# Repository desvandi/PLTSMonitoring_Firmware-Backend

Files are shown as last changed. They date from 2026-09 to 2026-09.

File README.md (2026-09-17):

# PLTS Monitoring — Firmware, Backend GAS, & Toolkit

**Firmware Version:** v1.9.3 · **Backend GAS:** WAVE-7+ · **License:** MIT
**Status:** Development (v1.9.x INA219 dynamic gain switching — hardware acceptance pending; v1.9.3 menutup REL-03/REL-04: build kini reproducible)
**Repositori kembar (PWA frontend):** [desvandi/PLTSMonitoring_PWA](https://github.com/desvandi/PLTSMonitoring_PWA)

---

## Daftar Isi

1. [Gambaran Proyek](#1-gambaran-proyek)
2. [Arsitektur Sistem](#2-arsitektur-sistem)
3. [Struktur Repositori](#3-struktur-repositori)
4. [Hardware Requirements](#4-hardware-requirements)
5. [Firmware v1.9.x — INA219 Dynamic Gain Switching](#5-firmware-v19x--ina219-dynamic-gain-switching)
6. [Panduan Deployment Lengkap](#6-panduan-deployment-lengkap)
7. [Konfigurasi Firmware](#7-konfigurasi-firmware)
8. [Backend Google Apps Script](#8-backend-google-apps-script)
9. [CI/CD Pipeline](#9-cicd-pipeline)
10. [Release Engineering](#10-release-engineering)
11. [Hardware Acceptance](#11-hardware-acceptance)
12. [Testing](#12-testing)
13. [Troubleshooting](#13-troubleshooting)
14. [Changelog](#14-changelog)

---

## 1. Gambaran Proyek

Proyek ini adalah sistem monitoring PLTS (Pembangkit Listrik Tenaga Surya) berbasis ESP32 untuk baterai 48V LiFePO4. Sistem mencakup telemetri lengkap (tegangan, arus, daya, SOC, suhu, BMS), alarm real-time, kontrol relay 8-channel, OTA update dengan signature verification, dan push notification.

### Dua Subsistem

| Subsistem | Fungsi | Komponen |
|---|---|---|
| **PLTS Monitor** (dasbor) | Telemetri → Google Apps Script → PWA Next.js; realtime MQTT opsional | `firmware/`, `firmware-generic/`, `code.gs/`, `scripts/` |
| **Push-Alarm MonitorIoT** | Alarm sensor via Web Push terenkripsi (VAPID + aes128gcm) | `push-alarm/` |

### Prinsip Inti

- **Never fabricate certainty** — setiap pengukuran membawa `value/unit/quality/source/timestamp`; sensor gagal → `null` (bukan `0`)
- **Fail-closed** — production build menolak konfigurasi tanpa signature/CA/allowlist
- **Immutable releases** — setiap release ditandatangani GPG + Ed25519, provenance binding machine-verifiable

---

## 2. Arsitektur Sistem

```
┌─────────────────────────────────────────────────────────────┐
│                     ESP32-WROOM-32                          │
│                                                             │
│  ┌──────────┐  ┌──────────┐  ┌──────────┐  ┌──────────┐   │
│  │ INA219   │  │ ADC GPIO │  │ SHT31    │  │ PCF8574  │   │
│  │ (Arus)   │  │ (Tegang) │  │ (Suhu)   │  │ (Relay)  │   │
│  └────┬─────┘  └────┬─────┘  └────┬─────┘  └────┬─────┘   │
│       │ I²C         │ ADC         │ I²C         │ I²C      │
│  ┌────┴─────────────┴─────────────┴─────────────┴────┐    │
│  │              Firmware v1.9.3                      │    │
│  │  • Dynamic PGA Switching (±80mV / ±160mV)        │    │
│  │  • Voltage Divider 190kΩ/10kΩ (20:1)             │    │
│  │  • 8-Channel Relay Controller (E-WAVE)           │    │
│  │  • Reproducible Build (deterministic identity)   │    │
│  │  • OTA Manager (Ed25519 + SHA-256)               │    │
│  │  • MQTT TLS / HTTPS telemetry                    │    │
│  └───────────────────┬──────────────────────────────┘    │
│                      │                                    │
└──────────────────────┼────────────────────────────────────┘
                       │
              ┌────────┴────────┐
              │   WiFi / MQTT   │
              └────────┬────────┘
                       │
          ┌────────────┴────────────┐
          │                         │
    ┌─────┴─────┐           ┌──────┴──────┐
    │  HTTPS    │           │   MQTT TLS  │
    │  POST     │           │  (opsional) │
    └─────┬─────┘           └──────┬──────┘
          │                        │
    ┌─────┴────────────────────────┴─────┐
    │     Google Apps Script (Backend)    │
    │  • Telemetry ingest (HMAC auth)     │
    │  • Google Sheets logging            │
    │  • Telegram alerts                 │
    │  • OTA command dispatch             │
    └─────────────┬───────────────────────┘
                  │
           ┌──────┴──────┐
           │  PWA (Vercel) │
           │  Next.js 16   │
           └───────────────┘
```

### Topologi Operasi

| Topologi | Transport | Backend | Use Case |
|---|---|---|---|
| **A (Dasbor)** | HTTPS POST | Google Apps Script + Google Sheets | Standby/standalone tanpa internet real-time |
| **B (Realtime)** | MQTT TLS | Broker MQTT + PWA subscribe | Real-time dashboard dengan live updates |

---

## 3. Struktur Repositori

```
PLTSMonitoring_Firmware-Backend/
├── firmware/                    # Modular production firmware (v1.9.3)
│   ├── Core/                    #   Config.h, Types.h, Globals.h, Common.h
│   ├── Drivers/                 #   INA219, ADC, SHT31, ACS712, PCF8574, RTC
│   ├── Services/                #   OtaManager, RelayController, AlarmRegistry, dll
│   ├── Network/                 #   MQTT transport, telemetry publisher, OTA handler
│   ├── Web/                     #   HTTP server, REST handlers (status, OTA, config, dll)
│   ├── Storage/                 #   NVS config store, filesystem
│   ├── Utils/                   #   Crypto (Ed25519), CRC, I2C recovery, JSON
│   ├── AI/                      #   GasAdvisor (HMAC-signed AI insights)
│   ├── Comm/                    #   BMS protocols (CAN, Modbus RTU/TCP)
│   ├── firmware_v1.ino          #   Main entry point
│   ├── platformio.ini           #   Build configs: development, staging, production
│   └── partitions_ota_1mb5.csv  #   OTA partition table
│
├── firmware-generic/            # Generic firmware (ESP Web Tools flashing)
│   ├── src/
│   │   └── plts_firmware_v1.ino #   Single-file firmware (same features, simpler build)
│   ├── manifest.json            #   ESP Web Tools manifest (v1.9.3)
│   ├── platformio.ini
│   └── bin/                     #   CI-built binaries (gitignored)
│
├── code.gs/                     # Google Apps Script backend
│   └── Code.gs                  #   doPost handler, telemetry ingest, HMAC, OTA dispatch
│
├── push-alarm/                  # MonitorIoT Push-Alarm subsystem
│   ├── gas/                     #   GAS Web Push core (Code.gs, WebPushCore.gs)
│   ├── firmware/                #   Alarm firmware (MonitorIoT_Firmware.ino)
│   ├── tools/                   #   VAPID key gen, deploy config, audit tools
│   └── tests/                   #   Cross-audit, smoke, webpush-core tests
│
├── scripts/                     # Release engineering + testing
│   ├── sign_firmware.py         #   Ed25519 firmware signing
│   ├── generate_provenance.py   #   Release provenance (release.json, provenance.json)
│   ├── generate_canonical_manifest.py  # Schema 2.0 OTA manifest
│   ├── generate_provenance_binding.py  # Explicit provenance chain
│   ├── release_gate.py          #   Master release gate (strict mode)
│   ├── release_firmware_generic.py    # Generic tree release builder
│   ├── verify_tag_signature.py  #   GPG tag verification (P0-1)
│   ├── verify_hardware_acceptance.py  # HW acceptance gate (P0-2)
│   ├── verify_ota_evidence.py   #   OTA physical test gate
│   ├── verify_ina219_hardware_acceptance.py  # INA219 HW acceptance (v1.9.x)
│   ├── decode_ina219_config.py  #   INA219 register decoder (canonical)
│   ├── test_ina219_config_registers.py  # INA219 register unit test
│   ├── test_*.py / test_*.js    #   30+ test scripts (unit, property, contract, bench)
│   └── ...
│
├── docs/                        #   Hanya data fungsional (dibaca skrip/CI)
│   ├── hardware-revisions.json  #     Registry revisi hardware (verify_ota_evidence dkk.)
│   ├── hardware-acceptance/     #   Evidence + template verifikasi (release gate P0-2)
│   │   ├── v1.8.0.json          #     Filled-in evidence (verdict=PASS)
│   │   ├── v1.8.0.template.json #     Template v1.8.0
│   │   ├── v1.9.2.template.json #     Template v1.9.2
│   │   └── v1.9.3.template.json #     Template v1.9.3 (REL-03: SHA byte-exact evidence)
│   └── ota-physical-test/       #   Template uji fisik OTA (verify_ota_evidence)
│       ├── v1.8.0.template.json
│       └── v1.9.3.template.json
│
├── .github/workflows/
│   └── build-firmware.yml       #   CI: test → build → sign → gate → tag-verify → hw-verify → release
│
└── README.md                    # File ini
```

---

## 4. Hardware Requirements

### Komponen Utama

| Komponen | Spesifikasi | Fungsi |
|---|---|---|
| **ESP32-WROOM-32** | Dual-core 240MHz, 4MB Flash, WiFi+BT | Mikrokontroler utama |
| **INA219** | I²C 0x40, shunt 100A/75mV (R=0.75mΩ) | Pengukuran arus baterai (1A–150A) |
| **Shunt Resistor** | 100A/75mV (0.75mΩ) | Low-side current sensing |
| **Voltage Divider** | R1=190kΩ, R2=10kΩ (ratio 20:1) + 0.1µF cap | Pembacaan tegangan baterai 42–57.5V via ADC |
| **SHT31** | I²C, ±0.3°C, ±2%RH | Suhu + kelembaban ambient |
| **PCF8574** | I²C expander 8-bit | 8-channel relay control |
| **Relay Module** | 8-channel, active-LOW optocoupler | Kontrol beban PLTS |
| **Emergency Relay** | Active-LOW, normally-closed E-stop | Safety cutoff (hardware-level) |
| **ACS712-30A** (opsional) | ADC GPIO35 | Arus AC inverter |
| **PZEM-004T** (opsional) | Modbus RTU | Meter AC presisi |

### Wiring INA219 (Low-Side Sensing)

```
Baterai (+) ──────────────────────────────────────── Beban (+)
                                              │
                                         [Divider]
                                         R1=190kΩ
                                              │
Baterai (−) ──────┬──────────────────────┬───── ADC GPIO34
                  │                      │
              [Shunt 100A]              R2=10kΩ
              75mV, 0.75mΩ               │
                  │                   [0.1µF]
                  ├──── INA219 Vin+      │
                  │                      │
                  └──── INA219 Vin−      │
                  │                      │
                 GND ────────────────────┘
```

> **Penting:** R100 (0.1Ω) bawaan modul INA219 **wajib dicopot**. Gunakan shunt eksternal 100A/75mV. INA219 dipasang low-side (jalur GND) karena Vbus bisa 57.5V > 26V max INA219.

### Pin Assignment

| GPIO | Fungsi | Modul |
|---|---|---|
| 21 | I²C SDA | INA219, SHT31, PCF8574 |
| 22 | I²C SCL | INA219, SHT31, PCF8574 |
| 34 | ADC1 CH6 | Voltage divider (input-only, WiFi-safe) |
| 35 | ADC1 CH7 | ACS712 AC current (opsional) |
| 0 | BOOT button | Factory reset trigger |
| 2 | Built-in LED | Status indicator |

---

## 5. Firmware v1.9.x — INA219 Dynamic Gain Switching

### Masalah

Rentang arus PLTS sangat lebar: 1A (standby) hingga 150A (beban puncak). Single PGA range INA219 tidak bisa cover keduanya:
- **±80mV**: saturasi di ~106A (150A × 0.75mΩ = 112.5mV > 80mV)
- **±160mV**: resolusi buruk di arus standby 1–2A

### Solusi: Dynamic PGA Switching

Firmware v1.9.2+ (termasuk v1.9.3) secara otomatis beralih PGA berdasarkan besaran arus:

| Mode | Register | PGA Range | Max Current | Resolusi |
|---|---|---|---|---|
| Standby | `0x0FFF` | ±80mV (gain /2) | 106A | 10µV/bit (0.013A) |
| Peak | `0x17FF` | ±160mV (gain /4) | 213A | 10µV/bit |

### Hysteresis

```
|I| < 90A   → ±80mV  (high-resolution standby)
|I| ≥ 100A  → ±160mV (peak load, no saturation)
```
Gap 10A mencegah chattering saat beban hover di sekitar threshold.

### INA219 Config Register (TI Datasheet SBOS448G)

```
Bit 15    : RST (1 = reset)
Bit 14    : RESERVED (must be 0)
Bit 13    : BRNG (0 = 16V FSR, 1 = 32V FSR)
Bits 12:11: PG (00=±40mV, 01=±80mV, 10=±160mV, 11=±320mV)
Bits 10:7 : BADC (4-bit, 1111 = 12-bit/128-sample/68ms)
Bits 6:3  : SADC (4-bit, 1111 = 12-bit/128-sample/68ms)
Bits 2:0  : MODE (111 = shunt+bus continuous)
```

### Safety Features

1. **Register readback verification** — setiap PGA switch diverifikasi via I²C readback
2. **Sample discard** — sample pertama setelah PGA switch dibuang (settling time 68ms)
3. **Saturation detection** — di ±80mV mode, jika shunt > 78mV → emergency switch ke ±160mV
4. **pga_mode telemetry** — field `bat.pgaMode` ("80mV"/"160mV") dikirim ke backend + PWA

### Verifikasi Register

```bash
python3 scripts/decode_ina219_config.py 0x0FFF 0x17FF
python3 scripts/test_ina219_config_registers.py
```

---

## 6. Panduan Deployment Lengkap

### Prasyarat

- **PlatformIO Core** 6.1.18+ (`pip install platformio`)
- **Python** 3.11+ (untuk scripts)
- **Git** dengan GPG signing configured
- **Google Account** (untuk Apps Script + Sheets)
- **Vercel Account** (untuk PWA deployment — lihat repo PWA)

### Langkah 1: Clone Repositori

```bash
git clone https://github.com/desvandi/PLTSMonitoring_Firmware-Backend.git
cd PLTSMonitoring_Firmware-Backend
```

### Langkah 2: Build Firmware

#### Opsi A: Modular Production (Recommended)

```bash
cd firmware

# Set production secrets (WAJIB sebelum build production)
export MQTT_BROKER_HOST="your-broker.example.com"
export MQTT_BROKER_PORT="8883"
export MQTT_USERNAME="plts-device"
export MQTT_PASSWORD="your-password"
export MQTT_ROOT_CA="$(cat roots.pem)"
export OTA_ED25519_PUBLIC_KEY_HEX="your-64-hex-char-public-key"
export OTA_HTTPS_ROOT_CA="$(cat ota-ca.pem)"

# Build
pio run -e production

# Output: .pio/build/production/firmware.bin
```

#### Opsi B: Development (tanpa secrets)

```bash
cd firmware
pio run -e development
```

#### Opsi C: Generic (ESP Web Tools browser flashing)

```bash
cd firmware-generic
pio run -e esp32dev
# Output: bin/plts_firmware_v1.9.3.bin
```

### Langkah 3: Sign Firmware (Ed25519)

```bash
# Generate keypair (sekali saja)
python3 scripts/sign_firmware.py --gen-keys
# Output: firmware_signing_private.pem + firmware_signing_public.pem

# Sign binary
python3 scripts/sign_firmware.py --sign .pio/build/production/firmware.bin
# Output: firmware.bin.sig (128 hex chars = 64 bytes Ed25519)

# Verify
python3 scripts/sign_firmware.py --verify firmware.bin.sig firmware.bin
```

### Langkah 4: Flash ke ESP32

#### Via USB (PlatformIO)

```bash
cd firmware
pio run -e production -t upload
# Monitor:
pio device monitor -b 115200
```

#### Via ESP Web Tools (Browser)

1. Host `firmware-generic/bin/` di web server (GitHub Pages, Vercel, dll)
2. Buka PWA → Setup → "Install Firmware" button
3. Browser akan flash via Web Serial API

### Langkah 5: Deploy Backend Google Apps Script

1. Buka [script.google.com](https://script.google.com) → New Project
2. Copy seluruh isi `code.gs/Code.gs` ke editor
3. Buat Google Sheet baru, copy ID dari URL
4. Di Apps Script, jalankan `setupMasterTemplate()` (Run → function)
5. Set `AUTH_TOKEN` di Config sheet (minimal 16 karakter, tidak boleh "CHANGE_ME")
6. Deploy → New Deployment → Web App
   - Execute as: Me
   - Who has access: Anyone
7. Copy Web App URL → simpan untuk konfigurasi PWA

### Langkah 6: Generate OTA Signing Keys

```bash
# Generate Ed25519 keypair untuk OTA
python3 scripts/sign_firmware.py --gen-keys

# Public key hex (untuk firmware Config.h / OTA_ED25519_PUBLIC_KEY_HEX)
xxd -p -c 64 firmware_signing_public.pem | head -1
# Atau:
python3 -c "
from cryptography.hazmat.primitives import serialization
key = open('firmware_signing_public.pem','rb').read()
pub = serialization.load_pem_public_key(key)
raw = pub.public_bytes(serialization.Encoding.Raw, serialization.PublicFormat.Raw)
print(raw.hex())
"
```

### Langkah 7: Konfigurasi ESP32 (via PWA)

1. Buka PWA di browser (deploy dari repo PWA)
2. Hubungkan ke WiFi AP ESP32 ("PLTS-Setup-XXXX")
3. PWA akan redirect ke setup page
4. Isi: WiFi SSID+password, GAS URL, AUTH_TOKEN, MQTT broker (opsional)
5. Submit → ESP32 reboot → connect ke WiFi

### Langkah 8: Verifikasi

1. Buka Serial Monitor: `pio device monitor -b 115200`
2. Verifikasi log INA219:
   ```
   [INA219 0x40] config readback OK: 0x0FFF (BRNG=0 16V, PGA=1 ±80mV, BADC=15, SADC=15, MODE=7)
   [INA219 0x40] init: shunt=0.7500 mΩ, cal=0x..., sign=-1.0, pga=80mV
   ```
3. Buka PWA → verifikasi telemetri muncul
4. Cek Google Sheet → data telemetri masuk

---

## 7. Konfigurasi Firmware

### Environment Variables (Production Build)

| Variable | Wajib | Description |
|---|---|---|
| `MQTT_BROKER_HOST` | Ya | MQTT broker hostname |
| `MQTT_BROKER_PORT` | Ya | MQTT port (8883 untuk TLS) |
| `MQTT_USERNAME` | Ya | MQTT username |
| `MQTT_PASSWORD` | Ya | MQTT password |
| `MQTT_ROOT_CA` | Ya | PEM-encoded Root CA untuk TLS |
| `OTA_ED25519_PUBLIC_KEY_HEX` | Ya | 64 hex char Ed25519 public key |
| `OTA_HTTPS_ROOT_CA` | Ya | PEM Root CA untuk HTTPS OTA download |

### Runtime Config (via PWA / NVS)

| Config | Default | Description |
|---|---|---|
| `deviceName` | "PLTS-XXXX" | Nama device |
| `siteName` | "Site" | Nama lokasi |
| `idleCurrentThreshold` | 0.5A | Deadband arus idle |
| `cfgBmsProtocol` | "auto" | Protokol BMS (auto/CAN/Modbus) |

### INA219 Constants (`firmware/Core/Config.h`)

```cpp
static constexpr float    INA219_SHUNT_OHM          = 0.00075f;   // 0.75 mΩ
static constexpr float    INA219_PGA_SWITCH_UP_A    = 100.0f;     // switch to 160mV
static constexpr float    INA219_PGA_SWITCH_DOWN_A  = 90.0f;      // switch back to 80mV
static constexpr uint16_t INA219_CONFIG_PGA_80MV   = 0x0FFF;     // ±80mV, 12b/128s, cont
static constexpr uint16_t INA219_CONFIG_PGA_160MV  = 0x17FF;     // ±160mV, 12b/128s, cont
```

### Voltage Divider Constants

```cpp
static constexpr float DIVIDER_R1       = 190000.0f;  // 190 kΩ
static constexpr float DIVIDER_R2       = 10000.0f;   // 10 kΩ
static constexpr float DIVIDER_RATIO    = 20.0f;      // (R1+R2)/R2
static constexpr float ADC_FINE_TUNE    = 1.000000f;  // kalibrasi multimeter
```

---

## 8. Backend Google Apps Script

### Struktur `code.gs/Code.gs`

| Function | Fungsi |
|---|---|
| `doPost(e)` | Entry point — parse JSON, HMAC auth, route action |
| `recordTelemetry_(body, deviceKey)` | Simpan telemetri ke Google Sheets |
| `latestTelemetry_(deviceKey)` | Baca telemetri terbaru |
| `otaGetManifest_(deviceKey)` | Serve OTA manifest ke device |
| `otaPublish_(body, deviceKey)` | Publish OTA command ke device |
| `emergencyCommand_(body, deviceKey)` | Dispatch emergency command |
| `setupMasterTemplate()` | Inisialisasi sheets + config (run sekali) |

### Google Sheets Schema

| Column | Field | Type |
|---|---|---|
| 0 | timestamp | DateTime (server) |
| 1 | device_key | String |
| 2 | sequence | Integer |
| 3 | event_time | DateTime (device) |
| 5 | v_bat | Float |
| 6 | i_bat_dc | Float |
| 7 | p_bat_dc | Float |
| 8 | soc | Float |
| ... | ... | ... |
| 39 | ina219_pga_mode | String ("80mV"/"160mV"/"") |

### HMAC Authentication

```
Authorization: HMAC <deviceKey>:<base64(HMAC-SHA256(authToken, canonicalString))>
```

---

## 9. CI/CD Pipeline

### Workflow: `.github/workflows/build-firmware.yml`

```
push/PR to main → [test] → [build-staging] → [build-generic-tree] → [build-production]
                                                                          ↓
                                                              [release-gate]
                                                                          ↓
                                                          [verify-tag-signature] (tag push only)
                                                                          ↓
                                                      [verify-hardware-acceptance] (tag push only)
                                                                          ↓
                                                          [release-publish] (tag push only)
```

### Jobs

| Job | Trigger | Fungsi |
|-----|---|---|
| Python tests | All pushes | 30+ unit/property/contract tests |
| Build staging | All pushes | PlatformIO staging env |
| Build generic | All pushes | PlatformIO generic tree |
| Build production | All pushes | PlatformIO production env (signed) |
| Reproducible build 2x | All pushes | REL-04: build A vs clean build B — SHA harus byte-identical (modular + generic) |
| Release gate | All pushes | Strict invariant check |
| Verify tag signature | Tag push (v*) | GPG tag + authorized signer verification |
| Verify HW acceptance | Tag push (v*) | Hardware acceptance JSON gate |
| Release publish | Tag push (v*) | Create GitHub Release with 20+ assets (requires reproducible-build PASS) |

### Branch Protection

- `main`: PR required, 0 approvals, 4 required status checks
- Tags `v*`: deletion + non-fast-forward + creation blocked

---

## 10. Release Engineering

### Release Chain

```
source → build → sign (Ed25519) → gate → tag-verify (GPG) → hw-verify → release
```

### GPG Tag Signing

```bash
# Generate GPG key (RSA 4096)
gpg --full-generate-key

# Configure git
git config --global user.signingkey <KEY_ID>
git config --global tag.gpgsign true

# Sign release tag
git tag -s -a v1.9.2 -m "Release v1.9.2 — INA219 dynamic gain (canonical fix)"
```

### Provenance Binding

Setiap release menyertakan `provenance-binding.json` yang mengikat:
```
tag → signed tag object → release commit → source commit
→ hardware-tested binary SHA → released binary SHA
→ GitHub Release → PWA canonical release identity
```

### Release Assets (20 files)

| Asset | Description |
|---|---|
| `modular-firmware.bin` | Modular production firmware (signed) |
| `modular-firmware.bin.sig` | Ed25519 signature |
| `modular-firmware.bin.sha256` | SHA-256 hash |
| `modular-release.json` | Release metadata |
| `modular-provenance.json` | Build provenance |
| `modular-manifest-canonical.json` | Schema 2.0 OTA manifest |
| `generic-*.bin` | Generic tree binaries |
| `hardware-acceptance.json` | Physical test evidence |
| `provenance-binding.json` | Explicit provenance chain |

---

## 11. Hardware Acceptance

### General Hardware Acceptance (v1.8.0+)

Protocol 11-criteria: boot, sensors, alarms, OTA REST, OTA MQTT, rollback, emergency relay, config persistence, security, 24h soak, factory reset.

```bash
python3 scripts/verify_hardware_acceptance.py \
  --version 1.8.0 \
  --source-commit <SHA> \
  --release-json modular-release.json \
  --hw-dir docs/hardware-acceptance
```

### INA219 Hardware Acceptance (v1.9.2/v1.9.3)

Protocol 12-criteria khusus INA219: config readback, low/mid/peak current accuracy, PGA transitions, hysteresis, current sign, voltage divider, power calculation, telemetry pga_mode. Gunakan `v1.9.3.md` untuk release line v1.9.3 (measurement chain identik dengan v1.9.2; bukti SHA kini byte-exact karena build reproducible).

```bash
python3 scripts/verify_ina219_hardware_acceptance.py \
  --version 1.9.3 \
  --source-commit <SHA> \
  --release-json modular-release.json \
  --hw-dir docs/hardware-acceptance
```

### OTA Physical Test (v1.8.0+)

Protocol 16-criteria: PWA → GitHub Release → download → SHA verify → upload → device flash → reboot → version check → relay safe state → rollback.

```bash
python3 scripts/verify_ota_evidence.py \
  --version 1.8.0 \
  --canonical-release-json modular-release.json \
  --ota-dir docs/ota-physical-test
```

---

## 12. Testing

### Run All Tests

```bash
# Python unit + property tests
python3 scripts/test_ina219_config_registers.py
python3 scripts/test_version_identity.py
python3 scripts/test_voltage_calibration.py
python3 scripts/test_soc_calculation.py
python3 scripts/test_emergency_firmware_logic.py
# ... 30+ test scripts

# JavaScript tests
node scripts/test_wave1_integration.js
node scripts/test_wave2_data_honesty.js
node scripts/test_gas_contract.js
```

### Key Test Scripts

| Script | Fungsi |
|---|---|
| `test_ina219_config_registers.py` | Verifikasi PGA register constants per datasheet |
| `test_version_identity.py` | Version parity antara modular + generic + manifest |
| `test_wave12_contract_regression.py` | Cross-layer contract regression |
| `test_ed25519_interop.py` | Ed25519 signature interop (Python ↔ firmware) |
| `release_gate.py` | Master release gate (strict mode) |

---

## 13. Troubleshooting

### INA219: "config MISMATCH" di Serial Monitor

**Penyebab:** I²C write gagal atau register constant salah.

**Fix:**
1. Cek wiring I²C (SDA=GPIO21, SCL=GPIO22, pull-up 4.7kΩ)
2. Verifikasi constant: `python3 scripts/test_ina219_config_registers.py`
3. Jika constant benar tapi readback gagal → ganti modul INA219

### INA219: Arus terbaca 0A / NaN

**Penyebab:** R100 bawaan modul belum dicopot, atau shunt belum terpasang.

**Fix:**
1. Lepas R100 (0.1Ω) dari modul INA219
2. Pasang shunt 100A/75mV di jalur GND
3. Verifikasi: VIN+ dan VIN− terhubung ke baut shunt

### Voltage Divider: Tegangan tidak akurat

**Penyebab:** Toleransi resistor ±5% → error hingga ±2V di 57.5V.

**Fix:**
1. Ukur tegangan aktual dengan multimeter
2. Hitung `ADC_FINE_TUNE = tegangan_aktual / tegangan_PWA`
3. Update di `Config.h`: `static constexpr float ADC_FINE_TUNE = 1.004016f;`
4. Rebuild + reflash

### OTA: "signature header missing (PRODUCTION)"

**Penyebab:** PWA tidak mengirim header `X-Signature`.

**Fix:** Update PWA ke versi terbaru (commit `9c8510a`+) yang mengirim `X-Expected-SHA256`, `X-Signature`, `X-Firmware-Version`.

### MQTT: "TLS connection failed"

**Penyebab:** Root CA tidak ter-set atau broker tidak support TLS.

**Fix:**
1. Set `MQTT_ROOT_CA` environment variable sebelum build
2. Verifikasi broker menggunakan port 8883 (TLS) atau 8884 (TLS+auth)
3. Test: `openssl s_client -connect broker:8883 -showcerts`

---

## 14. Changelog

### v1.9.3 (Current)
- **Reproducible build (REL-03/REL-04 CLOSED)** — `FIRMWARE_BUILD_DATE` tidak lagi `__DATE__`/`__TIME__` (wall-clock); kini diturunkan dari `SOURCE_DATE_EPOCH` (timestamp commit HEAD git) via `firmware/scripts/set_build_date.py`. Dua build dari source yang sama = SHA-256 identik.
- **CI job `reproducible-build`** — build 2× (modular production + generic) dari clean tree, compare SHA; `release-publish` kini mewajibkan job ini (release tak bisa dipublish tanpa bukti determinisme).
- **buildDate semantics** — `/api/version` `buildDate` kini melaporkan tanggal SOURCE commit (identitas provenance), bukan wall-clock kompilasi.
- **HW acceptance v1.9.3 protocol** — template `docs/hardware-acceptance/v1.9.3.template.json` (12 kriteria sama dengan v1.9.2; evidence `firmwareSha256` kini byte-exact vs released binary).
- **Version parity** — 1.9.3 di modular (Config.h) + generic (plts_firmware_v1.ino + manifest.json) + mirror PWA (`public/firmware/manifest.json`).
- Tidak ada perubahan measurement chain — INA219 PGA 0x0FFF/0x17FF, hysteresis 90A/100A, voltage divider 190k/10k, pga_mode telemetry: semuanya identik dengan v1.9.2.

### v1.9.2
- **INA219 dynamic gain switching** — PGA ±80mV/±160mV dengan hysteresis 90A/100A
- **Canonical register fix** — constants 0x0FFF/0x17FF per TI datasheet SBOS448G
- **Register readback verification** — setiap PGA switch diverifikasi via I²C readback
- **Sample discard** — sample pertama setelah PGA switch dibuang (settling time)
- **Voltage divider 190kΩ/10kΩ** (20:1 ratio) untuk tegangan baterai 42–57.5V
- **pga_mode telemetry** — field `bat.pgaMode` ("80mV"/"160mV") di JSON payload
- **CURRENT_SPIKE_REJECT_A** raised 120A → 160A (software ceiling, NOT hardware rating)
- **Mandatory measurement evidence** — 17 field observed wajib diisi di HW acceptance

### v1.8.0
- **8-channel relay integration** via PCF8574 I²C expander
- **RelayController** with safety supervisor (maxOnTime, minOnTime, antiChatter)
- **5-state lockout** (NORMAL→TRIPPED→ACKNOWLEDGED→CLEARED→ARMED)
- **Interlock engine** (mutual exclusion + dead time)
- **E-WAVE safety cascade** (trip → all relay channels OFF)
- **REST API**: `/api/relays`, `/api/relays/{id}/{on|off|pulse}`, `/api/relays/all_off`
- **PWA relay control view** with 3-tier state model

### v1.7.x
- OTA boot-health fix (`esp_ota_mark_app_valid_cancel_rollback`)
- Mixed-fleet manifest target self-check
- PZEM-004T real AC meter support
- Emergency relay + E-stop sense
- 2nd ACS712 channel (genset→inverter)
- Cross-layer contract regression tests (WAVE 7-13)

### v1.6.x
- External BMS/inverter comm (CAN, Modbus RTU/TCP)
- SOC provenance (BMS_DIRECT | SHUNT_COULOMB | OCV_ESTIMATED)
- Transaction journal for command dedup
- I²C bus recovery (NOISE-3)

---

## License

MIT — see [LICENSE](LICENSE)

## Kontak

- **GitHub Issues:** [github.com/desvandi/PLTSMonitoring_Firmware-Backend/issues](https://github.com/desvandi/PLTSMonitoring_Firmware-Backend/issues)
- **PWA Repo:** [github.com/desvandi/PLTSMonitoring_PWA](https://github.com/desvandi/PLTSMonitoring_PWA)

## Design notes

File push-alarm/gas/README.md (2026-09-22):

# push-alarm/gas/ — [FROZEN] Duplikat GAS Paralel (keputusan paritas menunggu)

> Status registry: **frozen** (2026-09-22) — lihat
> `docs/surface-governance/SURFACE-STATUS.json`, surface id
> `push-alarm-gas-duplicate`.
> Seluruh berkas di direktori ini dibekukan via content pin SHA-256 dan
> dijaga oleh `scripts/check_surface_policy.py` + job CI
> `surface-policy-gate`.

## Mengapa dibekukan (bukan dihapus)

Direktori ini berisi implementasi GAS kedua (`Code.gs` 1.352 baris +
`WebPushCore.gs` primitif kripto SHA-256/HMAC/HKDF) yang berjalan
**paralel** dengan backend GAS kanonik `code.gs/` (2.878 baris) di
root repo yang sama. Keduanya BUKAN salinan identik (md5 berbeda,
kontrak berbeda): `code.gs/` membawa kontrak identitas
`(device_key, sequence)` [P1-001..004] + autentikasi HMAC-SHA256 v2.1,
sedangkan salinan ini tidak membawa penanda tersebut yang dapat
diverifikasi.

Risiko yang dijaga: perbaikan keamanan yang mendarat di `code.gs/`
(revokasi token, anti-replay nonce, ledger gap) **tidak otomatis**
menyebar ke salinan ini — dan sebaliknya. Dua backend GAS aktif yang
diverifikasi berbeda = permukaan serangan yang tidak dapat diaudit
sebagai satu sistem.

## Keputusan terbuka (pemilik repo)

Pilih SATU dan catat di `docs/surface-governance/SURFACES.md`:

1. **Pensiunkan** salinan ini → status berubah `deprecated`, fleet yang
   menunjuk ke deployment GAS ini dimigrasikan ke `code.gs/`, lalu
   direktori dihapus pada rilis minor berikutnya.
2. **Promosikan jadi kanonik** (jika deployment GAS push-alarm memang
   jalur produksi) → naikkan kontrak P1-00x + HMAC v2.1 ke sini, status
   berubah `active`, dan `code.gs/` yang harus diputuskan.

Sampai keputusan dibuat: tidak ada perubahan konten — pin SHA-256
menolak modifikasi apa pun tanpa pembaruan pin eksplisit di registry.

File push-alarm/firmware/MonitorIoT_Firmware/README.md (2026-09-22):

# MonitorIoT_Firmware — [DEPRECATED] Permukaan Legacy

> Status registry: **deprecated** (2026-09-22) — lihat
> `docs/surface-governance/SURFACE-STATUS.json`, surface id
> `push-alarm-firmware-monitoriot`.
> Seluruh berkas di direktori ini dibekukan via content pin SHA-256 dan
> dijaga oleh `scripts/check_surface_policy.py` + job CI
> `surface-policy-gate`. Modifikasi senyap ditolak fail-closed.

## Mengapa dibekukan

Direktori ini adalah firmware ekosistem **MonitorIoT (greenhouse)** —
garis keturunan tertua yang berjalan paralel dengan jalur PLTS aktif.
Ketika sebuah perbaikan keamanan mendarat di `code.gs/`,
`firmware-generic/`, atau `firmware/`, perbaikan itu **tidak sampai** ke
sini. Sudut keamanan yang tidak dimiliki permukaan ini:

| Kemampuan | code.gs/ (aktif) | firmware-generic/ (aktif) | MonitorIoT (ini) |
|---|---|---|---|
| Identitas (device_key, sequence) + ledger gap [P1-00x] | ya | ya | **tidak** |
| Autentikasi HMAC-SHA256 kontrak v2.1 | ya | — (token+device_key) | **tidak** |
| OTA bertanda-tangan Ed25519 + rollback otomatis | ya (sisi GAS) | ya | **tidak** |
| Pinning TLS root CA (GTS R1+R4) | — | ya (GAS_ROOT_CA) | ya (v1.1.0) |
| Verifikasi tulis NVS read-back [FW6-6] | — | ya | **tidak** |

Placeholder kredensial (`GANTI_PASSWORD_WIFI`, `AKfycbxGANTI_DENGAN_ID_…`)
menandakan basis kode contoh, bukan jalur produksi.

## Jalur migrasi

- Telemetri ke GAS PLTS → `firmware-generic/` (kontrak TELEMETRY v2,
  identitas `(device_key, sequence)`, OTA bertanda-tangan).
- Dashboard lokal REST + MQTT → `firmware/` (auth web + CSRF + transaksi
  relay).
- Keputusan pensiun final (hapus direktori) menunggu konfirmasi bahwa
  tidak ada fleet greenhouse yang masih flash build dari sini —
  lihat `docs/surface-governance/SURFACES.md` §Keputusan Terbuka.

## Jika benar-benar harus mengubah berkas ini

1. Buka/tulis issue dengan alasan + tinjauan keamanan.
2. Perbarui content pin berkas di
   `docs/surface-governance/SURFACE-STATUS.json` pada PR yang sama
   (perubahan pin = tanda tangan eksplisit reviewer, terlihat di diff).
3. CI `surface-policy-gate` akan tetap gagal untuk penambahan berkas baru
   yang tidak terdaftar — daftarkan juga berkas baru di registry.

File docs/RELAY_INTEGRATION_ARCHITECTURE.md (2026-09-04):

# RELAY_INTEGRATION_ARCHITECTURE.md

> **PHASE 0 output — mandatory before any relay code is written.**
> This document maps the CURRENT architecture, identifies the integration
> point for 8-channel relay, and defines the NEW relay control path with
> safety, persistence, and network boundaries.

## 1. CURRENT ARCHITECTURE

### 1.1 Firmware (ESP32)

**FreeRTOS tasks (11):** sensor(5Hz), measure(5Hz), energy(1Hz), telemetry(5s),
network(100ms), persist(5min), health(1Hz), ota(2Hz), bmscomm(100ms),
emg(10Hz), gasemg(15s poll). All WDT-subscribed.

**GPIO usage (definitive):**

| GPIO | Role | Owner |
|---|---|---|
| 2 | E-WAVE LED (OUTPUT) | EmergencySupervisor |
| 4 | RS485 DE (OUTPUT) | ModbusRtuClient |
| 14 | E-WAVE E-stop (INPUT_PULLUP) | EmergencyRelayDriver |
| 16/17 | RS485 TX/RX (UART2) | ModbusRtuClient |
| 18/19 | PZEM RX/TX (UART1, optional) | Pzem004tDriver |
| 21/22 | I²C SDA/SCL | INA219 + SHT31 + DS3231 |
| 25/26 | CAN TX/RX (TWAI) | PylontechCanClient |
| 27 | E-WAVE relay (OUTPUT, active-LOW) | EmergencyRelayDriver |
| 32 | Reserved for future genset ACS712 | — |
| 34/35 | Battery ADC / ACS712 ADC (input-only) | AdcVoltageDriver / Acs712Driver |

**Free safe GPIOs:** 13, 23, 33 (only 3 — NOT enough for 8 direct relays).

**Existing actuator:** E-WAVE emergency relay (GPIO 27, active-LOW, fail-safe).
This is a SAFETY INTERLOCK, NOT a general-purpose actuator. It CANNOT be
extended to 8 channels (binary state machine, single relay, safety-isolated).

**Command pipeline (existing, reusable):**
```
REST/MQTT → auth → CSRF → freshness → CommandCanonicalizer (whitelist+hash)
→ TransactionJournal (decide: NEW/DUPLICATE/CONFLICT) → apply → journal ACK
```

**TransactionJournal:** 16-slot NVS ring, 2-phase commit, CRC32, survives reboot.
**CommandCanonicalizer:** whitelist (fail-closed), SHA-256 hash, cross-transport
dedup (REST + MQTT produce identical hash for same command).

### 1.2 PWA (Next.js)

**Stack:** Next.js 16, React 19, TanStack Query v5, Zustand, mqtt.js, Serwist.

**API split:** `deviceApi.ts` (ESP32 REST) + `backendApi.ts` (GAS aggregation)
+ `apiShared.ts` (CSRF, requestId). `api.ts` is backward-compat façade.

**MQTT:** subscribe-only (status/log/online). NO publish path — commands go via REST.

**Auth:** JWT cookie + CSRF double-submit + JTI revocation. Role: viewer | operator.

**Emergency control (E-WAVE):** browser POSTs directly to GAS Web App URL
(admin_token in body). NO requestId. NO CSRF. This is a SEPARATE command path
from deviceApi REST mutations.

**Compatibility:** `canViewTelemetry` gate exists. NO `canControlRelays` yet.

**Command state model:** NONE (generic). Emergency uses timing-based refresh
(setTimeout 4s+16s). No PENDING/CONFIRMED/FAILED/UNKNOWN tracking.

### 1.3 GAS (Code.gs)

**Actions:** TELEMETRY, PING, OTA_*, CALIBRATION_*, EMERGENCY_*, SEQ_STATUS.
HMAC-SHA256 auth. No relay control actions exist.

---

## 2. RELAY INTEGRATION POINT

### 2.1 Decision: Separate subsystem (NOT E-WAVE extension)

The E-WAVE emergency layer is a safety interlock. It CANNOT be extended:
- Binary state (Run/Emergency) vs 8 independent channels
- Safety-isolated (no REST/MQTT surface) vs operator-controlled
- Single relay fail-safe contract vs multi-channel general purpose

**Architecture:** Build a NEW `RelayController` subsystem. Reuse E-WAVE
*patterns* (driver/supervisor separation, fail-safe pin contract, NVS config)
but NOT its code. E-WAVE stays unchanged.

### 2.2 Hardware: I²C expander (PCF8574)

Only 3 free safe GPIOs (13/23/33) — insufficient for 8 direct relays.
**Decision: PCF8574 I²C expander** (8 channels, address 0x20-0x27, shares
SDA/SCL at 21/22). Zero GPIO overlap with existing pins.

Alternative considered: MCP23017 (16-ch, more features), 74HC595 (shift
register, no readback). PCF8574 chosen for simplicity + I²C readback capability.

### 2.3 Integration points (firmware)

| Layer | File | Change |
|---|---|---|
| Driver | `Drivers/RelayExpanderDriver.{h,cpp}` (NEW) | PCF8574 I²C, fail-safe OFF at boot, setChannel() |
| Service | `Services/RelayController.{h,cpp}` (NEW) | State machine, applyCommand(), tick(), publishStatus() |
| Safety | `Services/RelaySafety.{h,cpp}` (NEW) | maxOnTime, minOnTime, antiChatter, lockout 5-state |
| Interlock | `Services/RelayInterlock.{h,cpp}` (NEW) | Mutual exclusion groups, dead time |
| Config | `Storage/ConfigStore.{h,cpp}` (EDIT) | loadRelayConfig/saveRelayConfig (NVS `plts_relays`) |
| Command | `Services/CommandCanonicalizer.cpp` (EDIT) | Add `relay.*` to whitelist |
| MQTT | `Network/MqttConfigReceiver.cpp` (EDIT) | Add `relay.*` dispatch |
| REST | `Web/RelayHandlers.{h,cpp}` (NEW) | GET/POST /api/relays/* |
| Telemetry | `Web/BatteryStatusSerializer.h` (EDIT) | Add `relays[]` block |
| Types | `Core/Types.h` (EDIT) | RelayState, RelayMode, TaskId::Relay, alarm codes |
| Config | `Core/Config.h` (EDIT) | PLTS_ENABLE_RELAYS, PCF8574 addr, channel count |
| Main | `firmware_v1.ino` (EDIT) | relayTask, relaysController.begin() |
| Safety cascade | `Services/EmergencySupervisor.cpp` (EDIT) | _trip() → relaysController.emergencyAllOff() |

### 2.4 Integration points (PWA)

| Layer | File | Change |
|---|---|---|
| Types | `src/lib/types.ts` (EDIT) | RelayChannelStatus, RelayCommandState, RelayConfig |
| Command | `src/lib/relays.ts` (NEW) | sendRelayCommand(), fetchRelayStatus(), config schema |
| Hooks | `src/hooks/useRelays.ts` (NEW) | useRelayStatus(), useRelayCommand() |
| State | `src/lib/relayCommandStore.ts` (NEW) | Map<requestId, state> with expiry |
| API | `src/lib/deviceApi.ts` (EDIT) | Add relay endpoints |
| Compat | `src/lib/compatibility.ts` (EDIT) | canControlRelays flag |
| View | `src/components/relays/` (NEW) | relay-control-view, channel-card, config-panel |
| Nav | `src/lib/store.ts` + `app-shell.tsx` (EDIT) | Add 'relays' ViewKey + nav item |
| Routes | `src/app/api/relays/` (NEW) | REST proxy routes |

---

## 3. NEW RELAY CONTROL PATH

```
     REST POST /api/relays/{id}/on
     MQTT plts/{dev}/command  (relay.set)
              ↓               ↓
         ┌─────────────────────┐
         │ Command Normalizer  │  (inject type="relay", action="on")
         └─────────┬───────────┘
                   ↓
         ┌─────────────────────┐
         │ Auth + CSRF         │  (JWT + double-submit)
         └─────────┬───────────┘
                   ↓
         ┌─────────────────────┐
         │ Freshness Gate      │  (expiresAt check)
         └─────────┬───────────┘
                   ↓
         ┌─────────────────────┐
         │ CommandCanonicalizer│  (whitelist + SHA-256 hash)
         └─────────┬───────────┘
                   ↓
         ┌─────────────────────┐
         │ TransactionJournal  │  (NEW/DUPLICATE/CONFLICT)
         └─────────┬───────────┘
                   ↓
         ┌─────────────────────┐
         │ RelayController     │  (applyCommand)
         │   .applyCommand()   │
         └─────────┬───────────┘
                   ↓
         ┌─────────────────────┐
         │ RelaySafety         │  (maxOnTime, lockout, antiChatter)
         │   .evaluate()       │
         └─────────┬───────────┘
                   ↓
         ┌─────────────────────┐
         │ RelayInterlock      │  (mutual exclusion, dead time)
         │   .evaluate()       │
         └─────────┬───────────┘
                   ↓
         ┌─────────────────────┐
         │ RelayEngine         │  SINGLE GPIO MUTATION PATH
         │   .applyChannelState│  ( RelayExpanderDriver.setChannel()
         └─────────┬───────────┘    → PCF8574 → I²C → GPIO )
                   ↓
         ┌─────────────────────┐
         │ Persist ACK         │  (journal.storeTransaction)
         └─────────┬───────────┘
                   ↓
              ACK to caller
```

**NO BYPASS:** MQTT, REST, Scheduler, Safety, PIR — ALL go through
CommandArbiter → RelayEngine → RelayExpanderDriver → GPIO.
No direct digitalWrite() from any subsystem.

---

## 4. SAFETY BOUNDARY

### 4.1 Boot safety
- `RelayExpanderDriver::begin()` drives ALL channels OFF BEFORE any other
  init (mirror E-WAVE pattern). PCF8574 power-on state is all-HIGH (OFF for
  active-LOW relay modules). Firmware re-asserts OFF immediately.
- Boot policy per channel: `BootOff` (default, hazardous loads) |
  `RestoreLast` (non-hazardous). NO `BootOn` — too dangerous without
  physical verification.

### 4.2 Safety supervisor (per-channel)
- `maxOnTimeSec`: 0=unlimited; >0 = FORCE OFF after N seconds
- `minOnTimeSec`: inhibit OFF before N seconds (protect inductive loads)
- `minOffTimeSec`: inhibit ON before N seconds (cooling)
- `minSwitchIntervalSec`: anti-chatter (min seconds between transitions)
- **FORCE OFF cannot be bypassed** by REST, MQTT, PWA, or Scheduler

### 4.3 Lockout state machine (5-state, NVS-persisted)
```
NORMAL → TRIPPED → ACKNOWLEDGED → CLEARED → ARMED → NORMAL
```
- ACK = operator has seen alarm (NOT permission to re-enable)
- CLEAR requires fault condition resolved
- NVS persistence prevents bypass via power-cycle

### 4.4 E-WAVE safety cascade (one-way gate)
```
EmergencySupervisor::_trip()
  → emergencyRelay.setEnergized(false)   // E-WAVE relay ISOLATED
  → relaysController.emergencyAllOff()    // 8-channel cascade (OPTIONAL)
```
Reverse (RelayController → EmergencySupervisor) is FORBIDDEN.

### 4.5 Interlock
- Declarative groups: MutualExclusion + dead time
- Example: Relay 1 (GRID) + Relay 2 (GENSET) = mutual exclusion
- OFF → dead time → ON (prevents arc short)
- Applies to ALL sources (MANUAL, SCHEDULE, MQTT, REST, AUTOMATION)

---

## 5. PERSISTENCE BOUNDARY

### 5.1 What is persistent (NVS namespace `plts_relays`)

| Data | Persistent? | Why |
|---|---|-----|
| Channel config (name, pin, mode, safety limits) | YES | Operator configuration survives reboot |
| Safety lockout state (5-state per channel) | YES | Prevent bypass via power-cycle |
| maxOnTimeForced flag | YES | Force-OFF survives reboot |
| Command sequence (per-channel monotonic) | YES | Stale detection survives reboot |
| Transaction journal (16-slot ring) | YES (existing `plts_txn`) | Cross-channel dedup |
| **desiredState** | NO (RAM only) | Boot policy decides, not last desired |
| **reportedState** | NO (RAM only) | Recomputed on boot via boot policy |
| relayStateSequence | NO (RAM only) | Reset on boot |

### 5.2 Transaction durability boundary
```
Receive command → validate → auth → canonicalize → journal.decide()
  → IF NEW: persist intent (journal valid=0)
  → applyCommand (physical mutation via RelayEngine)
  → persist result (journal valid=1, store ACK)
  → return ACK
```
Crash between persist-intent and persist-result → journal has valid=0
→ on reboot, entry is discarded → command is lost (safe direction: relay
stays in pre-command state, operator retries).

### 5.3 Boot recovery
1. Load `plts_relays` config (channel names, safety limits, lockout states)
2. Restore maxOnTimeForced for TRIPPED/ACKNOWLEDGED channels
3. Apply boot policy (BootOff default → all OFF)
4. Load command sequence (stale detection)
5. RelayExpanderDriver::begin() (I²C init, all OFF)
6. RelayController::begin() (apply boot policy)

---

## 6. NETWORK BOUNDARY

### 6.1 Offline-first
Relay control works WITHOUT Internet/MQTT/PWA/GAS:
- Safety supervisor runs locally (10 Hz tick, no network I/O)
- Scheduler runs locally (RTC-based, no network)
- E-WAVE cascade works locally
- REST works on LAN (direct to ESP32 IP)

### 6.2 REST endpoints (NEW)
```
GET  /api/relays                    — list all 8 channels (state + config)
POST /api/relays/{id}/on            — set channel ON (idempotent)
POST /api/relays/{id}/off           — set channel OFF (idempotent)
POST /api/relays/{id}/pulse         — momentary ON with duration
POST /api/relays/all_off            — emergency all-off
GET  /api/relays/config             — read relay config
POST /api/relays/config             — update relay config
POST /api/relays/{id}/acknowledge   — acknowledge safety alarm
POST /api/relays/{id}/clear         — clear safety lockout
```

All POST go through canonical pipeline (auth → CSRF → freshness →
canonicalize → journal → apply → ACK).

### 6.3 MQTT command (equivalent to REST)
Topic: `plts/{deviceId}/config` (existing command topic)
Payload: `{ type: "relay", action: "on", channel: 1, requestId: "...", ... }`
ACK: `plts/{deviceId}/ack` (existing ACK topic)

REST and MQTT produce IDENTICAL canonical hash → cross-transport dedup.

### 6.4 Telemetry (additive block in SystemStatus)
```json
{
  "relays": [
    {
      "channel": 0,
      "name": "Load 1",
      "desiredState": true,
      "reportedState": true,
      "physicalState": null,
      "stateConfidence": "SOFTWARE_ONLY",
      "fault": false,
      "lockoutState": "NORMAL",
      "source": "MANUAL",
      "lastChangedAt": 123456789
    }
  ]
}
```

### 6.5 PWA command state model (NEW)
8-state discriminator:
```
COMMAND_PENDING | CONFIRMED_ON | CONFIRMED_OFF | TIMEOUT | FAILED |
DEVICE_OFFLINE | UNKNOWN | STATE_DRIFT
```
- TIMEOUT ≠ FAILED (non-negotiable)
- After reconnect: GET current state → reconcile (NOT blind retry)
- Zustand store `Map<requestId, RelayCommandState>` with expiry timer

### 6.6 Capability discovery
```json
{
  "relay": {
    "supported": true,
    "channels": 8,
    "capabilities": ["SET_STATE", "PULSE", "ALL_OFF", "INTERLOCK", "MAX_ON_TIME"]
  }
}
```
PWA does NOT hard-code "8 relays always exist". Compatibility gate:
`canControlRelays` flag based on firmware version ≥ 1.8.0.

---

## 7. COMMAND MODEL (Canonical)

### 7.1 Idempotent state command (NOT toggle)
```json
{
  "transactionId": "uuid-...",
  "requestId": "uuid-...",
  "commandSequence": 42,
  "deviceId": "PLTS-A1B2C3",
  "type": "relay",
  "action": "on",
  "channel": 1,
  "desiredState": true,
  "semantics": "IDEMPOTENT_STATE",
  "source": "MANUAL",
  "expiresAt": 123456789
}
```

`toggle` is REJECTED. `on` / `off` are idempotent — replay is safe:
`ON → ON` stays ON (no double-flip).

### 7.2 Command hash (SHA-256, canonical)
```
SHA-256("v1|relay|on|channel=1|desiredState=true|semantics=IDEMPOTENT_STATE")
```
- `requestId` and `transactionId` EXCLUDED from hash (identifies transaction,
  not command)
- `expiresAt` EXCLUDED (envelope, not command)
- Field order FIXED per type (not JSON property order)
- REST and MQTT produce IDENTICAL hash → cross-transport dedup

### 7.3 ACK semantics
```
RECEIVED → ACCEPTED → EXECUTED (success)
                  → REJECTED (invalid command)
                  → BLOCKED (safety/interlock veto)
                  → FAILED (driver error)
                  → UNKNOWN (timeout — no confirmation)
```

---

## 8. SOURCE + PRIORITY

| Source | Priority | Use case |
|---|---|---|
| SAFETY | 1000 | maxOnTime FORCE OFF, fault, interlock |
| SYSTEM | 900 | E-WAVE cascade, boot policy |
| MANUAL | 800 | Operator REST/MQTT command (authorized) |
| AUTOMATION | 600 | Remote automation rule |
| SCHEDULE | 500 | RTC-based schedule |
| DEFAULT | 100 | Default OFF |

**Safety authority > manual control.** FORCE OFF cannot be overridden by
REST, MQTT, PWA, or Scheduler.

---

## 9. AUTHORIZATION

### 9.1 Role model (extend existing)
- `viewer` — can VIEW relay status, CANNOT control
- `operator` — can CONTROL relays (on/off/pulse/config)

`'relays'` added to `OPERATOR_ONLY_VIEWS` in PWA app-shell.

### 9.2 Per-channel ACL
**Decision: NOT implemented in v1.** Documented as limitation.
All 8 channels are operator-controllable. Per-channel ACL requires schema
extension to auth model — deferred to v2 if needed.

---

## 10. COMPATIBILITY MATRIX

| PWA | Firmware | Relay Capability |
|-----|---|---|
| old (≤1.7.x) | old (≤1.7.x) | N/A (no relay view) |
| new (1.8+) | old (≤1.7.x) | relay view hidden (`canControlRelays=false`) |
| old (≤1.7.x) | new (1.8+) | relay block in telemetry ignored (additive) |
| new (1.8+) | new (1.8+) | 8-channel relay fully functional |

Firmware version bump: 1.7.1 → 1.8.0 (relay feature = minor version).
Protocol version bump: 1 → 2 (new relay command types).
Config schema version: stays 1 (relay config is separate namespace).

---

## 11. BUILD FLAG

`PLTS_ENABLE_RELAYS=1` (default 1 in `platformio.ini`).

When OFF: byte-equivalent to current build (no relay code compiled in).
Telemetry `relays[]` block absent (additive, `#if PLTS_ENABLE_RELAYS`).

---

## 12. ELECTRICAL SAFETY (documentation requirement)

| Parameter | Requirement |
|---|---|
| Relay contact rating | Per relay module spec (typically 10A 250VAC) |
| Load type | Resistive (lights, fans) or inductive (motors, contactors) |
| Inductive load | Flyback diode (DC) or snubber (AC) REQUIRED |
| Inrush current | Verify relay contact rating > inrush peak |
| Fuse/MCB | Per-channel fuse sized to load |
| Isolation | Optocoupler relay module (standard) |
| Active level | LOW = ON (standard optocoupler relay module) |
| Boot behavior | ALL OFF at boot (fail-safe) |

**Firmware Production Grade ≠ electrical safety.** Operator MUST verify
electrical installation per local code.

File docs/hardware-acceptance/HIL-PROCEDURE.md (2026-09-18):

# HIL-PROCEDURE — Prosedur Kualifikasi Hardware-in-the-Loop (Gate 9)

Status: **PROSEDUR SIAP DIEKSEKUSI operator/test engineer.** Semua bukti
harus dihasilkan dari perangkat ESP32 FISIK nyata dengan firmware hasil
build produksi (SHA tercatat di `release.json`). Nilai rekaan/bayangan =
pelanggaran disiplin anti-false-closure. Verifier
`scripts/verify_gate_qualification.py` MENOLAK rilis tanpa bukti lengkap.

File bukti: `docs/hardware-acceptance/v{versi}-gate.json`
(salin dari `gate-qualification.template.json`, isi dari pengukuran nyata).

Peralatan minimum: ESP32 produksi (PLTS-ESP32-xxx), relai 8-kanal PCF8574 +
beban representatif per kanal, broker MQTT uji (akun nyata), stasiun kerja
dengan akses MQTT + REST + serial monitor, power supply yang dapat
diputus/di-brownout, ammeter/voltmeter referensi.

Urutan eksekusi direkomendasikan: A → B → … → L (A..K = matriks inti,
L = soak). Setiap bagian memetakan ke kunci `checks` di file bukti.

## A. boot / relayAllOffBoot (`checks.boot`, observed.relayAllOffBoot)

1. Flash firmware produksi (catat SHA256 biner; harus sama dengan
   `release.json.firmwareSha256`).
2. Boot dingin 3×, catat `bootTimeSec`, pastikan log `RELAY: Controller
   initialized` + semua kanal OFF (verifikasi fisik: beban mati, atau
   baca register PCF8574 0xFF).
3. **PASS** jika semua boot: 8 kanal OFF + lockout NVS dipertahankan.

## B. sensors / alarms (`checks.sensors`, `checks.alarms`)

Kalibrasi/verifikasi sensor sesuai protokol INA219 v1.9.2+
(`verify_ina219_hardware_acceptance.py` — bukti terpisah di
`v{versi}.json`). Bagian ini memastikan alarm registry menyala pada
 kondisi buatan (putus sensor SHT31/INA219 → alarm aktif + honest state).

## C. Power abuse (`checks.configPersistence` + observed.power/brownout/WDT)

1. **Power cycle** saat relay CH3 ON: putus VCC 10× berturut — setelah
   reboot semua kanal OFF (boot policy), konfigurasi NVS bertahan
   (maxOnTime/lease/policy dibaca kembali).
2. **WDT reset**: suspend relayTask via debugger/pause watchdog feed —
   perangkat reset, boot bersih, hitung `watchdogResetCount`.
3. **Brownout**: turunkan VCC di bawah ambang — reset reason = brownout,
   hitung `brownoutResetCount`.

## D. I²C failure (`observed.i2cFailureRecovery`)

Lepas jumper SDA/SCL PCF8574 saat sistem berjalan:
- tulis relay → harus GAGAL jujur (`fault=true`, alarm Critical,
  reportedState TIDAK diubah);
- sambung kembali → shadow recovery `ALL OFF` terverifikasi, mutasi
  normal kembali diizinkan.

## E. E-WAVE cascade / E-stop (`checks.emergencyRelay` + observed.ewave*)

1. Nyalakan ≥3 kanal; picu E-WAVE (kondisi sensor darurat).
2. Seluruh kanal OFF ≤1 tick (200 ms) + **safety latch** aktif.
3. Perintah ON saat latch → **BLOCKED (SAFETY_LATCHED)**.
4. Hanya jalur ARM operator eksplisit yang melepas latch.
5. E-stop fisik: tekan → OFF; lepas → TIDAK re-arm (harus ARM manual).
6. `checks.emergencyAtomicity` (PH8-01): selama burst perintah ON
   berkecepatan penuh (loop REST 10 Hz), picu `emergencyAllOff` —
   hitung pelanggaran (kanal menyala SETELAH emergency) → **harus 0**;
   `postTripOnRefused=true`, `armRequiredToReenable=true`.
7. `checks.watchdogStarvationBank` (PH8-02): matikan MQTT+WiFi+GAS lalu
   biarkan supervisor starvation terpicu → relay BANK ikut dipaksa OFF
   (forceSafetyAllOff), bukan hanya GPIO E-WAVE.

## F. Clock invalid (`checks.clockInvalidReject`, PH8-03)

1. Pastikan clock belum NTP-sync (boot tanpa WiFi).
2. Kirim perintah RELAY ON / OTA start dengan `expiresAt` terisi →
   **REJECTED CLOCK_INVALID**.
3. Kirim perintah OFF (safe-direction) → tetap DITERIMA.
4. Setelah NTP sync: perintah ON berjalan normal; perintah kedaluwarsa →
   REJECTED EXPIRED.

## G. Safety-config lockdown (`checks.safetyConfigLockdown`, PH8-04)

Dari CONFIG remote (build produksi): coba ubah `sensorFailPolicy`,
`estopEnabled`, `relayPin`, `estopPin` → semua **REFUSED** + event
CONFIG_REFUSED tercatat. Fisik tidak berubah.

## H. Comm-loss fail-safe (`checks.commLossFailSafe`, PH8-05) — PER KANAL

Provisioning: 7 kanal policy=OFF lease=900s; 1 kanal (mis. CH7)
policy=HOLD_SAFE hanya bila hazard classification terdokumentasi
(build flag `-DPLTS_ALLOW_HOLD_SAFE`); tanpa dokumentasi → 8 kanal OFF.

Matriks per gangguan (WiFi OFF / MQTT broker dihentikan / GAS
unreachable / proxy PWA+backend dimatikan):
1. Saat authority hilang: log `command authority LOST`.
2. Sebelum lease: kanal ON bertahan.
3. Setelah lease (atau percepat dengan lease kecil saat provisioning,
   mis. 60s): kanal policy=OFF **FORCE OFF** (source=COMM_LOSS,
   alarm Critical); kanal HOLD tetap ON + **tepat satu** WARNING.
4. Selama outage, kirim perintah REST lokal → lease kanal itu
   diperpanjang (operator presence).
5. Pulihkan authority: log `RESTORED`; **TIDAK ada kanal menyala
   otomatis**; `commLossForced` tetap jujur sampai perintah baru.
6. `checks.staleCommandBlocked`: kirim perintah ber-`expiresAt` pendek,
   putus MQTT sebelum dieksekusi, sambung kembali → perintah itu
   **BLOCKED** (tidak di-replay).

## I. Pin change refused (`checks.pinChangeRefused`, PH8-08)

Build produksi saat relay ON: kirim CONFIG `relayPin`/`estopPin` baru →
REFUSED; state fisik tidak berpindah ke GPIO baru.

## J. MQTT topic binding (`checks.mqttTopicBinding`, GATE-3)

1. Publikasikan perintah relay ke topik perangkat LAIN
   (`plts/<otherId>/config`) dengan kredensial yang salah alamat →
   TIDAK dieksekusi; hitam `foreignTopicCount` bertambah; security log
   tercatat.
2. Publikasikan ke topik sendiri (QoS 1) → dieksekusi + ACK.

## K. OTA durability + QoS (`checks.otaDurableReservation`, `checks.qosTimeoutBudget`)

1. Mulai OTA via MQTT; putus koneksi di tengah unduhan → record
   RESERVED **persist** (reboot → masih ada), status jujur, jalur
   pemulihan (lanjut/batal) berfungsi. Urutan: RESERVED → barunduh.
2. Matikan broker: anggaran timeout teramati (tidak menggantung),
   reconnect **full jitter** (catat interval antar percobaan — tidak
   seragam), laporan QoS jujur (QoS 0/1 sesuai kontrak, tidak
   mengklaim delivery yang tidak dibuktikan).

## M. Telemetry journal retention + crash recovery (`checks.telemetryJournalRetention`, P7-S1-02 / GATE-7b)

1. **Kapasitas jujur**: boot dengan target `offlineRetentionSec` >
   kapasitas fisik → `spoolJournalDegraded=true` di
   `/api/diagnostics`, baris WARNING di log, `spoolJournalEffectiveSec`
   < target — device TIDAK pernah mengklaim retensi yang tidak tersedia.
2. **Outage window** (retensi terkonfigurasi, mis. 600 s default):
   putus broker selama 1×, 2×, dan penuh window; setelah pemulihan,
   drain `spoolSize` → 0, **`sequence gaps == 0`** untuk semua record
   dalam window retensi (verifikasi di sisi GAS/dedup), replay
   berurutan oldest-first.
3. **Power-cycle di tengah outage** (regresi audit): putus broker,
   biarkan ≥ 60 s telemetry ter-buffer, **putus daya** ESP32, nyalakan
   lagi (broker masih mati) → journal **resume tanpa**: korupsi
   duplikat (record torn dihitung `spoolDrops`, bukan muncul dua
   kali), regresi sequence (urutan tetap naik), truncation senyap
   (`spoolDrops` mencatat setiap record yang hilang), false EMPTY
   (`spoolFsRestored` > 0 selama record valid tersisa).
4. **Crash mid-drain**: pulihkan broker sampai ~½ backlog ter-replay,
   putus daya → setelah boot, replay melanjutkan dari watermark;
   duplikat yang di-replay ≤ 16 record (`SPOOL_JOURNAL_WATERMARK_EVERY`)
   dan terserap dedup GAS (at-least-once, bukan korupsi).
5. **Batas eviksi**: biarkan outage melewati kapasitas penuh →
   `spoolJournalEvictions` naik, `EvictedOldest` ter-log, `spoolDrops`
   konsisten = jumlah record yang dievict (data loss jujur pada batas
   kapasitas, terlihat, tidak senyap).

## L. Soak 24–72 jam (`checks.soak24h`, observed.soak*)

Jalankan dengan beban campuran: telemetry 5s + reconnect storm terjadwal
(broker di-restart tiap 6 jam) + OTA check berkala + request web + alarm
churn buatan. **PASS** jika:
- tidak ada reset tak terduga (`resetCount` = hanya yang disengaja),
- `minFreeHeap` stabil (tidak ada penurunan monoton antar jam),
- tidak ada stack watermark melewati ambang kritis,
- tidak ada kebocoran transaksi/kredensial di log.

## Sertifikasi akhir (Gate 10)

Setelah A–L PASS untuk build produksi final:
1. Tanda tangan tiga peran (testEngineer, reviewer, releaseManager).
2. Verifikasi ulang `gitCommit` == source commit rilis dan
   `firmwareSha256` == artefak rilis.
3. Release gate CI menjalankan `verify_gate_qualification.py` (wajib
   untuk versi > 1.9.3) — tanpa bukti, rilis DIBLOKIR.
4. Pemantauan produksi pasca-rilis: 7 hari pertama = periode
   perketat (alarm COMM_LOSS/E-WAVE harus nihil kecuali gangguan nyata);
   insiden apa pun → post-mortem + bukti tambahan sebelum status
   "production soak" dinyatakan.

## Batasan jujur prosedur ini

- **PH8-07 (physical output verification)**: TIDAK dapat ditutup dengan
  prosedur software — butuh redesain hardware (auxiliary contact /
  bukti arus-tegangan) sebelum `stateConfidence` boleh meninggalkan
  `SOFTWARE_ONLY`. Tetap tercatat sebagai risiko terbuka.
- **F8 (broker ACL live)**: jalankan `scripts/broker-acl-test.mjs`
  (repo PWA) terhadap akun broker produksi — bukti terpisah dari file
  ini (lihat PWA docs/broker-acl/ACL-POLICY.md).
- Soak 24–72 jam mensyaratkan jendela waktu operator; jangan dipersingkat.

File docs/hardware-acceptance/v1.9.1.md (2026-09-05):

# INA219 Hardware Acceptance Protocol — v1.9.1

> **STATUS: PENDING** — this is a template. The Test Engineer must execute this
> protocol on real ESP32 hardware with the INA219 + shunt + voltage divider,
> fill in observed values, sign off, and export the verdict to
> `docs/hardware-acceptance/v1.9.1.json`.
>
> **v1.9.1 firmware MUST NOT be released without this acceptance.** The v1.9.0
> INA219 PGA register bug (inverted bit-mapping → both modes used ±320mV) was
> a P0 measurement-integrity defect. Although the source is now fixed, hardware
> evidence is the acceptance criterion — unit tests cannot prove measurement
> correctness.

## Release Candidate

| Field | Value |
|---|---|
| Version | 1.9.1 |
| Git Commit | `03667299f4e02d9e55cc8c9771ca6a9894a4aca2` |
| Firmware SHA-256 | _(filled by CI — see modular-release.json)_ |
| INA219_CONFIG_PGA_80MV | `0x0FFF` (PGA=01, ±80mV, 12-bit/128-sample) |
| INA219_CONFIG_PGA_160MV | `0x17FF` (PGA=10, ±160mV, 12-bit/128-sample) |
| Voltage Divider | R1=190kΩ, R2=10kΩ, ratio=20.0, 0.1µF cap parallel to R2 |
| Shunt | 100A/75mV → Rshunt=0.75mΩ (100A continuous, 150A peak) |

## Prerequisites

1. **Device**: ESP32-WROOM-32 flashed with v1.9.1 firmware (commit `0366729`)
2. **INA219**: Module at I²C address 0x40, R100 (0.1Ω) resistor REMOVED, external shunt 100A/75mV connected low-side
3. **Voltage Divider**: R1=190kΩ (battery+ → GPIO34), R2=10kΩ (GPIO34 → GND), 0.1µF ceramic cap parallel to R2
4. **Reference Meter**: Calibrated multimeter (voltage ±0.1V, current ±0.5A) OR clamp meter for cross-checking
5. **Load Bank**: Adjustable DC load capable of 1A → 150A (or multiple loads combined)
6. **Serial Monitor**: Connected at 115200 baud to observe INA219 init + PGA switch logs
7. **PWA**: Running in browser, connected to device WiFi, battery view visible

## Test Engineer

| Role | Name | Date | Signature |
|---|---|---|---|
| Test Engineer | __________ | ______ | __________ |
| Reviewer | __________ | ______ | __________ |
| Release Manager | __________ | ______ | __________ |

---

## Checklist (12 Criteria)

### Criterion 1: INA219 config register readback at boot

- [ ] Power on device, open Serial Monitor at 115200 baud
- [ ] Observe INA219 init log line: `[INA219 0x40] init: shunt=0.7500 mΩ, cal=0x..., sign=-1.0, pga=80mV`
- [ ] Observe config readback log: `[INA219 0x40] config readback OK: 0x0FFF (BRNG=0 16V, PGA=1 ±80mV, BADC=15, SADC=15, MODE=7)`
- [ ] Verify PGA=1 (decimal for 0b01 = ±80mV) — NOT PGA=3 (±320mV)
- [ ] Verify BADC=15 (12-bit/128-sample) — NOT a RESERVED value
- [ ] Verify SADC=15 (12-bit/128-sample) — NOT a RESERVED value
- [ ] Verify MODE=7 (shunt+bus continuous) — NOT MODE=3 (triggered/one-shot)
- [ ] Record `configReadbackHex` = "0x0FFF" in evidence JSON
- [ ] Record `configReadbackPgaBits` = 1 in evidence JSON

**Expected**: Readback matches `0x0FFF` exactly. PGA bits = 01 (±80mV). BADC/SADC = 15 (12-bit/128-sample). MODE = 7 (continuous). This proves the register write succeeded and the hardware is in the correct mode.

**If FAIL**: Do not proceed. The I²C write or the register constant is wrong. Check wiring + Config.h.

### Criterion 2: Low-current accuracy (1–2A standby, ±80mV mode)

- [ ] Set load bank to 1.5A
- [ ] Wait 10 seconds for EMA to settle
- [ ] Read PWA battery current display (should show 2 decimal places, e.g., "1.47 A")
- [ ] Read reference meter current
- [ ] Compute delta = |PWA - reference|
- [ ] Verify delta ≤ 0.5A (acceptance tolerance)
- [ ] Verify PWA PGA indicator shows "80mV"
- [ ] Record `lowCurrentPwa` and `lowCurrentRef` in evidence JSON

**Expected**: PWA current within ±0.5A of reference meter. PGA mode = "80mV". The ±80mV range has 10µV resolution (0.013A at 0.75mΩ), so 2-decimal precision is honest.

### Criterion 3: Mid-current accuracy (50A, ±80mV mode)

- [ ] Set load bank to 50A
- [ ] Wait 10 seconds for settling + any PGA switch transitions
- [ ] Read PWA battery current (should show 1 decimal place, e.g., "50.3 A")
- [ ] Read reference meter current
- [ ] Compute delta = |PWA - reference|
- [ ] Verify delta ≤ 1.0A (acceptance tolerance at higher current)
- [ ] Verify PWA PGA indicator still shows "80mV" (50A < 100A threshold)
- [ ] Record `midCurrentPwa` and `midCurrentRef` in evidence JSON

**Expected**: PWA within ±1.0A. PGA mode = "80mV" (no switch yet — 50A < 100A).

### Criterion 4: Pre-transition current (90A, ±80mV mode, hysteresis lower bound)

- [ ] Set load bank to 90A
- [ ] Wait 10 seconds
- [ ] Read PWA battery current
- [ ] Read reference meter current
- [ ] Verify PWA PGA indicator shows "80mV" (90A is at the hysteresis lower bound but still in 80mV mode)
- [ ] Record `preTransitionPwa` and `preTransitionRef` in evidence JSON

**Expected**: PGA = "80mV". Current reading within ±1.5A of reference.

### Criterion 5: PGA UP transition (100A → switch to ±160mV)

- [ ] Increase load from 90A to 105A (cross the 100A threshold)
- [ ] Watch Serial Monitor for: `[INA219 0x40] PGA 80mV → 160mV (I=105.0A ≥ 100A threshold)`
- [ ] Watch for: `[INA219 0x40] PGA settling — sample discarded (pga=160mV)` (one discarded sample)
- [ ] Wait 5 seconds for settling
- [ ] Verify PWA PGA indicator now shows "160mV"
- [ ] Read PWA battery current (should show 0 decimal places, e.g., "105 A")
- [ ] Read reference meter current
- [ ] Verify no false spike/NaN/discontinuity in the PWA current reading during transition
- [ ] Record `transitionUpObserved` = true, `transitionUpPwa`, `transitionUpRef` in evidence JSON

**Expected**: Serial log shows PGA switch. PWA PGA indicator changes to "160mV". One sample discarded. No false spike. Current reading is continuous (no NaN/zero jump).

### Criterion 6: Peak current measurement (120–150A, ±160mV mode)

- [ ] Increase load to 120A
- [ ] Wait 10 seconds
- [ ] Read PWA battery current
- [ ] Read reference meter current
- [ ] Verify delta ≤ 2.0A (acceptance tolerance at peak)
- [ ] Verify PWA PGA indicator shows "160mV"
- [ ] Record `peakCurrent120Pwa` and `peakCurrent120Ref`

- [ ] Increase load to 150A (if load bank supports it)
- [ ] Wait 10 seconds
- [ ] Read PWA battery current
- [ ] Read reference meter current
- [ ] Verify delta ≤ 3.0A (acceptance tolerance at absolute peak)
- [ ] Verify NO saturation (current should read ~150A, NOT cap at ~106A which would indicate ±80mV mode is still active)
- [ ] Record `peakCurrent150Pwa` and `peakCurrent150Ref`

**Expected**: 150A reads correctly (within ±3A). If reading caps at ~106A, the PGA switch is NOT working — this is the v1.9.0 bug symptom. The fact that 150A reads correctly proves the ±160mV mode is active.

### Criterion 7: PGA DOWN transition (90A → switch back to ±80mV)

- [ ] Decrease load from 150A to 85A (cross the 90A hysteresis lower threshold)
- [ ] Watch Serial Monitor for: `[INA219 0x40] PGA 160mV → 80mV (I=85.0A < 90A threshold)`
- [ ] Watch for: `[INA219 0x40] PGA settling — sample discarded (pga=80mV)`
- [ ] Wait 5 seconds
- [ ] Verify PWA PGA indicator now shows "80mV"
- [ ] Verify no false spike/NaN during transition
- [ ] Record `transitionDownObserved` = true, `transitionDownPwa`, `transitionDownRef`

**Expected**: Serial log shows PGA switch back to 80mV. PWA indicator changes. One sample discarded. No discontinuity.

### Criterion 8: Hysteresis stability (load hovering at 95A)

- [ ] Set load to 95A (between 90A lower and 100A upper threshold)
- [ ] Hold for 30 seconds
- [ ] Observe Serial Monitor — should NOT see rapid PGA switching (chattering)
- [ ] Count PGA switch events in 30 seconds: should be 0 (mode should stay in whatever it was)
- [ ] Record `hysteresisChatterCount` = 0

**Expected**: No chattering. The 10A hysteresis gap (90A/100A) prevents oscillation. If chatter count > 2, the hysteresis is not working.

### Criterion 9: Current sign correctness (charging vs discharging)

- [ ] With load drawing current (discharging): verify PWA shows NEGATIVE current (e.g., "-50.3 A") or direction = "DISCHARGING"
- [ ] With charger pushing current (charging, if available): verify PWA shows POSITIVE current (e.g., "+10.5 A") or direction = "CHARGING"
- [ ] Verify sign is consistent with the INA219_SIGN_CORRECTION = -1.0 in Config.h
- [ ] Record `dischargeSignCorrect` = true, `chargeSignCorrect` (if tested)

**Expected**: Discharge = negative, charging = positive. If signs are flipped, the INA219 VIN+/VIN- wiring is reversed — swap the shunt leads OR change INA219_SIGN_CORRECTION to +1.0.

### Criterion 10: Voltage divider accuracy (190k/10k, 20:1 ratio)

- [ ] Measure battery voltage with reference multimeter at the battery terminals
- [ ] Read PWA battery voltage display
- [ ] Compute delta = |PWA - reference|
- [ ] Verify delta ≤ 0.5V (acceptance tolerance at full pack voltage)
- [ ] Test at multiple voltage levels if possible (e.g., 42V, 50V, 57.5V)
- [ ] If delta > 0.5V: adjust `ADC_FINE_TUNE` in Config.h = (reference / PWA_reading), rebuild, re-test
- [ ] Record `voltagePwa`, `voltageRef`, `voltageDelta` in evidence JSON
- [ ] Record `adcFineTuneApplied` (final value after calibration, default 1.0)

**Expected**: PWA voltage within ±0.5V of multimeter. If not, calibrate ADC_FINE_TUNE. The 190kΩ/10kΩ divider with ±5% resistors can produce up to ±2V error at 57.5V without calibration.

### Criterion 11: Power calculation correctness (V × I)

- [ ] At a known load (e.g., 50A at 52V = 2600W):
- [ ] Read PWA battery power display
- [ ] Compute expected power = voltage × current
- [ ] Verify PWA power matches expected within ±5% (e.g., 2600W ± 130W)
- [ ] Record `powerPwa`, `powerExpected`, `powerDeltaPct`

**Expected**: PWA power within ±5% of V×I. Power is derived (busV × currentA), so this validates both voltage and current measurements are consistent.

### Criterion 12: Telemetry pga_mode field correctness

- [ ] At 50A (±80mV mode): verify PWA PGA indicator = "80mV" AND Google Sheet `ina219_pga_mode` column = "80mV"
- [ ] At 120A (±160mV mode): verify PWA PGA indicator = "160mV" AND Google Sheet `ina219_pga_mode` column = "160mV"
- [ ] Verify the telemetry field matches the actual hardware register state (cross-reference with Serial Monitor readback log)
- [ ] Record `telemetryPgaModeMatchesHardware` = true

**Expected**: The `pga_mode` telemetry field (PWA + Google Sheet) matches the actual INA219 config register state shown in Serial Monitor. This is the end-to-end proof that the register readback + telemetry + PWA display chain is consistent.

---

## Release Decision

- [ ] **RELEASE** — All 12 criteria PASS. v1.9.1 INA219 measurement chain accepted.
- [ ] **CONDITIONAL** — Criteria 1-11 PASS, criterion 12 (telemetry) deferred. Accepted with monitoring.
- [ ] **BLOCKED** — Any criterion FAILED. v1.9.1 NOT accepted. Investigate root cause.

**Final Verdict:** __________

## Evidence Export

After completing the checklist, export the verdict to `docs/hardware-acceptance/v1.9.1.json` using the template at `v1.9.1.template.json`. Fill in all `observed` fields with actual values, set all `checks` to `PASS` or `FAIL`, and set `verdict` to `PASS` or `BLOCKED`.

Run the verifier locally:
```bash
python3 scripts/verify_ina219_hardware_acceptance.py \
  --version 1.9.1 \
  --ci-sha 03667299f4e02d9e55cc8c9771ca6a9894a4aca2 \
  --release-json ci-artifacts/modular/release.json \
  --hw-dir docs/hardware-acceptance
```

## Key Acceptance Principle

**Unit tests prove the source code is correct. Hardware acceptance proves the MEASUREMENT is correct.**

The v1.9.0 bug (inverted PGA bit-mapping) passed unit tests because the unit test only checked the constant values, not the actual hardware register state. The v1.9.1 fix adds register readback verification, but even that only proves the register write succeeded — it does NOT prove the current reading is accurate.

Only Criterion 2 (1.5A accuracy), Criterion 6 (150A no saturation), and Criterion 10 (voltage accuracy) can prove measurement correctness. These require a physical reference meter and are NOT optional.

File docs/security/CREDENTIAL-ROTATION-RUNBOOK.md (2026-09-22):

# Runbook Rotasi Kredensial — Temuan #19

> Inventaris machine-readable: `docs/security/credential-inventory.json`
> Penegakan anti-fabrikasi: `scripts/check_surface_policy.py` (job CI
> `surface-policy-gate`) — `lastRotated` non-null WAJIB disertai
> `evidenceRef` yang menunjuk file bukti nyata.
> Asal temuan: audit baseline 14-field 2026-09-18, temuan #19 —
> "rotasi kredensial".

## 0. Prinsip yang mengikat

1. **Bukti, bukan klaim.** Setiap rotasi menghasilkan file bukti di
   `docs/security/evidence/C-XX-<tanggal>.json` yang berisi minimal:
   `rotatedAt`, `rotatedBy` (peran manusia), `verification` (hasil
   perintah verifikasi + exit code), dan `scope` (device/fleet/layer).
   Tanpa file itu, inventaris tetap `lastRotated: null` — klaim rotasi
   tanpa bukti = fabrikasi, dan CI menolaknya.
2. **Satu lapis per jendela.** Jangan merotasi MQTT + GAS + VAPID pada
   hari yang sama. Urutan rekomendasi tiap kredensial ada di §2; jika
   dua lapis harus berdekatan, beri jeda minimal 24 jam dan verifikasi
   lapis pertama hijau dulu.
3. **Staging sebelum produksi.** Kredensial build-time (C-03, C-04)
   diverifikasi dulu pada env `staging` (platformio / GitHub
   Environment) sebelum menyentuh `production`.
4. **Rollback dirancang sebelum dipakai.** Setiap prosedur di bawah
   punya bagian "Rollback" — kredensial lama JANGAN dihapus dari
   penyimpanan aman sampai verifikasi lapis baru hijau DAN jendela
   rollback (7 hari) lewat.
5. **Bukan-salah-nama.** `config/pwa-pin.txt` berisi SHA commit yang
   di-pin (penanda versi PWA), BUKAN kredensial — jangan pernah
   dimasukkan ke rotasi. (Rename ke `pwa-commit-pin.txt` opsional;
   tidak ada konsumen kode saat ini.)

## 1. Peta kredensial → lapisan → tooling yang sudah ada

| ID | Kredensial | Penyimpanan saat ini | Tooling repo yang dipakai |
|---|---|---|---|
| C-01 | User/pass operator web device | NVS per-device (AuthManager) | `POST /api/ln` (butuh pass lama) |
| C-02 | Secret JWT per-device | NVS per-device (Core::jwtSecret) | ProvisionHandlers (AP setup) |
| C-03 | Kredensial MQTT broker | GitHub Environment `production` → di-inject saat build | `inject_production_flags.py`, `.env.example` |
| C-04 | Keypair Ed25519 penanda OTA | PEM 0600 lokal operator (`firmware_signing_private.pem`, ter-gitignore) | `sign_firmware.py --gen-keys/--sign/--verify` |
| C-05 | Token fleet + secret per-device GAS | Sheet DEVICES (device_key, secret) + `config.token` di firmware-generic | `make-gas-bundle.sh`, `prep-deploy-secrets.js` |
| C-06 | Keypair VAPID push | Secret deployment GAS push-alarm | `generate-vapid-keys.js` |
| C-07 | Secret env PWA (JWT server, dll.) | Vercel env (saat ini TIDAK terprovision — mode browser-configured) | `live-smoke-test.mjs` utk verifikasi |
| C-08 | Token akses repo (GitHub PAT) | Milik operator/agent | — (prosedur manual GitHub) |
| C-09 | Kunci Gemini API (insights) | Env build/ops + config GAS | `.env.example` (GEMINI_API_KEY) |

## 2. Prosedur per kredensial

### C-01 — Kredensial operator web device (per device)

**Rotate:** (1) Login ke device via PWA (kredensial lama). (2) `POST
/api/ln` dengan password lama + password baru (ExtraHandlers.cpp
menolak tanpa password lama — jangan lewat endpoint lain). (3) Logout,
login ulang dengan kredensial baru. **Verify:** `python3
scripts/device_healthcheck.py --device <ip> --phase login` (fase-2
login, exit 0 hanya bila kredensial baru benar-benar diterima). **Blast
radius:** operator device itu saja. **Rollback:** ulang prosedur dengan
password lama (yang masih diketahui operator). **Cadence:** 180 hari,
atau segera saat ada indikasi kebocoran.

### C-02 — Secret JWT per-device

**Rotate:** jalankan ulang provisioning per-device (ProvisionHandlers,
mode AP WPA2 + CSPRNG; secret baru ditulis ke NVS; AP password
diperlihatkan SEKALI — catat). **Verify:** fase-1 `device_healthcheck.py`
(200 `/api/status` tanpa session lama) + login fase-2. **Blast radius:**
semua session PWA ke device itu gugur (by design). **Rollback:** tidak
ada — secret lama sudah tertimpa; pastikan operator siap login ulang
sebelum rotate. **Cadence:** 365 hari atau saat dicurigai.

### C-03 — Kredensial MQTT broker (fleet, build-time)

**Rotate:** (1) Buat kredensial BARU di broker (jangan hapus yang lama
dulu). (2) Perbarui GitHub Environment `production`:
`MQTT_USERNAME`, `MQTT_PASSWORD` (+ `MQTT_ROOT_CA` bila CA broker
ikut berganti). (3) Build firmware — `inject_production_flags.py`
memvalidasi flag hasil inject dan **gagal build** bila kosong/tidak
valid (fail-closed sudah teruji di pipeline). (4) Flash via OTA
bertanda-tangan, staging dulu. **Verify:** `device_healthcheck.py`
fase-1 (status MQTT per device) + `load_soak_runner.py` rencana kecil
(lihat HIL-RUNNER-QUICKSTART §3) pada env staging. **Blast radius:**
device yang belum re-flash tetap pakai kredensial lama — JANGAN
hapus kredensial lama di broker sampai 100% fleet ter-migrasi
(cek via healthcheck per device). **Rollback:** kembalikan nilai env
GitHub + rebuild; kredensial lama masih hidup di broker. **Cadence:**
90 hari.

### C-04 — Keypair Ed25519 penanda OTA

**Rotate (key ceremony):** (1) `python3 scripts/sign_firmware.py
--gen-keys` di mesin operator TERPUTUS jaringan (PEM 0600, tidak
pernah masuk git — sudah di-gitignore). (2) Simpan private key baru ke
penyimpanan aman (vault/backup fisik). (3) Perbarui
`OTA_ED25519_PUBLIC_KEY_HEX` di GitHub Environment production. (4)
Build + rilis firmware versi baru → device menerima public key baru
melalui build ter-baru; SEBELUM itu, rilis yang sudah berjalan tetap
memverifikasi tanda dengan public key lama. **Batas jujur:** firmware
saat ini membawa SATU public key — rotasi adalah cutover bertahap
(fleet migrasi via rilis berturut), bukan dual-signing. Karena itu:
kunci lama tetap valid untuk device lama sampai fleet penuh ter-update;
jangan hancurkan kunci lama terlalu dini. **Verify:** `sign_firmware.py
--verify` pada biner baru + `verify_ota_evidence.py` pada evidence
rilis; satu device staging menjalani OTA penuh + rollback
(HIL-PROCEDURE bagian K). **Rollback:** firmware ter-build dengan
public key lama tetap ter-release (jangan force-upgrade semua
sekaligus). **Cadence:** 365 hari (key ceremony berat) atau segera
saat private key dicurigai bocor.

### C-05 — Token fleet + secret per-device GAS

**Rotate token fleet:** (1) Buat token baru di Sheet config GAS.
(2) `scripts/make-gas-bundle.sh` + `prep-deploy-secrets.js` → deploy
ulang GAS (deployment ID bisa berganti — perbarui `gasUrl` fleet via
config OTA). (3) Revoke token lama di sheet SETELAH fleet selesai
bermigrasi. **Rotate secret per-device:** baris DEVICES (kolom
`secret`) + `last_nonce` di-reset — firmware-generic membawa token
baru via config. **Verify:** `push-alarm/tools/verify-deployment.js` /
`scripts/verify-gas-deployment.js`; telemetri device mengirim
`(device_key, sequence)` dan GAS menjawab SUCCESS (bukan 401) —
cek log ingest 24 jam. **Blast radius:** seluruh fleet berhenti
ter-authorize jika token lama direvok sebelum migrasi selesai. **Rollback:**
aktifkan kembali token lama di sheet (jika belum dihapus permanen). **Cadence:**
90 hari; segera (revokasi dulu, baru rotasi) saat dicurigai bocor.

### C-06 — Keypair VAPID push

**Rotate:** (1) `node push-alarm/tools/generate-vapid-keys.js`. (2)
Perbarui secret VAPID di deployment GAS push-alarm. (3) Deploy ulang.
**Blast radius (besar, jujur):** SEMUA subscription push browser gugur —
endpoint lama ditandatangani subjek VAPID lama; pengguna harus
re-subscribe (PWA meminta permission ulang saat panel push dibuka).
Rencanakan komunikasi pengguna SEBELUM rotasi. **Verify:** subscribe 1
device uji + `verify-deployment.js`; monitor angka subscription aktif
pasca-rotasi. **Rollback:** kembalikan keypair lama di secret GAS —
subscription yang belum re-subscribe hidup kembali. **Cadence:** 365
hari (blast radius besar — jangan lebih sering tanpa alasan).

### C-07 — Secret env PWA (server-side)

**Status saat ini (2026-09-22): TIDAK terprovision.** Probe live
`/api/health` jujur melaporkan `jwtSecretConfigured=false`, mode
`browser-configured` — tidak ada secret server yang perlu dirotasi
SEBELUM provisioning dilakukan. Ketika provisioning dilakukan:
**Rotate:** perbarui env di Vercel → redeploy. **Verify:**
`node scripts/live-smoke-test.mjs --monitoring <url> …` (assert
`/api/health` + header keamanan). **Blast radius:** session JWT server
gugur semua (pengguna login ulang). **Rollback:** kembalikan env lama
+ redeploy. **Cadence:** 90 hari sejak provisioning.

### C-08 — Token akses repo (GitHub PAT)

**Rotate:** GitHub → Settings → Developer settings → Personal access
tokens: buat token baru (scope minimum `repo`), gunakan untuk push,
lalu revoke token lama. Agent menggunakan identitas commit
"PLTS Prod Engineering (agent)" — token milik operator, bukan milik
repo. **Verify:** `git push --dry-run` + `gh api rate_limit` (header
ter-autentikasi). **Blast radius:** akses push orang/agent yang
memakai token itu. **Rollback:** token baru dibuat ulang bila salah
scope — tidak ada state rusak. **Cadence:** 30–90 hari, selalu
expiry pendek.

### C-09 — Kunci Gemini API (AI insights)

**Rotate:** Google AI Studio → API key baru → perbarui env
`GEMINI_API_KEY` (+ `GAS_INSIGHTS_URL` bila deployment berganti) →
revoke kunci lama. **Verify:** `node scripts/test_gas_parity_insights.js`
/ `test_gas_contract.js` (parity kontrak insights). **Blast radius:**
fitur AI insights mati sampai kunci baru aktif — bukan jalur kontrol. **Rollback:**
kembalikan kunci lama di env. **Cadence:** 90 hari.

## 3. Format file bukti (evidence)

`docs/security/evidence/C-XX-<YYYY-MM-DD>.json`:

```json
{
  "credential": "C-03",
  "rotatedAt": "2026-10-01T02:00:00+07:00",
  "rotatedBy": "operator (nama/peran)",
  "scope": "fleet MQTT, 12 device",
  "verification": {
    "command": "python3 scripts/device_healthcheck.py --device 10.0.0.5 --phase login",
    "exitCode": 0,
    "verdict": "HEALTHY"
  },
  "rollbackWindowUntil": "2026-10-08"
}
```

Lalu perbarui `credential-inventory.json`: `lastRotated` +
`evidenceRef: "docs/security/evidence/C-03-2026-10-01.json"`.
`check_surface_policy.py` menolak `evidenceRef` yang menunjuk file
yang tidak ada — bukti hilang = rotasi dianggap tidak terjadi.

## 4. Urutan rekomendasi jendela rotasi pertama

1. C-08 (token repo) — termurah, tanpa downtime.
2. C-05 (token fleet GAS) — satu jendela migrasi.
3. C-03 (MQTT) — staging dulu, per batch device.
4. C-01/C-02 (per device, menyertai kunjungan fisik/HIL).
5. C-09 → C-07 (saat provisioning PWA) → C-06 (komunikasi pengguna
   dulu) → C-04 (key ceremony).

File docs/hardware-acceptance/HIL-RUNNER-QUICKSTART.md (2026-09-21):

# HIL-RUNNER-QUICKSTART — Bench Operator Guide (GATE-9 / GATE-10)

Panduan cepat menjalankan tooling HIL & soak di **bench nyata**.
Prosedur lengkap tetap `HIL-PROCEDURE.md`; dokumen ini menjelaskan
pemakaian tool + urutan sesi yang aman. Terakhir diperbarui: 2026-09-22
(cabang `gate9/hil-tooling-soak`).

## 0. Prinsip yang dipegang tool

- **Verdict tidak pernah di-set PASS oleh tool.** Tool hanya mencatat hasil
  TERUKUR (`PASS`/`FAIL`) dan meninggalkan sisanya `PENDING`. PASS final
  mensyaratkan 22/22 check terukur + signoff 3 peran (testEngineer,
  reviewer, releaseManager) — diverifikasi `verify_gate_qualification.py`.
- **READ-ONLY default.** Semua mutasi (relay ON, config POST, emergency,
  OTA, reboot) terpisah di balik flag `--i-confirm-*`. Tanpa flag → bagian
  SKIPPED, exit tetap jujur.
- **Kredensial hanya via environment** — tidak pernah di argv, file, atau
  log. Jangan menaruh password di command line.
- **Kegagalan precondition = exit 2**, bukan PASS kosong (anti-false-closure).

## 1. Setup sekali (bench)

```bash
export DEVICE_URL=http://192.168.x.x        # URL perangkat bench
export DEVICE_USER=<operator-username>
export DEVICE_PASS=<operator-password>
export HIL_MQTT_HOST=<broker-host>          # untuk bagian J
export HIL_MQTT_PORT=8883
export HIL_MQTT_USERNAME=<viewer/device-user>
export HIL_MQTT_PASSWORD=<password>
# opsional: export HIL_MQTT_CA=/path/ca.pem
pip3 install "paho-mqtt==2.1.0"
```

Sumber identitas build (untuk mengikat bukti ke binary):

```bash
python3 scripts/hil_runner.py --release-json ci-artifacts/modular/release.json \
  --version 1.9.4 --test-engineer "Nama Test Engineer" \
  --hardware-serial <serial-bench> --broker "$HIL_MQTT_HOST"
```

`gitCommit`/`firmwareSha256` bukti otomatis diambil dari `release.json`.

## 2. Urutan sesi yang disarankan

Rencana lengkap: `python3 scripts/hil_runner.py --plan`

| Sesi | Bagian | Perintah inti | Catatan |
|---|---|---|---|
| 1 (read-only) | A, J | `--section A --section J` | Identitas + boot + topic binding; tanpa flag mutasi |
| 2 (actuation) | C, E, F, G, I | `--section C --section E --section F --section G --section I --i-confirm-actuation` | Beban representatif; E-stop fisik dipicu operator |
| 3 (soak) | L | `--section L --soak-min 1440` (24 jam) | `soak24h` hanya diisi pada soak >= 24 jam — di bawah itu tetap PENDING (jujur) |
| 4 (OTA) | K | sesi lanjutan `--i-confirm-ota` | Ikuti HIL-PROCEDURE.md bagian K |
| Fisik murni | B, D, H, M | — (manual) | Sensor fisik, jumper I2C, outage, retensi journal |

Bagian yang TIDAK diotomasi runner: B, D, H, K (manual), M — hasilnya
dicatat operator pada finalisasi (lihat HIL-PROCEDURE.md).

Contoh sesi 1:

```bash
python3 scripts/hil_runner.py --device "$DEVICE_URL" \
  --section A --section J --yes=false \
  --emit-evidence docs/hardware-acceptance/v1.9.4-gate.DRAFT.json
```

Setiap sesi berikutnya menulis ulang DRAFT (bagian yang belum dieksekusi
tetap PENDING — runner tidak menghapus kemajuan sesi sebelumnya secara
diam-diam; verifikasi ulang isi file setelah tiap sesi).

## 3. Load/soak broker (GATE-10 / F4)

```bash
python3 scripts/load_soak_runner.py --plan          # lihat rencana dulu
SOAK_MQTT_HOST=<prod-broker> SOAK_MQTT_USERNAME=<u> SOAK_MQTT_PASSWORD=<p> \
python3 scripts/load_soak_runner.py --devices 10 --duration 3600 \
  --i-confirm-publisher --out soak-run.json --raw-out soak-run-raw.json
```

- Publikasi HANYA ke `plts/SOAK-<runId>-NNN/status` — topik kontrol
  perangkat nyata tidak mungkin tersentuh.
- Budget default: latencyP95 2000 ms, dropRatio 0.001, disconnects 0,
  duplicates 0. Atur via `--latency-p95-budget-ms` dst.
- `--raw-out` menyimpan sampel latensi mentah untuk agregasi multi-chunk
  atau re-budgeting tanpa re-run.
- Catatan jujur: diukur dari satu stasiun; bukan distribusi geografis.

## 4. Finalisasi bukti → rilis

1. Pastikan `v1.9.4-gate.DRAFT.json` 22/22 terukur (tanpa PENDING).
2. Isi signoff 3 peran + salin ke `v1.9.4-gate.json` (hilangkan DRAFT).
3. Validasi lokal: `python3 scripts/verify_gate_qualification.py --version 1.9.4 --release-json <release.json>`.
4. Rilis tetap diblok CI (`verify-hardware-acceptance`, P0-2) sampai
   bukti lengkap + tag-signed — tidak ada jalan pintas.

Pengingat: nilai yang tidak diukur TIDAK BOLEH diisi manual dengan "PASS".
Jika sebuah check tidak bisa diukur hari itu, biarkan PENDING dan
jadwalkan sesi ulang — inilah disiplin anti-false-closure proyek ini.

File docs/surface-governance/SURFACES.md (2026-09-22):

# Tata Kelola Permukaan (Surface Governance) — Temuan #18

> Registry machine-readable: `docs/surface-governance/SURFACE-STATUS.json`
> Penegakan CI: `scripts/check_surface_policy.py` + job `surface-policy-gate`
> Asal temuan: audit baseline 14-field 2026-09-18, temuan #18 —
> "permukaan paralel legacy".

## 1. Masalah yang diselesaikan dokumen ini

Repo ini bukan berisi SATU sistem, melainkan **jalur deployment paralel**
yang tumbuh dari tiga generasi arsitektur (MonitorIoT greenhouse →
kanal GAS PLTS → REST/MQTT direct). Setiap jalur punya firmware dan/atau
backend GAS sendiri. Perbaikan keamanan yang mendarat di satu jalur
**tidak otomatis menyebar** ke jalur lain — inilah risiko divergensi
temuan #18: sistem terlihat diperbaiki, sementara salinan paralelnya
tetap membawa kelemahan lama, tanpa ada yang gagal build.

Contoh divergensi nyata yang sudah terukur pada 2026-09-22:

- `firmware/Web/AuthHandlers.cpp` (jalur REST) mengimplementasikan
  login + CSRF + cookie session + peran operator.
- `firmware-generic/` (jalur GAS) TIDAK punya auth web sama sekali —
  WebServer-nya hanya hidup di mode AP setup ([FW-A3] WPA2+CSPRNG),
  `handleClient()` tidak pernah dipanggil saat STA — jadi bukan celah
  terbuka, tetapi juga bukan "sudah sama amannya": dua model keamanan
  berbeda yang harus diverifikasi terpisah selamanya.
- `code.gs/Code.gs` membawa kontrak identitas `(device_key, sequence)`
  + HMAC v2.1; `push-alarm/gas/Code.gs` (1.352 baris, duplikat berbeda)
  tidak membawa penanda itu.

## 2. Matriks kemampuan per permukaan

| Kemampuan | firmware/ | firmware-generic/ | code.gs/ | push-alarm/gas/ | MonitorIoT |
|---|---|---|---|---|---|
| Status | **active** | **active** | **active** | **frozen** | **deprecated** |
| Auth web (login/CSRF/session) | ya | AP-setup saja (WPA2) | n/a | n/a | n/a |
| Identitas (device_key, sequence) + ledger gap | (REST: cookie+CSRF) | ya [P1-00x] | ya [P1-00x] | **tidak** | **tidak** |
| Auth kanal GAS (HMAC v2.1) | n/a | token+device_key | ya | **tidak** | token saja |
| OTA bertanda-tangan + rollback | ya (MQTT/GAS) | ya (+laporan ROLLBACK jujur) | ya (sisi server) | **tidak** | **tidak** |
| Pinning TLS | MQTT_ROOT_CA | GAS_ROOT_CA (GTS R4) | — (sisi GAS) | — | ya (GTS R1+R4) |
| Watchdog | ya (esp_task_wdt) | ya | n/a | n/a | **tidak** |
| Emergency lokal tanpa jaringan | ya (EmergencySupervisor) | ya (emgTick local-first) | n/a | n/a | tidak |
| Terhubung pipeline rilis CI | ya (tag v*) | ya (rilis biner) | bundle manual | **tidak** | **tidak** |

(n/a = tidak relevan untuk jenis permukaan tersebut; **tidak** = risiko
divergensi nyata yang menjadikan permukaan itu dibekukan/dipensiunkan.)

## 3. Kebijakan penegakan (apa yang CI tolak)

1. **Permukaan frozen/deprecated berubah** — setiap file di bawah
   `push-alarm/gas/` dan `push-alarm/firmware/MonitorIoT_Firmware/`
   dip-pin SHA-256. Ubah satu byte, tambah file, hapus file → job
   `surface-policy-gate` GAGAL. Satu-satunya jalan mengubah adalah
   memperbarui pin di `SURFACE-STATUS.json` pada PR yang sama — pin di
   diff adalah tanda tangan eksplisit reviewer, terlihat dan bisa
   di-negotiate, bukan modifikasi senyap.
2. **Marker hardening hilang dari permukaan aktif** — refactor yang
   menghapus `P0-003` (fail-closed device secret), `getOrCreateApPassword`
   ([FW-A3]), `setCACert(GAS_ROOT_CA)`, `HMAC-SHA256`/`DEVICES_HEADER`/
   `SeqIndex` di code.gs, atau `esp_task_wdt` → GAGAL. Refactor tetap
   boleh, marker harus dipulihkan/didaftarkan ulang dengan sengaja.
3. **Fabrikasi riwayat rotasi** — `docs/security/credential-inventory.json`
   menolak `lastRotated` non-null tanpa `evidenceRef` yang menunjuk file
   bukti yang benar-benar ada (temuan #19, lihat runbook rotasi).

Batas scope yang diakui jujur: checker ini analisis statis penanda —
ia TIDAK membuktikan semantik dua kontrak identik, TIDAK membandingkan
logika baris-per-baris antar permukaan, dan TIDAK memeriksa repo PWA
(permukaan lintas-repo dicatat sebagai `external-ref`).

## 4. Keputusan terbuka (butuh pemilik repo, bukan agent)

| ID | Keputusan | Opsi | Konsekuensi menunda |
|---|---|---|---|
| D-1 | Nasib `push-alarm/gas/` | pensiunkan → migrasi fleet ke `code.gs/`; ATAU promosikan jadi kanonik → naikkan kontrak P1-00x + HMAC v2.1 | Dua backend GAS diverifikasi berbeda tetap hidup; audit keamanan harus dilakukan dua kali |
| D-2 | Nasib `push-alarm/firmware/MonitorIoT_Firmware/` | hapus setelah konfirmasi tidak ada fleet greenhouse aktif mem-flash dari sini | Permukaan deprecated tetap di repo; risiko orang baru mem-flash jalur tanpa hardening |

Kedua keputusan sengaja TIDAK diambil sepihak oleh agent — penghapusan
jalur deployment adalah keputusan pemilik sistem. Sampai diputuskan,
pin menjaga status quo secara auditable.

## 5. Checklist perbaikan keamanan lintas permukaan

Ketika sebuah perbaikan keamanan menyentuh kontrak bersama, gunakan
checklist ini di PR (salin ke deskripsi PR):

- [ ] `firmware/` — terdampak? sudah diterapkan?
- [ ] `firmware-generic/` — terdampak? sudah diterapkan?
- [ ] `code.gs/` — terdampak? sudah diterapkan? (bundle GAS + redeploy)
- [ ] `push-alarm/gas/` (frozen) — jika terdampak: tulis alasannya di PR
      dan perbarui pin, ATAU selesaikan dulu keputusan D-1.
- [ ] `MonitorIoT/` (deprecated) — jika terdampak: tulis alasannya di PR
      dan perbarui pin, ATAU tinggalkan sengaja (dokumentasikan).
- [ ] Repo PWA — `pwa-push-alarm/` / `public/firmware/manifest.json`
      terdampak? (penegakan di repo PWA sendiri)

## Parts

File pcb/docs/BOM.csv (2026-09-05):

Ref | Qty | Value | Footprint
R70 | 1 | 100R 1% | R_0603_1608Metric
C20, C21, C34, C35, C40, C41, C44, C65, C66, C70, C75, C81, C82 | 13 | 100nF 25V X7R | C_0603_1608Metric
OPT1 | 1 | PC817 | DIP-4_W7.62mm
R30, R31, R45, R78, R82 | 5 | 10k 1% | R_0603_1608Metric
R85, R86 | 2 | 5.1k | R_0603_1608Metric
LED1 | 1 | STATUS 0805 | LED_0805_2012Metric
C43 | 1 | 100nF 25V C0G | C_0603_1608Metric
TP_VBAT | 1 | VBAT_DIV | TestPoint_Pad_D2.0mm
R71, R77 | 2 | 100k 1% | R_0603_1608Metric
FID1, FID2, FID3 | 3 | Fiducial_1mm_Mask2mm | Fiducial_1mm_Mask2mm
U6 | 1 | SHT31-DIS-B2.5KS | Sensirion_DFN-8-1EP_2.5x2.5mm_P0.5mm_EP1.1x1.7mm
Q21, Q22, Q23 | 3 | BSS138 | SOT-23
U2 | 1 | CP2102N-A02-GQFN24 | HVQFN-24-1EP_4x4mm_P0.5mm_EP2.1x2.1mm
R74 | 1 | 1k | R_0603_1608Metric
R80, R81, R87, R88 | 4 | 10k | R_0603_1608Metric
R48, R49 | 2 | 120R 1% | R_0603_1608Metric
D10 | 1 | SM712 | SOT-23
RSH1 | 1 | FL-2 100A/75mV | Shunt_FL2_100A
Q1, Q2 | 2 | S8050 | SOT-23
F3 | 1 | 1A T 250VAC 5x20 | Fuseholder_Clip-5x20mm_Littelfuse_111_Inline_P20.00x5.00mm_D1.05mm_Horizontal
TP_EN | 1 | EN | TestPoint_Pad_D2.0mm
D22, D23, D24, D25 | 4 | SMAJ5.0A | D_SMA
FB2, FB50 | 2 | 600R@100MHz | L_0805_2012Metric
JP_CAN_TERM, JP_RS485_TERM | 2 | TERM 120R | SolderJumper-2_P1.3mm_Open_Pad1.0x1.5mm
H1, H2, H3, H4 | 4 | MountingHole_3.2mm_M3 | MountingHole_3.2mm_M3
C64 | 1 | 4.7uF 16V X5R | C_0603_1608Metric
Q20 | 1 | AO3400A | SOT-23
TP_RS485_A | 1 | RS485_A | TestPoint_Pad_D2.0mm
R20a, R20b | 2 | 49.9k 1% 0805 | R_0603_1608Metric
U7 | 1 | DS3231SN# | SOIC-16W_7.5x10.3mm_P1.27mm
SW2 | 1 | BOOT | SW_PUSH_6mm
U4, U5 | 2 | ACS712ELCTR-30A-T | SOIC-8_3.9x4.9mm_P1.27mm
TP_CAN_H | 1 | CAN_H | TestPoint_Pad_D2.0mm
R75 | 1 | 47k 1% | R_0603_1608Metric
C42 | 1 | 10uF 16V X5R | C_0603_1608Metric
TP_GND | 1 | PGND | TestPoint_Pad_D2.0mm
NT0 | 1 | NET-TIE PGND-BAT- (STAR) | NetTie-2_SMD_Pad2.0mm
R32, R33, R83 | 3 | 15k 1% | R_0603_1608Metric
R40, R41, R79, R84 | 4 | 4.7k 1% | R_0603_1608Metric
F4 | 1 | 1.1A hold | Fuse_1812_4532Metric
C61, C63 | 2 | 100nF 50V X7R | C_0805_2012Metric
TP_UART_RX | 1 | UART0_RX | TestPoint_Pad_D2.0mm
R72 | 1 | 330R 1% | R_0603_1608Metric
R76 | 1 | 68k 1% | R_0603_1608Metric
TP_SHUNT_K+ | 1 | SHUNT_K+ | TestPoint_Pad_D2.0mm
TP_RS485_B | 1 | RS485_B | TestPoint_Pad_D2.0mm
J_EXP | 1 | EXPANSION 7-PIN 2,54 | PinHeader_1x07_P2.54mm_Vertical
NT1 | 1 | NET-TIE AGND-PGND | NetTie-2_SMD_Pad0.5mm
TP_3V3 | 1 | +3V3 | TestPoint_Pad_D2.0mm
J_PROGRAM | 1 | PROG 3V3/GND/TX/RX/EN/IO0 | PinHeader_1x06_P2.54mm_Vertical
M_PZEM | 1 | PZEM-004T v3.0 100A-CT | Module_PZEM_004T_Socket
TP_CAN_L | 1 | CAN_L | TestPoint_Pad_D2.0mm
C83 | 1 | 1uF 25V X7R | C_0603_1608Metric
TP_IO0 | 1 | IO0 | TestPoint_Pad_D2.0mm
JP_RS485_BIAS_B | 1 | BIAS B | SolderJumper-2_P1.3mm_Open_Pad1.0x1.5mm
J_BAT | 1 | BATT 45-54V | TerminalBlock_Phoenix_MKDS-1,5-2-5.08_1x02_P5.08mm_Horizontal
C30, C31 | 2 | 10nF 50V X7R | C_0603_1608Metric
TP_RELAY_RET | 1 | RELAY_RET | TestPoint_Pad_D2.0mm
U8 | 1 | MAX3485CSA+ | SOIC-8_3.9x4.9mm_P1.27mm
TP_ACS2_ADC | 1 | ACS2_ADC | TestPoint_Pad_D2.0mm
J_RS485 | 1 | RS485 A/B/GND | TerminalBlock_Phoenix_MKDS-1,5-3-5.08_1x03_P5.08mm_Horizontal
SW1 | 1 | RESET | SW_PUSH_6mm
J_ESTOP | 1 | E-STOP LOOP NC | TerminalBlock_Phoenix_MKDS-1,5-2-5.08_1x02_P5.08mm_Horizontal
D2 | 1 | SMBJ58A | D_SMB
J_RELAY | 1 | RELAY COM/NO DRY | TerminalBlock_Phoenix_MKDS-1,5-2-5.08_1x02_P5.08mm_Horizontal
TP_SHUNT_K- | 1 | SHUNT_K- | TestPoint_Pad_D2.0mm
U3 | 1 | INA219AIDCNR | SOT-23-8
TP_5V | 1 | +5V | TestPoint_Pad_D2.0mm
TP_5V_RELAY | 1 | +5V_RELAY | TestPoint_Pad_D2.0mm
C52 | 1 | 47uF 25V X5R | C_1210_3225Metric
U9 | 1 | SN65HVD230DR | SOIC-8_3.9x4.9mm_P1.27mm
R51, R52 | 2 | 680R 1% | R_0603_1608Metric
K1 | 1 | HF115F-1/5V-H | Relay_HF115F_1
J_RELAY_EXP | 1 | RELAY EXP 5V/GND/SDA/SCL/INT | PinHeader_2x03_P2.54mm_Vertical
R55 | 1 | 1k 1% | R_0603_1608Metric
C60, C62, C80 | 3 | 10uF 16V X5R | C_0805_2012Metric
F1 | 1 | 0.5A T 63V | Fuse_1206_3216Metric
M1 | 1 | LM2596HVS 5V | Module_LM2596HVS
F2 | 1 | 0.5A hold | Fuse_1812_4532Metric
C57 | 1 | 47uF 100V | CP_Elec_10x10.5
TP_BAT+ | 1 | BAT+ | TestPoint_Pad_D2.0mm
J_CAN | 1 | CAN CANH/CANL/GND | TerminalBlock_Phoenix_MKDS-1,5-3-5.08_1x03_P5.08mm_Horizontal
J1 | 1 | GCT USB4105-GF-A | USB_C_Receptacle_GCT_USB4105-xx-A_16P_TopMnt_Horizontal
D30 | 1 | BAV199 | SOT-23
J_ACS2, J_ACS1 | 2 | DT-55-B01X-02 | TerminalBlock_Dinkle_DT-55-B01X-02_P10.00mm
R21 | 1 | 5.6k 1% | R_0603_1608Metric
TP_RELAY_CTRL | 1 | RELAY_CTRL | TestPoint_Pad_D2.0mm
TP_ACS1_ADC | 1 | ACS1_ADC | TestPoint_Pad_D2.0mm
TP_ESTOP | 1 | E_STOP_SENSE | TestPoint_Pad_D2.0mm
R22 | 1 | 2.2k 1% | R_0603_1608Metric
U12 | 1 | USBLC6-2SC6 | SOT-23-6
D21 | 1 | SS14 40V/1A | D_SMA
JP_RS485_BIAS_A | 1 | BIAS A | SolderJumper-2_P1.3mm_Open_Pad1.0x1.5mm
NT2 | 1 | NET-TIE DGND-PGND (DIGITAL) | NetTie-2_SMD_Pad2.0mm
D1 | 1 | US1M-13-F | D_SMA
D20 | 1 | CDSOT23-T24CAN | SOT-23
J_I2C_EXP | 1 | I2C EXP 3V3/GND/SDA/SCL | PinHeader_1x04_P2.54mm_Vertical
TP_UART_TX | 1 | UART0_TX | TestPoint_Pad_D2.0mm
C50 | 1 | 2.2uF 100V X7R | C_0603_1608Metric
J_PZEM_AC | 1 | MAINS L/N 250VAC | TerminalBlock_Phoenix_MKDS-1,5-2-5.08_1x02_P5.08mm_Horizontal
U11 | 1 | AP2112K-3.3 | SOT-23-5
U1 | 1 | ESP32-WROOM-32E | ESP32-WROOM-32E
BT1 | 1 | CR2032 3V | BatteryHolder_Keystone_106_1x20mm
RV3 | 1 | MOV 275VAC DNP | RV_Disc_D21.5mm_W5mm_P10mm

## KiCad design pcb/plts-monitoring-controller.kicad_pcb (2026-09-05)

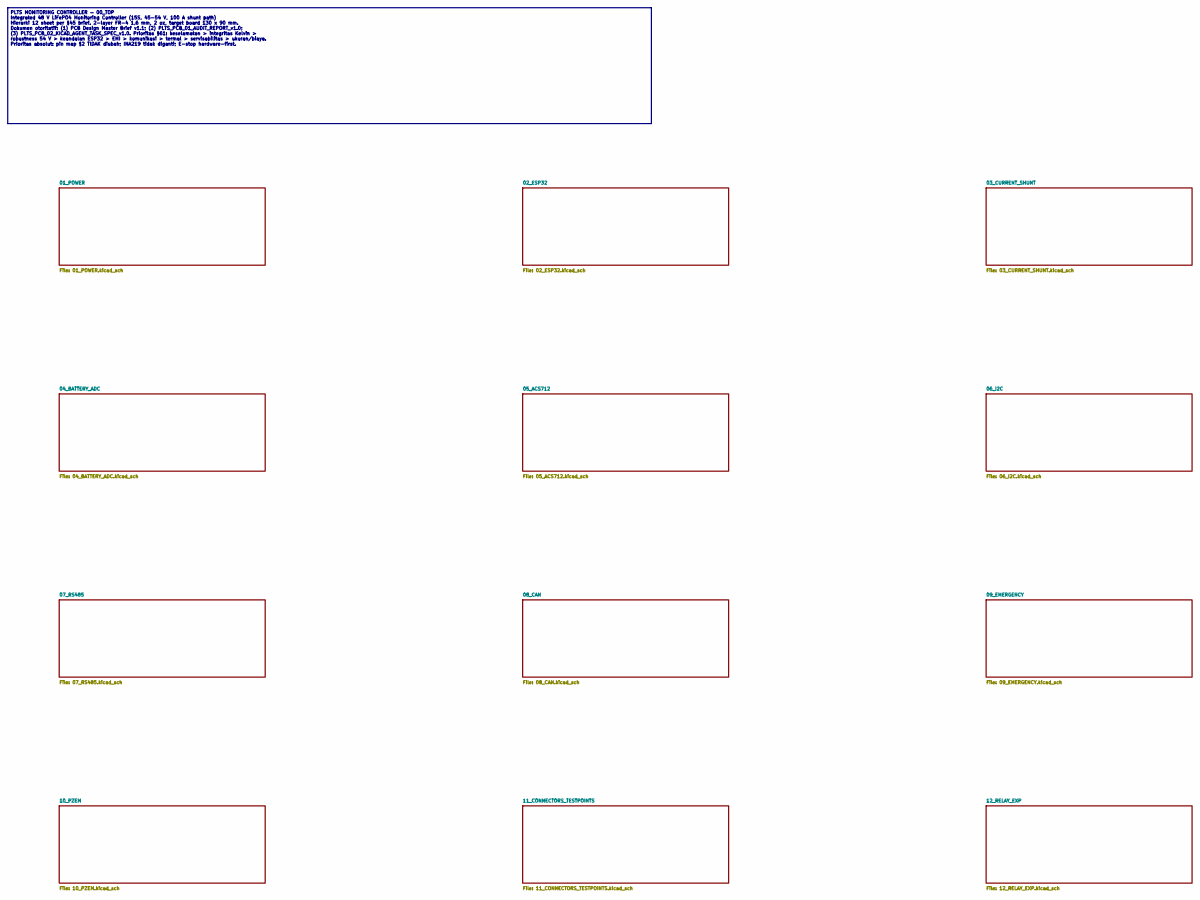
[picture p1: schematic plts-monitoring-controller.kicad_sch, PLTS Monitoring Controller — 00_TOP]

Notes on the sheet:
PLTS MONITORING CONTROLLER — 00_TOP Integrated 48 V LiFePO4 Monitoring Controller (15S, 45-54 V, 100 A shunt path) Hierarki 12 sheet per §45 brief. 2-layer FR-4 1,6 mm, 2 oz, target board 130 x 90 mm. Dokumen otoritatif: (1) PCB Design Master Brief v1.1; (2) PLTS_PCB_01_AUDIT_REPORT_v1.0; (3) PLTS_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

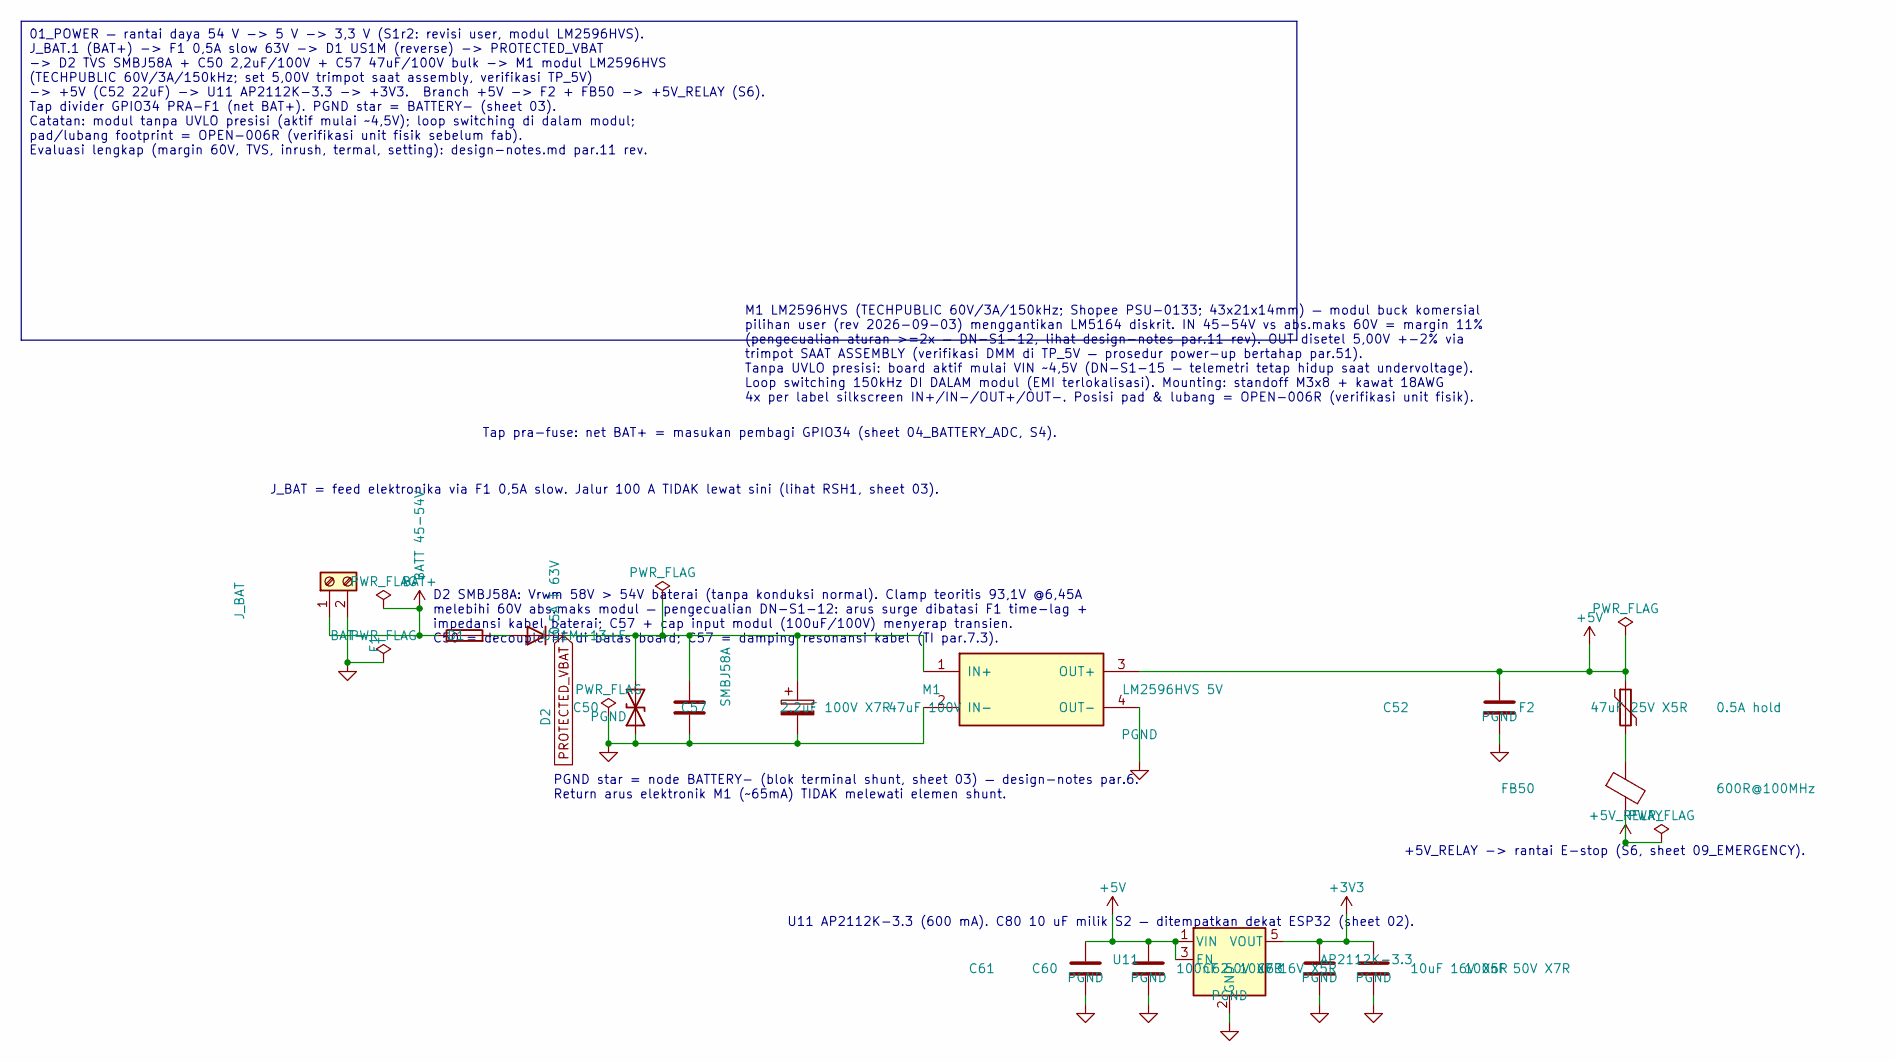
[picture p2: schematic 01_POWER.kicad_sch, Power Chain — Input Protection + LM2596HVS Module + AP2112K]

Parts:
C50: 2.2uF 100V X7R; C_1210_3225Metric
C52: 47uF 25V X5R; C_1210_3225Metric
C57: 47uF 100V; CP_Elec_10x10.5
C60, C62: 10uF 16V X5R; C_0805_2012Metric
C61, C63: 100nF 50V X7R; C_0603_1608Metric
D1: US1M-13-F; D_SMA
D2: SMBJ58A; D_SMB
F1: 0.5A T 63V; Fuse_1206_3216Metric
F2: 0.5A hold; Fuse_1812_4532Metric
FB50: 600R@100MHz; L_0805_2012Metric
J_BAT: BATT 45-54V; TerminalBlock_Phoenix_MKDS-1,5-2-5.08_1x02_P5.08mm_Horizont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
M1: LM2596HVS 5V; Module_LM2596HVS
U11: AP2112K-3.3; SOT-23-5

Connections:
+3V3: C62.1, C63.1, U11.5 (VOUT); also elsewhere on the board
+5V: C52.1, C60.1, C61.1, F2.1, M1.3 (OUT+), U11.1 (VIN), U11.3 (EN); also elsewhere on the board
+5V_RELAY: FB50.2; also elsewhere on the board
BAT+: F1.1, J_BAT.1; also elsewhere on the board
BAT-: J_BAT.2; also elsewhere on the board
unnamed: D1.2 (A), F1.2
unnamed: F2.2, FB50.1
PGND: C50.2, C52.2, C57.2, C60.2, C61.2, C62.2, C63.2, D2.1 (A1), M1.2 (IN-), M1.4 (OUT-), U11.2 (GND); also elsewhere on the board
PROTECTED_VBAT: C50.1, C57.1, D1.1 (K), D2.2 (A2), M1.1 (IN+)

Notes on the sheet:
J_BAT = feed elektronika via F1 0,5A slow. Jalur 100 A TIDAK lewat sini (lihat RSH1, sheet 03).
Tap pra-fuse: net BAT+ = masukan pembagi GPIO34 (sheet 04_BATTERY_ADC, S4).
M1 LM2596HVS (TECHPUBLIC 60V/3A/150kHz; Shopee PSU-0133; 43x21x14mm) — modul buck komersial pilihan user (rev 2026-09-03) menggantikan LM5164 diskrit. IN 45-54V vs abs.maks 60V = margin 11% (pengecualian aturan >=2x — DN-S1-12, lihat design-notes par.11 rev). OUT disetel 5,00V +-2% via trimpot SAAT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
D2 SMBJ58A: Vrwm 58V > 54V baterai (tanpa konduksi normal). Clamp teoritis 93,1V @6,45A melebihi 60V abs.maks modul — pengecualian DN-S1-12: arus surge dibatasi F1 time-lag + impedansi kabel baterai; C57 + cap input modul (100uF/100V) menyerap transien. C50 = decouple HF di batas board; C57 = dampi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
PGND star = node BATTERY- (blok terminal shunt, sheet 03) — design-notes par.6. Return arus elektronik M1 (~65mA) TIDAK melewati elemen shunt.
U11 AP2112K-3.3 (600 mA). C80 10 uF milik S2 — ditempatkan dekat ESP32 (sheet 02).
+5V_RELAY -> rantai E-stop (S6, sheet 09_EMERGENCY).
01_POWER — rantai daya 54 V -> 5 V -> 3,3 V (S1r2: revisi user, modul LM2596HVS). J_BAT.1 (BAT+) -> F1 0,5A slow 63V -> D1 US1M (reverse) -> PROTECTED_VBAT -> D2 TVS SMBJ58A + C50 2,2uF/100V + C57 47uF/100V bulk -> M1 modul LM2596HVS (TECHPUBLIC 60V/3A/150kHz; set 5,00V trimpot saat assembly, verif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

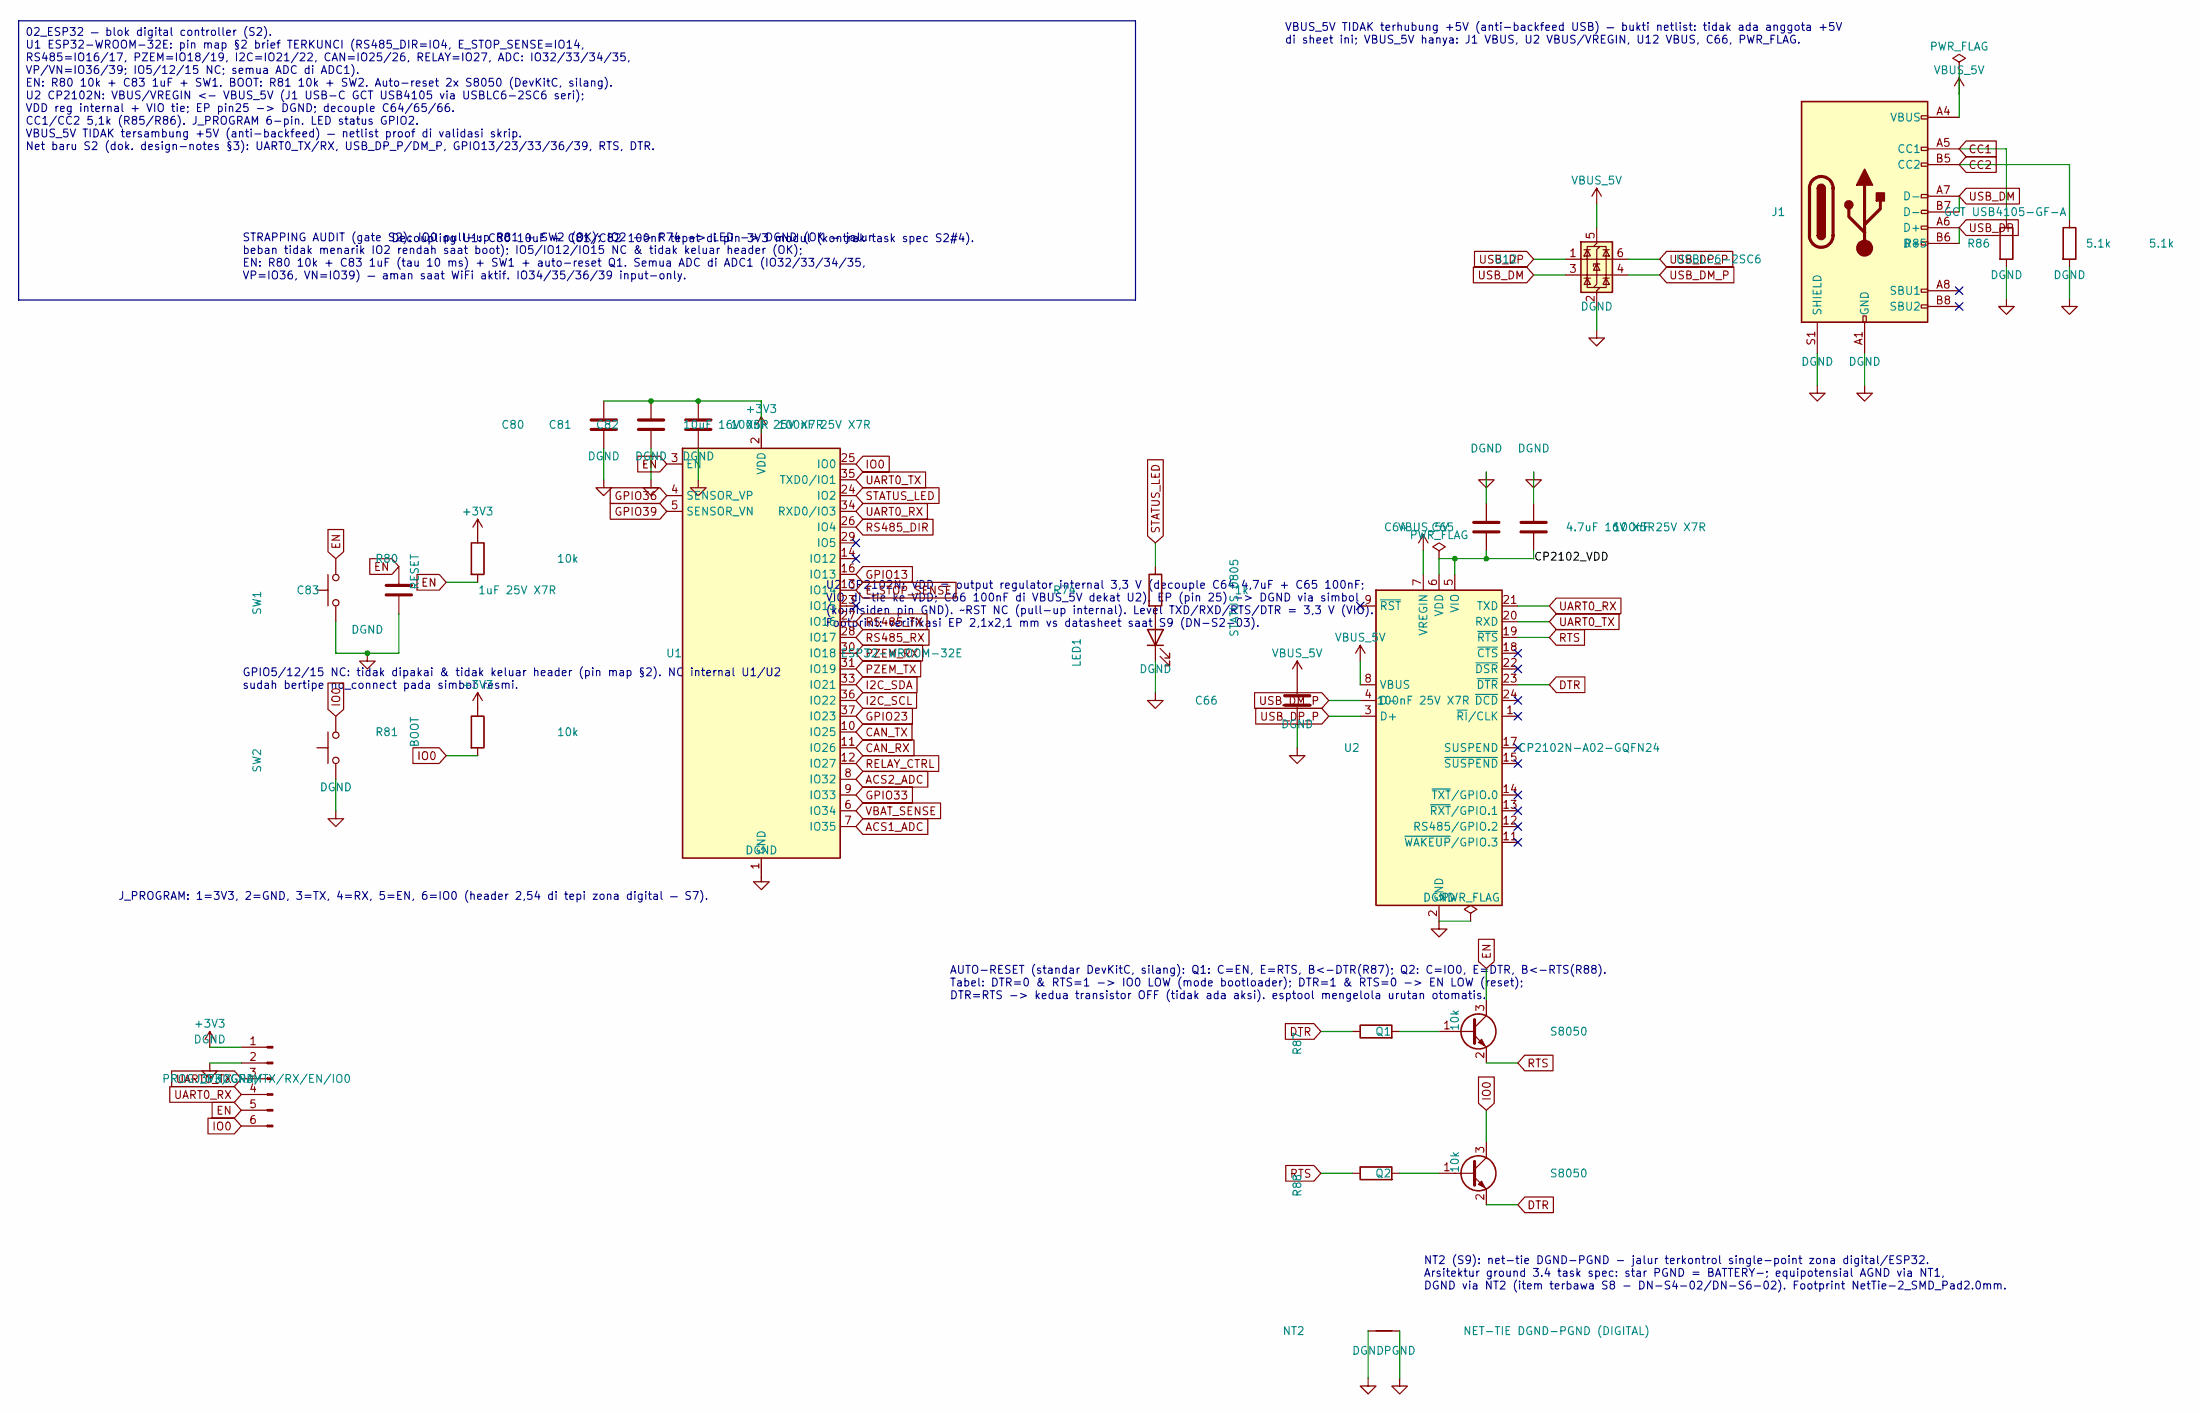
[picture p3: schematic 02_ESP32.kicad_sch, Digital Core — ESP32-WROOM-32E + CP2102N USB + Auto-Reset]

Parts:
C64: 4.7uF 16V X5R; C_0805_2012Metric
C65, C66, C81, C82: 100nF 25V X7R; C_0603_1608Metric
C80: 10uF 16V X5R; C_0805_2012Metric
C83: 1uF 25V X7R; C_0603_1608Metric
J1: GCT USB4105-GF-A; USB_C_Receptacle_GCT_USB4105-xx-A_16P_TopMnt_Horizontal
J_PROGRAM: PROG 3V3/GND/TX/RX/EN/IO0; PinHeader_1x06_P2.54mm_Vertical
LED1: STATUS 0805; LED_0805_2012Metric
NT2: NET-TIE DGND-PGND (DIGITAL); NetTie-2_SMD_Pad2.0mm
Q1, Q2: S8050; SOT-23
R74: 1k; R_0603_1608Metric
R80, R81, R87, R88: 10k; R_0603_1608Metric
R85, R86: 5.1k; R_0603_1608Metric
SW1: RESET; SW_PUSH_6mm
SW2: BOOT; SW_PUSH_6mm
U1: ESP32-WROOM-32E
U2: CP2102N-A02-GQFN24; HVQFN-24-1EP_4x4mm_P0.5mm_EP2.1x2.1mm
U12: USBLC6-2SC6; SOT-23-6

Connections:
+3V3: C80.1, C81.1, C82.1, J_PROGRAM.1, R80.1, R81.1, U1.2 (VDD); also elsewhere on the board
/02_ESP32/CP2102_VDD: C64.2, C65.2, U2.5 (VIO), U2.6 (VDD)
ACS1_ADC: U1.7 (IO35); also elsewhere on the board
ACS2_ADC: U1.8 (IO32); also elsewhere on the board
CAN_RX: U1.11 (IO26); also elsewhere on the board
CAN_TX: U1.10 (IO25); also elsewhere on the board
CC1: J1.A5 (CC1), R85.1
CC2: J1.B5 (CC2), R86.1
DGND: C64.1, C65.1, C66.2, C80.2, C81.2, C82.2, C83.2, J1.A1 (GND), J1.A12 (GND), J1.B1 (GND), J1.B12 (GND), J1.S1 (SHIELD), J_PROGRAM.2, LED1.1 (K), NT2.1, R85.2, R86.2, SW1.1, SW2.1, U1.1 (GND), U1.15 (GND), U1.38 (GND), U1.39 (GND), U2.2 (GND), U2.25 (GND), U12.2 (GND); also elsewhere on the board
DTR: Q2.2 (E), R87.1, U2.23 (~DTR)
EN: C83.1, J_PROGRAM.5, Q1.3 (C), R80.2, SW1.2, U1.3 (EN); also elsewhere on the board
E_STOP_SENSE: U1.13 (IO14); also elsewhere on the board
GPIO13: U1.16 (IO13); also elsewhere on the board
GPIO23: U1.37 (IO23); also elsewhere on the board
GPIO33: U1.9 (IO33); also elsewhere on the board
GPIO36: U1.4 (SENSOR_VP); also elsewhere on the board
GPIO39: U1.5 (SENSOR_VN); also elsewhere on the board
I2C_SCL: U1.36 (IO22); also elsewhere on the board
I2C_SDA: U1.33 (IO21); also elsewhere on the board
IO0: J_PROGRAM.6, Q2.3 (C), R81.2, SW2.2, U1.25 (IO0); also elsewhere on the board
unnamed: LED1.2 (A), R74.2
unnamed: Q1.1 (B), R87.2
unnamed: Q2.1 (B), R88.2
PGND: NT2.2; also elsewhere on the board
PZEM_RX: U1.30 (IO18); also elsewhere on the board
PZEM_TX: U1.31 (IO19); also elsewhere on the board
RELAY_CTRL: U1.12 (IO27); also elsewhere on the board
RS485_DIR: U1.26 (IO4); also elsewhere on the board
RS485_RX: U1.28 (IO17); also elsewhere on the board
RS485_TX: U1.27 (IO16); also elsewhere on the board
RTS: Q1.2 (E), R88.1, U2.19 (~RTS)
STATUS_LED: R74.1, U1.24 (IO2)
UART0_RX: J_PROGRAM.4, U1.34 (RXD0/IO3), U2.21 (TXD); also elsewhere on the board
UART0_TX: J_PROGRAM.3, U1.35 (TXD0/IO1), U2.20 (RXD); also elsewhere on the board
USB_DM: J1.A7 (D-), J1.B7 (D-), U12.3 (I/O2)
USB_DM_P: U2.4 (D-), U12.4 (I/O2)
USB_DP: J1.A6 (D+), J1.B6 (D+), U12.1 (I/O1)
USB_DP_P: U2.3 (D+), U12.6 (I/O1)
VBAT_SENSE: U1.6 (IO34); also elsewhere on the board
VBUS_5V: C66.1, J1.A4 (VBUS), J1.A9 (VBUS), J1.B4 (VBUS), J1.B9 (VBUS), U2.7 (VREGIN), U2.8 (VBUS), U12.5 (VBUS)

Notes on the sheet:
STRAPPING AUDIT (gate S2): IO0 pull-up R81 + SW2 (OK); IO2 -> R74 -> LED -> DGND (OK — jalur beban tidak menarik IO2 rendah saat boot); IO5/IO12/IO15 NC & tidak keluar header (OK); EN: R80 10k + C83 1uF (tau 10 ms) + SW1 + auto-reset Q1. Semua ADC di ADC1 (IO32/33/34/35, VP=IO36, VN=IO39) — aman sa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
AUTO-RESET (standar DevKitC, silang): Q1: C=EN, E=RTS, B<-DTR(R87); Q2: C=IO0, E=DTR, B<-RTS(R88). Tabel: DTR=0 & RTS=1 -> IO0 LOW (mode bootloader); DTR=1 & RTS=0 -> EN LOW (reset); DTR=RTS -> kedua transistor OFF (tidak ada aksi). esptool mengelola urutan otomatis.
VBUS_5V TIDAK terhubung +5V (anti-backfeed USB) — bukti netlist: tidak ada anggota +5V di sheet ini; VBUS_5V hanya: J1 VBUS, U2 VBUS/VREGIN, U12 VBUS, C66, PWR_FLAG.
U2 CP2102N: VDD = output regulator internal 3,3 V (decouple C64 4,7uF + C65 100nF; VIO di-tie ke VDD; C66 100nF di VBUS_5V dekat U2). EP (pin 25) -> DGND via simbol (koinisiden pin GND). ~RST NC (pull-up internal). Level TXD/RXD/RTS/DTR = 3,3 V (VIO). Footprint: verifikasi EP 2,1x2,1 mm vs datashee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
Decoupling U1: C80 10uF + C81/C82 100nF tepat di pin 3V3 modul (kontrak task spec S2#4).
J_PROGRAM: 1=3V3, 2=GND, 3=TX, 4=RX, 5=EN, 6=IO0 (header 2,54 di tepi zona digital — S7).
GPIO5/12/15 NC: tidak dipakai & tidak keluar header (pin map §2). NC internal U1/U2 sudah bertipe no_connect pada simbol resmi.
02_ESP32 — blok digital controller (S2). U1 ESP32-WROOM-32E: pin map §2 brief TERKUNCI (RS485_DIR=IO4, E_STOP_SENSE=IO14, RS485=IO16/17, PZEM=IO18/19, I2C=IO21/22, CAN=IO25/26, RELAY=IO27, ADC: IO32/33/34/35, VP/VN=IO36/39; IO5/12/15 NC; semua ADC di ADC1). EN: R80 10k + C83 1uF + SW1. BOOT: R81 10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
NT2 (S9): net-tie DGND-PGND - jalur terkontrol single-point zona digital/ESP32. Arsitektur ground 3.4 task spec: star PGND = BATTERY-; equipotensial AGND via NT1, DGND via NT2 (item terbawa S8 - DN-S4-02/DN-S6-02). Footprint NetTie-2_SMD_Pad2.0mm.

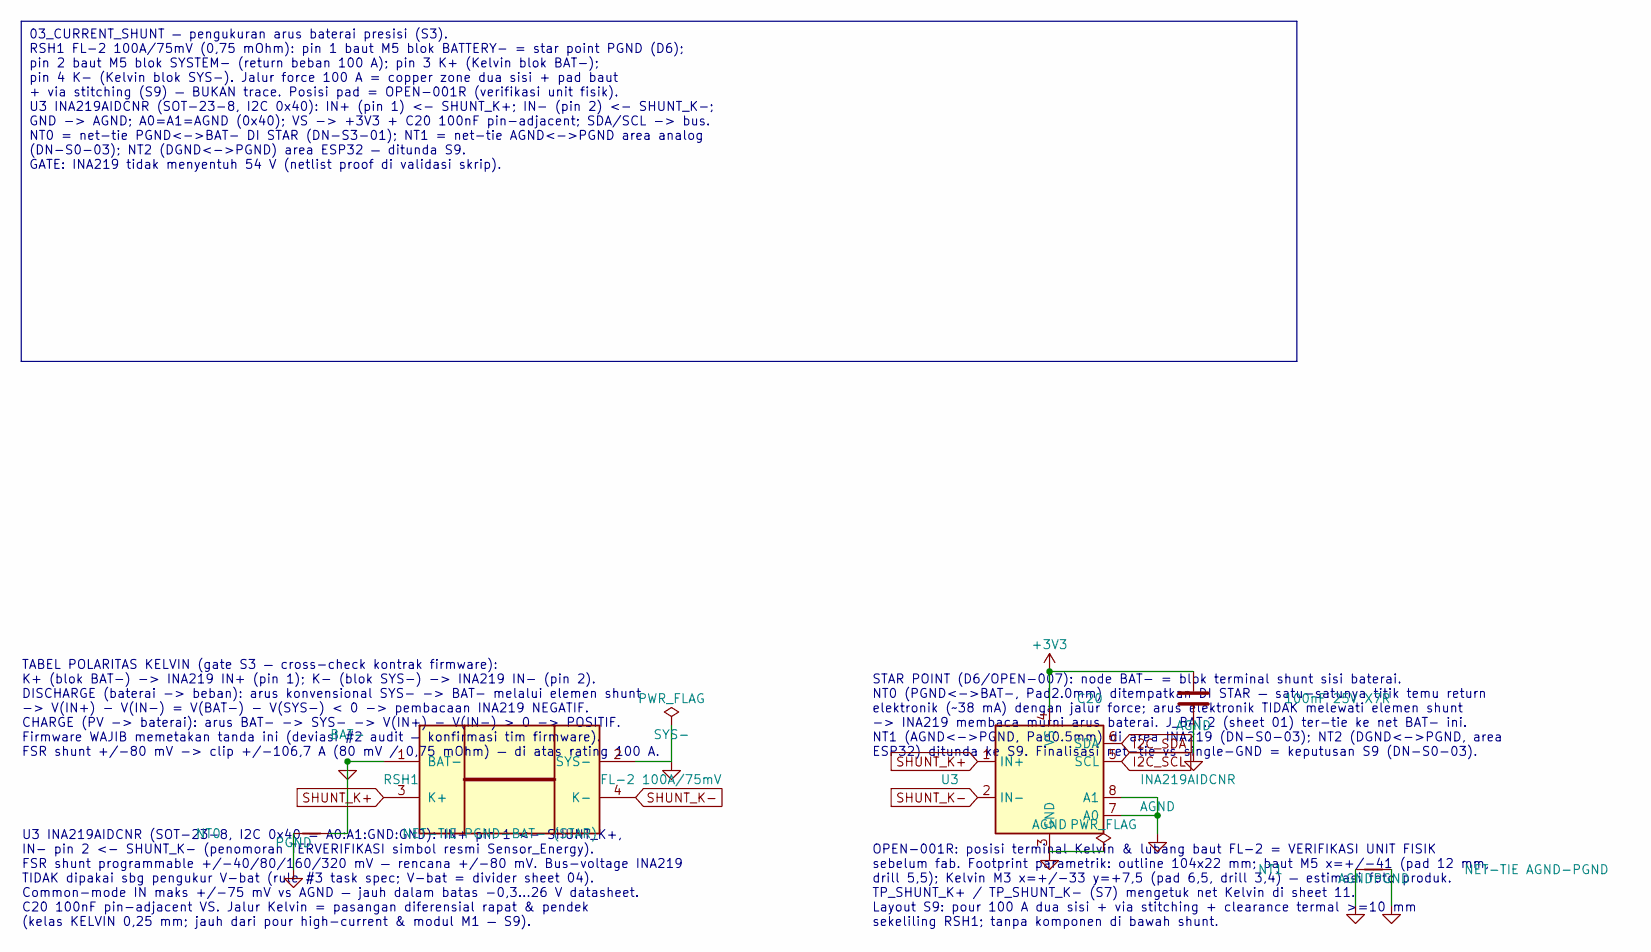
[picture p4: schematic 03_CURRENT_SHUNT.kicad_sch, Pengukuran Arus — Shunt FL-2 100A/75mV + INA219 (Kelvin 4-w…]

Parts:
C20: 100nF 25V X7R; C_0603_1608Metric
NT0: NET-TIE PGND-BAT- (STAR); NetTie-2_SMD_Pad2.0mm
NT1: NET-TIE AGND-PGND; NetTie-2_SMD_Pad0.5mm
RSH1: FL-2 100A/75mV; Shunt_FL2_100A
U3: INA219AIDCNR; SOT-23-8

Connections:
+3V3: C20.1, U3.4 (VS); also elsewhere on the board
AGND: C20.2, NT1.1, U3.3 (GND), U3.7 (A0), U3.8 (A1); also elsewhere on the board
BAT-: NT0.2, RSH1.1 (BAT-); also elsewhere on the board
I2C_SCL: U3.5 (SCL); also elsewhere on the board
I2C_SDA: U3.6 (SDA); also elsewhere on the board
PGND: NT0.1, NT1.2; also elsewhere on the board
SHUNT_K+: RSH1.3 (K+), U3.1 (IN+); also elsewhere on the board
SHUNT_K-: RSH1.4 (K-), U3.2 (IN-); also elsewhere on the board
SYS-: RSH1.2 (SYS-)

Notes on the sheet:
TABEL POLARITAS KELVIN (gate S3 — cross-check kontrak firmware): K+ (blok BAT-) -> INA219 IN+ (pin 1); K- (blok SYS-) -> INA219 IN- (pin 2). DISCHARGE (baterai -> beban): arus konvensional SYS- -> BAT- melalui elemen shunt -> V(IN+) - V(IN-) = V(BAT-) - V(SYS-) < 0 -> pembacaan INA219 NEGATIF. CHAR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
STAR POINT (D6/OPEN-007): node BAT- = blok terminal shunt sisi baterai. NT0 (PGND<->BAT-, Pad2.0mm) ditempatkan DI STAR — satu-satunya titik temu return elektronik (~38 mA) dengan jalur force; arus elektronik TIDAK melewati elemen shunt -> INA219 membaca murni arus baterai. J_BAT.2 (sheet 01) ter-t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
U3 INA219AIDCNR (SOT-23-8, I2C 0x40 = A0:A1:GND:GND): IN+ pin 1 <- SHUNT_K+, IN- pin 2 <- SHUNT_K- (penomoran TERVERIFIKASI simbol resmi Sensor_Energy). FSR shunt programmable +/-40/80/160/320 mV — rencana +/-80 mV. Bus-voltage INA219 TIDAK dipakai sbg pengukur V-bat (rule #3 task spec; V-bat = div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
OPEN-001R: posisi terminal Kelvin & lubang baut FL-2 = VERIFIKASI UNIT FISIK sebelum fab. Footprint parametrik: outline 104x22 mm; baut M5 x=+/-41 (pad 12 mm, drill 5,5); Kelvin M3 x=+/-33 y=+7,5 (pad 6,5, drill 3,4) — estimasi foto produk. TP_SHUNT_K+ / TP_SHUNT_K- (S7) mengetuk net Kelvin di shee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
03_CURRENT_SHUNT — pengukuran arus baterai presisi (S3). RSH1 FL-2 100A/75mV (0,75 mOhm): pin 1 baut M5 blok BATTERY- = star point PGND (D6); pin 2 baut M5 blok SYSTEM- (return beban 100 A); pin 3 K+ (Kelvin blok BAT-); pin 4 K- (Kelvin blok SYS-). Jalur force 100 A = copper zone dua sisi + pad bau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

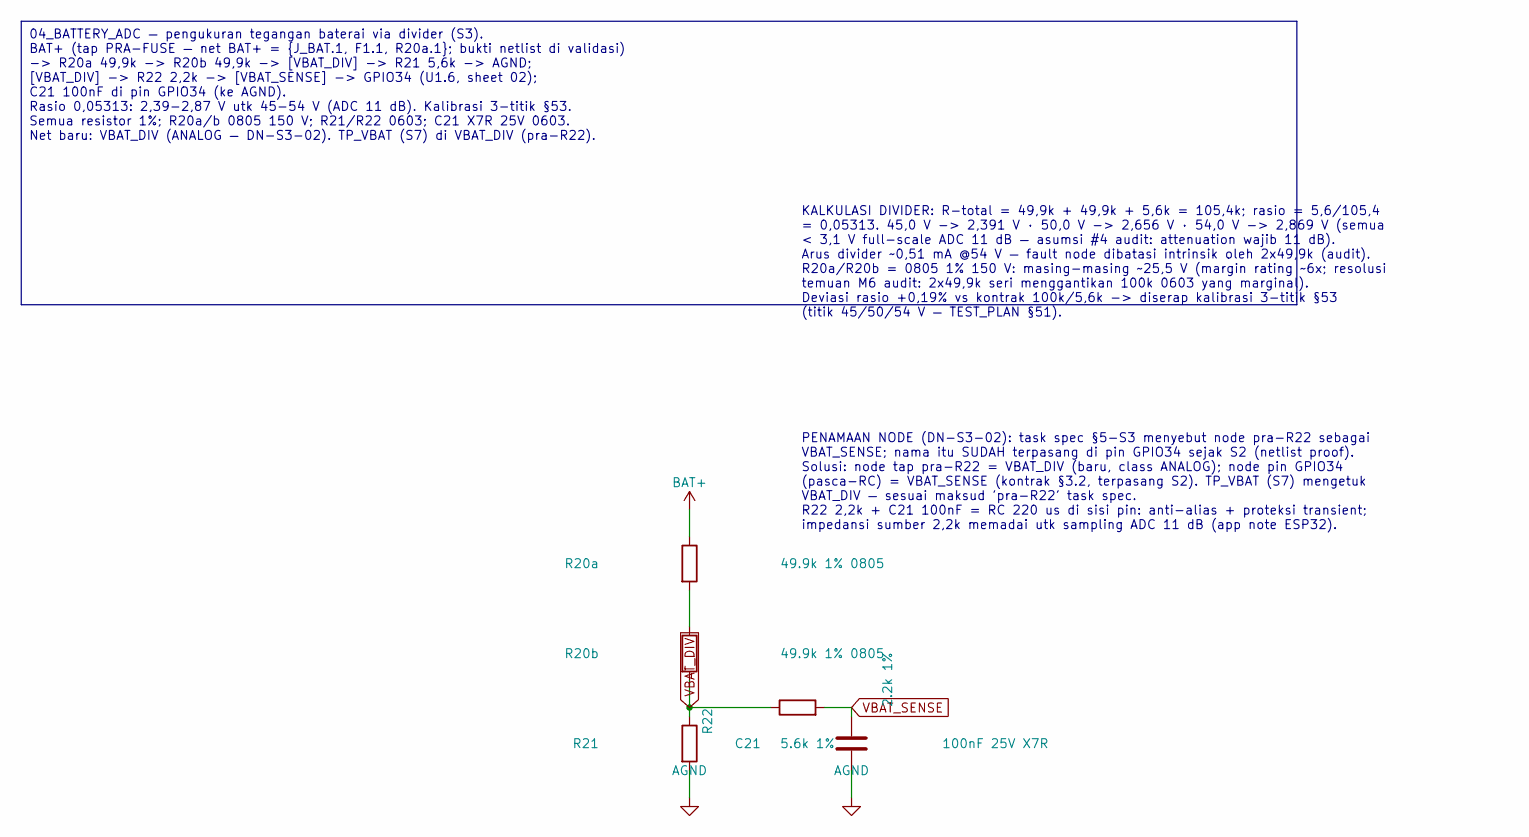
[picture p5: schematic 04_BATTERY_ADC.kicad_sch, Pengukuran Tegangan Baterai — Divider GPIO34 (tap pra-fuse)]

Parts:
C21: 100nF 25V X7R; C_0603_1608Metric
R20a, R20b: 49.9k 1% 0805; R_0805_2012Metric
R21: 5.6k 1%; R_0603_1608Metric
R22: 2.2k 1%; R_0603_1608Metric

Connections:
AGND: C21.2, R21.2; also elsewhere on the board
BAT+: R20a.1; also elsewhere on the board
unnamed: R20a.2, R20b.1
VBAT_DIV: R20b.2, R21.1, R22.1; also elsewhere on the board
VBAT_SENSE: C21.1, R22.2; also elsewhere on the board

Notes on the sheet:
KALKULASI DIVIDER: R-total = 49,9k + 49,9k + 5,6k = 105,4k; rasio = 5,6/105,4 = 0,05313. 45,0 V -> 2,391 V · 50,0 V -> 2,656 V · 54,0 V -> 2,869 V (semua < 3,1 V full-scale ADC 11 dB — asumsi #4 audit: attenuation wajib 11 dB). Arus divider ~0,51 mA @54 V — fault node dibatasi intrinsik oleh 2x49,9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
PENAMAAN NODE (DN-S3-02): task spec §5-S3 menyebut node pra-R22 sebagai VBAT_SENSE; nama itu SUDAH terpasang di pin GPIO34 sejak S2 (netlist proof). Solusi: node tap pra-R22 = VBAT_DIV (baru, class ANALOG); node pin GPIO34 (pasca-RC) = VBAT_SENSE (kontrak §3.2, terpasang S2). TP_VBAT (S7) mengetuk 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
04_BATTERY_ADC — pengukuran tegangan baterai via divider (S3). BAT+ (tap PRA-FUSE — net BAT+ = {J_BAT.1, F1.1, R20a.1}; bukti netlist di validasi) -> R20a 49,9k -> R20b 49,9k -> [VBAT_DIV] -> R21 5,6k -> AGND; [VBAT_DIV] -> R22 2,2k -> [VBAT_SENSE] -> GPIO34 (U1.6, sheet 02); C21 100nF di pin GPIO3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

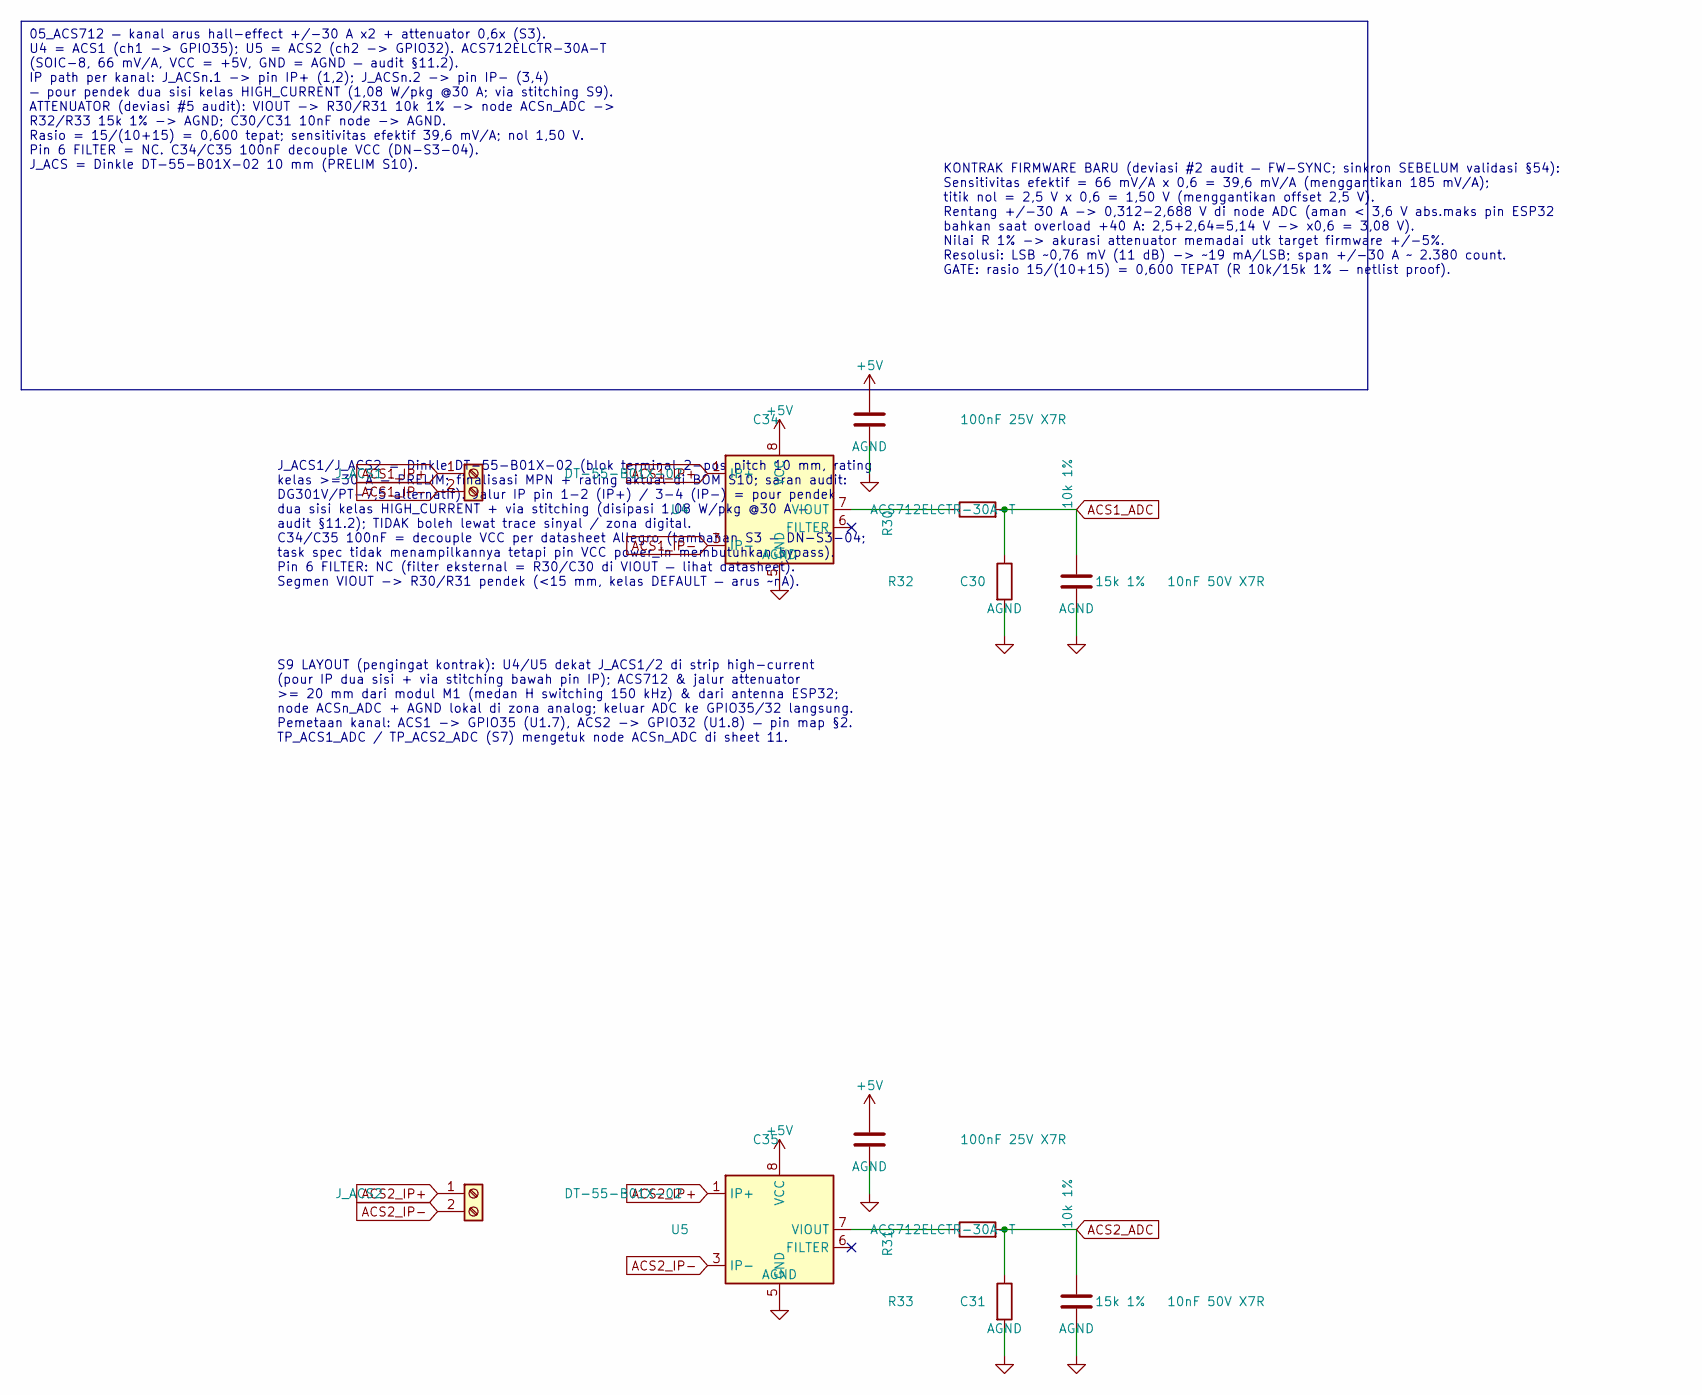
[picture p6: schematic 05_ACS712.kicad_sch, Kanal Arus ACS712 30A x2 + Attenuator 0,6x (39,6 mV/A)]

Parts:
C30, C31: 10nF 50V X7R; C_0603_1608Metric
C34, C35: 100nF 25V X7R; C_0603_1608Metric
J_ACS1, J_ACS2: DT-55-B01X-02; TerminalBlock_Dinkle_DT-55-B01X-02_P10.00mm
R30, R31: 10k 1%; R_0603_1608Metric
R32, R33: 15k 1%; R_0603_1608Metric
U4, U5: ACS712ELCTR-30A-T; SOIC-8_3.9x4.9mm_P1.27mm

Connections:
+5V: C34.1, C35.1, U4.8 (VCC), U5.8 (VCC); also elsewhere on the board
ACS1_ADC: C30.1, R30.2, R32.1; also elsewhere on the board
ACS1_IP+: J_ACS1.1, U4.1 (IP+), U4.2 (IP+)
ACS1_IP-: J_ACS1.2, U4.3 (IP-), U4.4 (IP-)
ACS2_ADC: C31.1, R31.2, R33.1; also elsewhere on the board
ACS2_IP+: J_ACS2.1, U5.1 (IP+), U5.2 (IP+)
ACS2_IP-: J_ACS2.2, U5.3 (IP-), U5.4 (IP-)
AGND: C30.2, C31.2, C34.2, C35.2, R32.2, R33.2, U4.5 (GND), U5.5 (GND); also elsewhere on the board
unnamed: R30.1, U4.7 (VIOUT)
unnamed: R31.1, U5.7 (VIOUT)

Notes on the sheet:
KONTRAK FIRMWARE BARU (deviasi #2 audit — FW-SYNC; sinkron SEBELUM validasi §54): Sensitivitas efektif = 66 mV/A x 0,6 = 39,6 mV/A (menggantikan 185 mV/A); titik nol = 2,5 V x 0,6 = 1,50 V (menggantikan offset 2,5 V). Rentang +/-30 A -> 0,312-2,688 V di node ADC (aman < 3,6 V abs.maks pin ESP32 bah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
J_ACS1/J_ACS2 = Dinkle DT-55-B01X-02 (blok terminal 2-pos pitch 10 mm, rating kelas >=30 A — PRELIM; finalisasi MPN + rating aktual di BOM S10; saran audit: DG301V/PT-7,5 alternatif). Jalur IP pin 1-2 (IP+) / 3-4 (IP-) = pour pendek dua sisi kelas HIGH_CURRENT + via stitching (disipasi 1,08 W/pkg @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
S9 LAYOUT (pengingat kontrak): U4/U5 dekat J_ACS1/2 di strip high-current (pour IP dua sisi + via stitching bawah pin IP); ACS712 & jalur attenuator >= 20 mm dari modul M1 (medan H switching 150 kHz) & dari antenna ESP32; node ACSn_ADC + AGND lokal di zona analog; keluar ADC ke GPIO35/32 langsung. 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
05_ACS712 — kanal arus hall-effect +/-30 A x2 + attenuator 0,6x (S3). U4 = ACS1 (ch1 -> GPIO35); U5 = ACS2 (ch2 -> GPIO32). ACS712ELCTR-30A-T (SOIC-8, 66 mV/A, VCC = +5V, GND = AGND — audit §11.2). IP path per kanal: J_ACSn.1 -> pin IP+ (1,2); J_ACSn.2 -> pin IP- (3,4) — pour pendek dua sisi kelas 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

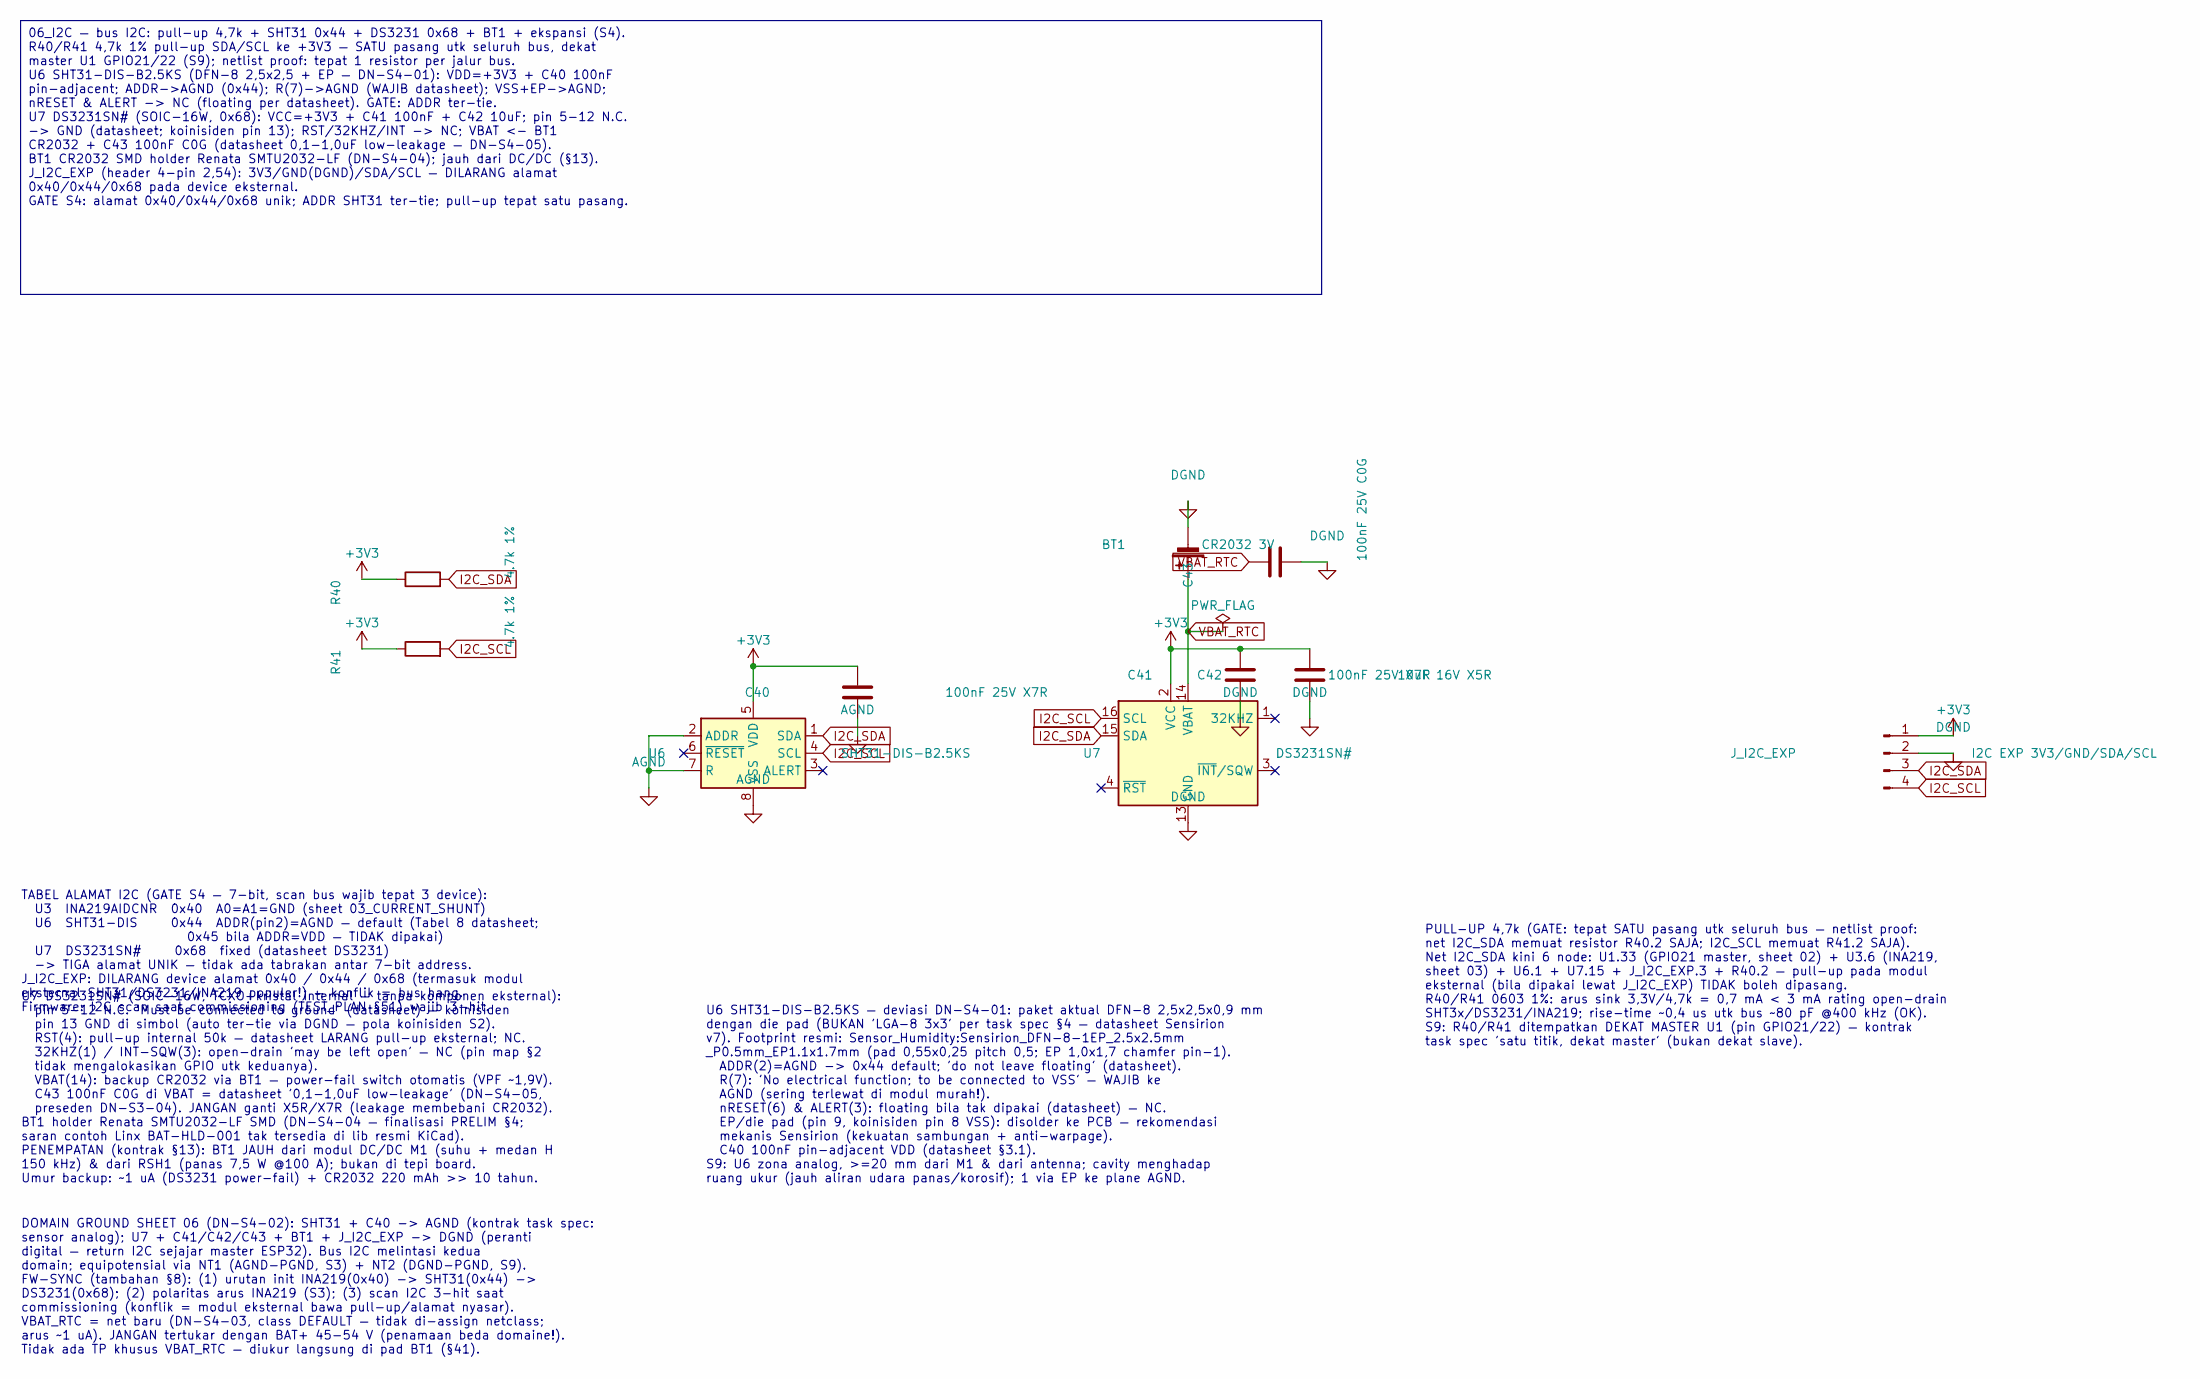
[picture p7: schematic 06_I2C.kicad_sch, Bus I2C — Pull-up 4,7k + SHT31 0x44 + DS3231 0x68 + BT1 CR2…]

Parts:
BT1: CR2032 3V; BatteryHolder_Renata_SMTU2032-LF_1x2032
C40, C41: 100nF 25V X7R; C_0603_1608Metric
C42: 10uF 16V X5R; C_0805_2012Metric
C43: 100nF 25V C0G; C_0603_1608Metric
J_I2C_EXP: I2C EXP 3V3/GND/SDA/SCL; PinHeader_1x04_P2.54mm_Vertical
R40, R41: 4.7k 1%; R_0603_1608Metric
U6: SHT31-DIS-B2.5KS; Sensirion_DFN-8-1EP_2.5x2.5mm_P0.5mm_EP1.1x1.7mm
U7: DS3231SN#; SOIC-16W_7.5x10.3mm_P1.27mm

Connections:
+3V3: C40.1, C41.1, C42.1, J_I2C_EXP.1, R40.1, R41.1, U6.5 (VDD), U7.2 (VCC); also elsewhere on the board
AGND: C40.2, U6.2 (ADDR), U6.7 (R), U6.8 (VSS), U6.9 (VSS); also elsewhere on the board
DGND: BT1.2 (-), C41.2, C42.2, C43.2, J_I2C_EXP.2, U7.5 (GND), U7.6 (GND), U7.7 (GND), U7.8 (GND), U7.9 (GND), U7.10 (GND), U7.11 (GND), U7.12 (GND), U7.13 (GND); also elsewhere on the board
I2C_SCL: J_I2C_EXP.4, R41.2, U6.4 (SCL), U7.16 (SCL); also elsewhere on the board
I2C_SDA: J_I2C_EXP.3, R40.2, U6.1 (SDA), U7.15 (SDA); also elsewhere on the board
VBAT_RTC: BT1.1 (+), C43.1, U7.14 (VBAT)

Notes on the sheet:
TABEL ALAMAT I2C (GATE S4 — 7-bit, scan bus wajib tepat 3 device): U3 INA219AIDCNR 0x40 A0=A1=GND (sheet 03_CURRENT_SHUNT) U6 SHT31-DIS 0x44 ADDR(pin2)=AGND — default (Tabel 8 datasheet; 0x45 bila ADDR=VDD — TIDAK dipakai) U7 DS3231SN# 0x68 fixed (datasheet DS3231) -> TIGA alamat UNIK — tidak ada t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
PULL-UP 4,7k (GATE: tepat SATU pasang utk seluruh bus — netlist proof: net I2C_SDA memuat resistor R40.2 SAJA; I2C_SCL memuat R41.2 SAJA). Net I2C_SDA kini 6 node: U1.33 (GPIO21 master, sheet 02) + U3.6 (INA219, sheet 03) + U6.1 + U7.15 + J_I2C_EXP.3 + R40.2 — pull-up pada modul eksternal (bila dip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
U7 DS3231SN# (SOIC-16W, TCXO+kristal internal — tanpa komponen eksternal): pin 5-12 N.C. 'Must be connected to ground' (datasheet) — koinisiden pin 13 GND di simbol (auto ter-tie via DGND — pola koinisiden S2). RST(4): pull-up internal 50k — datasheet LARANG pull-up eksternal; NC. 32KHZ(1) / INT-SQ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
U6 SHT31-DIS-B2.5KS — deviasi DN-S4-01: paket aktual DFN-8 2,5x2,5x0,9 mm dengan die pad (BUKAN 'LGA-8 3x3' per task spec §4 — datasheet Sensirion v7). Footprint resmi: Sensor_Humidity:Sensirion_DFN-8-1EP_2.5x2.5mm _P0.5mm_EP1.1x1.7mm (pad 0,55x0,25 pitch 0,5; EP 1,0x1,7 chamfer pin-1). ADDR(2)=AGN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
DOMAIN GROUND SHEET 06 (DN-S4-02): SHT31 + C40 -> AGND (kontrak task spec: sensor analog); U7 + C41/C42/C43 + BT1 + J_I2C_EXP -> DGND (peranti digital — return I2C sejajar master ESP32). Bus I2C melintasi kedua domain; equipotensial via NT1 (AGND-PGND, S3) + NT2 (DGND-PGND, S9). FW-SYNC (tambahan §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
06_I2C — bus I2C: pull-up 4,7k + SHT31 0x44 + DS3231 0x68 + BT1 + ekspansi (S4). R40/R41 4,7k 1% pull-up SDA/SCL ke +3V3 — SATU pasang utk seluruh bus, dekat master U1 GPIO21/22 (S9); netlist proof: tepat 1 resistor per jalur bus. U6 SHT31-DIS-B2.5KS (DFN-8 2,5x2,5 + EP — DN-S4-01): VDD=+3V3 + C40 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

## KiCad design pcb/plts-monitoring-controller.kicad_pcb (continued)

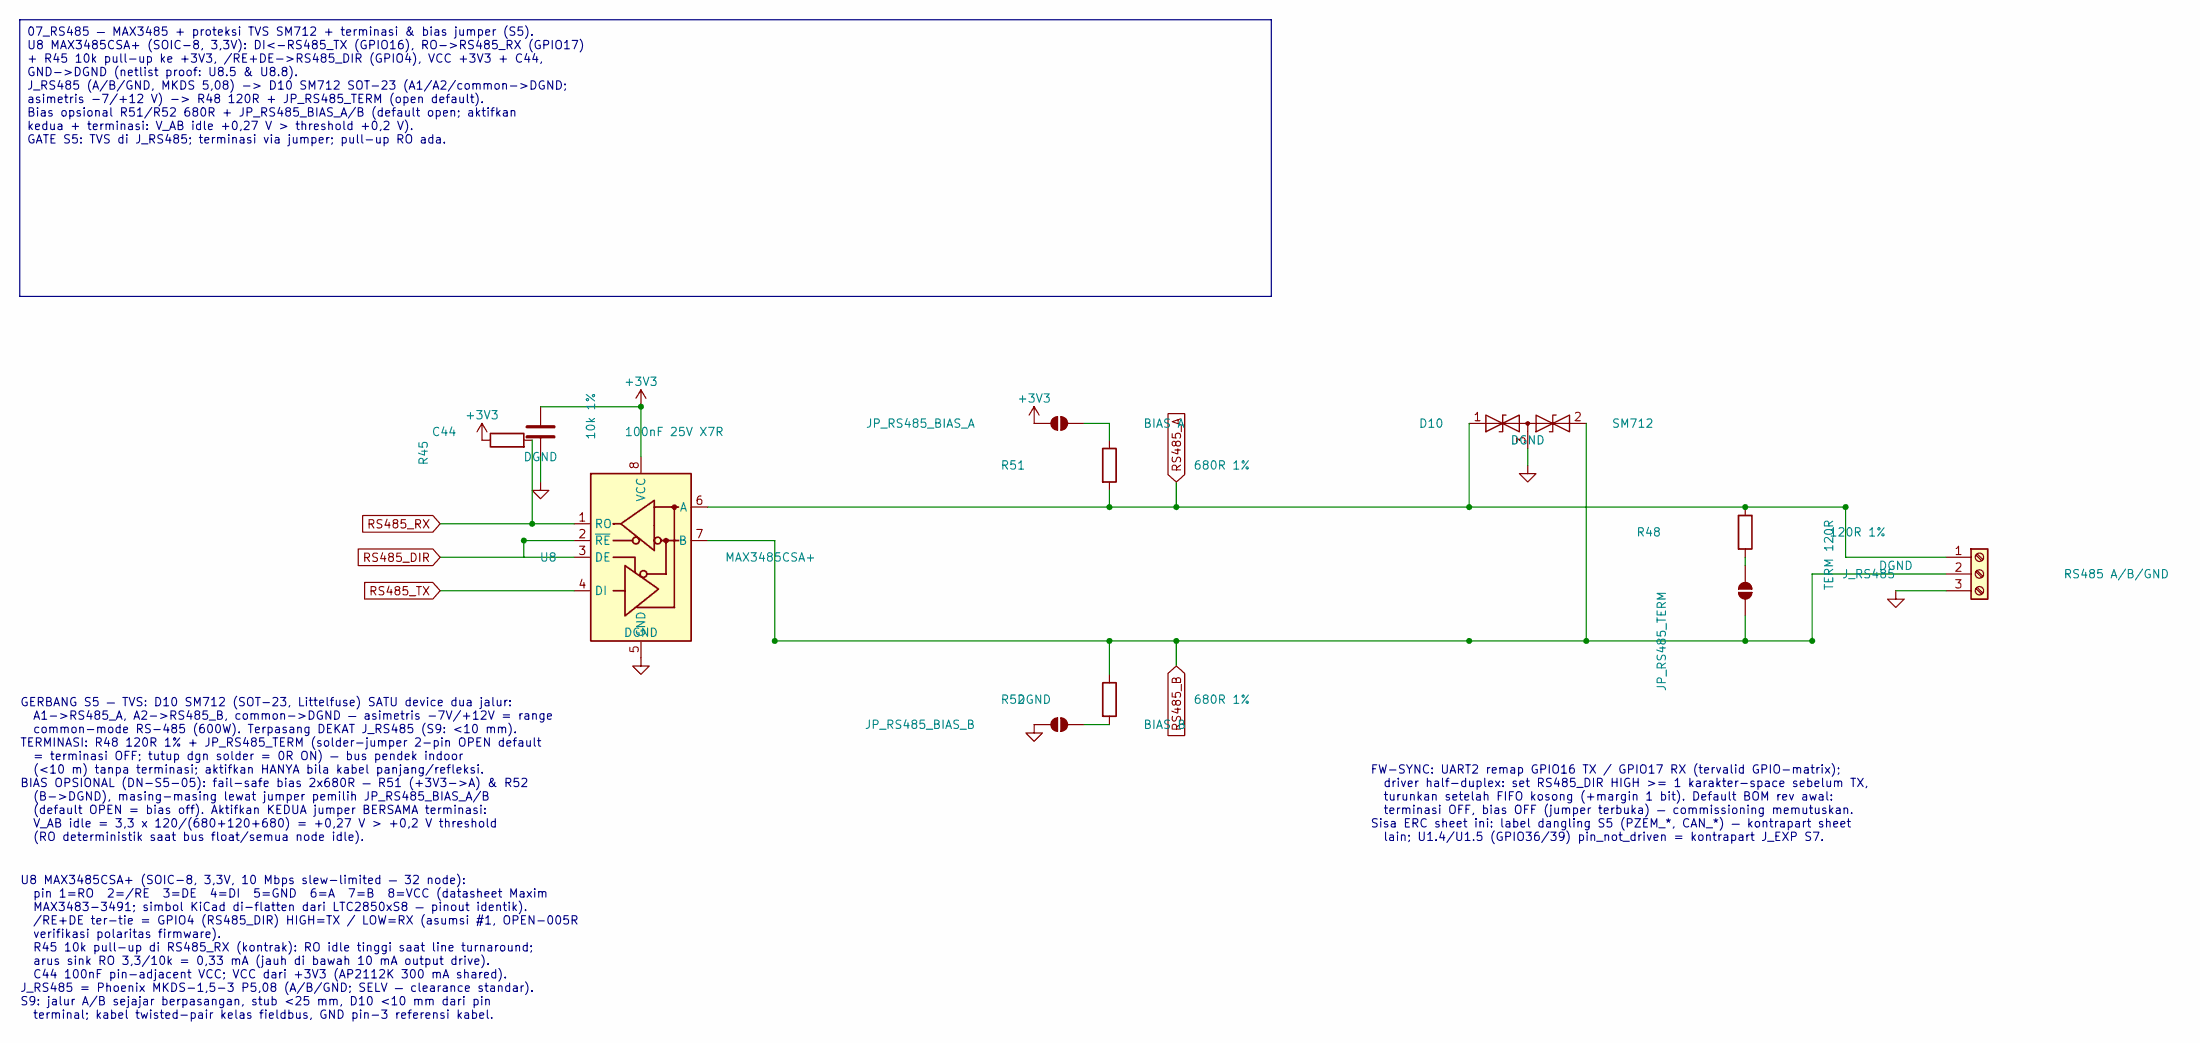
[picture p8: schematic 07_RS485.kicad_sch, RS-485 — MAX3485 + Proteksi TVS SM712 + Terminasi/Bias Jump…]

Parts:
C44: 100nF 25V X7R; C_0603_1608Metric
D10: SM712; SOT-23
JP_RS485_BIAS_A: BIAS A; SolderJumper-2_P1.3mm_Open_Pad1.0x1.5mm
JP_RS485_BIAS_B: BIAS B; SolderJumper-2_P1.3mm_Open_Pad1.0x1.5mm
JP_RS485_TERM: TERM 120R; SolderJumper-2_P1.3mm_Open_Pad1.0x1.5mm
J_RS485: RS485 A/B/GND; TerminalBlock_Phoenix_MKDS-1,5-3-5.08_1x03_P5.08mm_Horizont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
R45: 10k 1%; R_0603_1608Metric
R48: 120R 1%; R_0603_1608Metric
R51, R52: 680R 1%; R_0603_1608Metric
U8: MAX3485CSA+; SOIC-8_3.9x4.9mm_P1.27mm

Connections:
+3V3: C44.1, JP_RS485_BIAS_A.1 (A), R45.1, U8.8 (VCC); also elsewhere on the board
DGND: C44.2, D10.3 (common), JP_RS485_BIAS_B.1 (A), J_RS485.3, U8.5 (GND); also elsewhere on the board
unnamed: JP_RS485_BIAS_A.2 (B), R51.1
unnamed: JP_RS485_BIAS_B.2 (B), R52.2
unnamed: JP_RS485_TERM.2 (B), R48.2
RS485_A: D10.1 (A1), J_RS485.1, R48.1, R51.2, U8.6 (A); also elsewhere on the board
RS485_B: D10.2 (A2), JP_RS485_TERM.1 (A), J_RS485.2, R52.1, U8.7 (B); also elsewhere on the board
RS485_DIR: U8.2 (~RE), U8.3 (DE); also elsewhere on the board
RS485_RX: R45.2, U8.1 (RO); also elsewhere on the board
RS485_TX: U8.4 (DI); also elsewhere on the board

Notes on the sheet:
GERBANG S5 — TVS: D10 SM712 (SOT-23, Littelfuse) SATU device dua jalur: A1->RS485_A, A2->RS485_B, common->DGND — asimetris -7V/+12V = range common-mode RS-485 (600W). Terpasang DEKAT J_RS485 (S9: <10 mm). TERMINASI: R48 120R 1% + JP_RS485_TERM (solder-jumper 2-pin OPEN default = terminasi OFF; tutu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
U8 MAX3485CSA+ (SOIC-8, 3,3V, 10 Mbps slew-limited — 32 node): pin 1=RO 2=/RE 3=DE 4=DI 5=GND 6=A 7=B 8=VCC (datasheet Maxim MAX3483-3491; simbol KiCad di-flatten dari LTC2850xS8 — pinout identik). /RE+DE ter-tie = GPIO4 (RS485_DIR) HIGH=TX / LOW=RX (asumsi #1, OPEN-005R verifikasi polaritas firmwa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
FW-SYNC: UART2 remap GPIO16 TX / GPIO17 RX (tervalid GPIO-matrix); driver half-duplex: set RS485_DIR HIGH >= 1 karakter-space sebelum TX, turunkan setelah FIFO kosong (+margin 1 bit). Default BOM rev awal: terminasi OFF, bias OFF (jumper terbuka) — commissioning memutuskan. Sisa ERC sheet ini: labe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
07_RS485 — MAX3485 + proteksi TVS SM712 + terminasi & bias jumper (S5). U8 MAX3485CSA+ (SOIC-8, 3,3V): DI<-RS485_TX (GPIO16), RO->RS485_RX (GPIO17) + R45 10k pull-up ke +3V3, /RE+DE->RS485_DIR (GPIO4), VCC +3V3 + C44, GND->DGND (netlist proof: U8.5 & U8.8). J_RS485 (A/B/GND, MKDS 5,08) -> D10 SM712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

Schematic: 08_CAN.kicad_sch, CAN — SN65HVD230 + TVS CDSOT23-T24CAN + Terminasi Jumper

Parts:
C70: 100nF 25V X7R; C_0603_1608Metric
D20: CDSOT23-T24CAN; SOT-23
JP_CAN_TERM: TERM 120R; SolderJumper-2_P1.3mm_Open_Pad1.0x1.5mm
J_CAN: CAN CANH/CANL/GND; TerminalBlock_Phoenix_MKDS-1,5-3-5.08_1x03_P5.08mm_Horizont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
R49: 120R 1%; R_0603_1608Metric
U9: SN65HVD230DR; SOIC-8_3.9x4.9mm_P1.27mm

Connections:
+3V3: C70.1, U9.3 (VCC); also elsewhere on the board
CAN_H: D20.1 (CANH), J_CAN.1, R49.1, U9.7 (CANH); also elsewhere on the board
CAN_L: D20.2 (CANL), JP_CAN_TERM.1 (A), J_CAN.2, U9.6 (CANL); also elsewhere on the board
CAN_RX: U9.4 (R); also elsewhere on the board
CAN_TX: U9.1 (D); also elsewhere on the board
DGND: C70.2, D20.3 (GND), J_CAN.3, U9.2 (GND), U9.8 (Rs); also elsewhere on the board
unnamed: JP_CAN_TERM.2 (B), R49.2

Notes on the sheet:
GERBANG S5 — TVS: D20 CDSOT23-T24CAN (Bourns, SOT-23): 1=CANH, 2=CANL, 3=GND — array CAN-rated VRWM 24V (clamping ~40V; aman thd dominant 3,5V/ recessive 2,5V bus 5V + common-mode). TIDAK ada di lib resmi 9.0.2 -> simbol custom plts-custom:TVS_CAN diturunkan programatik dari SM712_SOT23 (topologi p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
U9 SN65HVD230DR (SOIC-8, 3,3V, TI): 1=TXD 2=GND 3=VCC 4=RXD 5=VREF 6=CANL 7=CANH 8=RS. TXD<-CAN_TX (GPIO25, TWAI TX), RXD->CAN_RX (GPIO26). C70 100nF pin-adjacent. Standby/low-power TIDAK dipakai. ESP32 TWAI driver terintegrasi (bit timing 500 kbps — konfig FW). J_CAN = Phoenix MKDS-1,5-3 P5,08 (CA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
FW-SYNC: TWAI (CAN) ESP32 di GPIO25/26 — pin matrix remap valid; dua node PLTS + inverter hybrid: bitrate 500 kbps standar PLTS. Driver SJA1000-compat; filter HW utk ID telemetri. Catatan ERC: VREF NC (output tanpa beban — bukan pelanggaran); label CAN_TX/CAN_RX kontrapart sheet 02 (U1 GPIO25/26).
08_CAN — SN65HVD230 + TVS CDSOT23-T24CAN + terminasi jumper (S5). U9 SN65HVD230DR (SOIC-8, 3,3V): TXD<-CAN_TX (GPIO25), RXD->CAN_RX (GPIO26), RS->DGND LANGSUNG (high-speed — kontrak; netlabel CAN_RS tak terpakai), VCC +3V3 + C70 100nF, GND->DGND, VREF->NC. J_CAN (CANH/CANL/GND, MKDS 5,08) -> D20 CD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

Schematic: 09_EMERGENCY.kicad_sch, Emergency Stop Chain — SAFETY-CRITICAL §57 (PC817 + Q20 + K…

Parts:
C75: 100nF 25V X7R; C_0603_1608Metric
D21: SS14 40V/1A; D_SMA
D22, D23: SMAJ5.0A; D_SMA
J_ESTOP: E-STOP LOOP NC; TerminalBlock_Phoenix_MKDS-1,5-2-5.08_1x02_P5.08mm_Horizont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
J_RELAY: RELAY COM/NO DRY; TerminalBlock_Phoenix_MKDS-1,5-2-5.08_1x02_P5.08mm_Horizont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
K1: HF115F-1/5V-H; Relay_HF115F_1
OPT1: PC817; DIP-4_W7.62mm
Q20: AO3400A; SOT-23
Q21: BSS138; SOT-23
R70: 100R 1%; R_0603_1608Metric
R71, R77: 100k 1%; R_0603_1608Metric
R72: 330R 1%; R_0603_1608Metric
R75: 47k 1%; R_0603_1608Metric
R76, R78: 10k 1%; R_0603_1608Metric

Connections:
+3V3: R72.1, R76.2, R78.2; also elsewhere on the board
+5V: OPT1.4; also elsewhere on the board
+5V_RELAY: D22.2 (A2), J_ESTOP.1; also elsewhere on the board
DGND: C75.2, Q21.2 (S), R77.2; also elsewhere on the board
E_STOP_SENSE: C75.1, Q21.3 (D), R76.1; also elsewhere on the board
unnamed: D21.2 (A), K1.2 (COIL-), Q20.3 (D)
unnamed: J_RELAY.1, K1.3 (COM)
unnamed: J_RELAY.2, K1.4 (NO)
unnamed: OPT1.1, R72.2
unnamed: OPT1.3, R70.1
unnamed: Q20.1 (G), R70.2, R71.1
unnamed: Q21.1 (G), R75.2, R77.1
PGND: D22.1 (A1), D23.1 (A1), Q20.2 (S), R71.2; also elsewhere on the board
RELAY_CTRL: OPT1.2, R78.1; also elsewhere on the board
RELAY_RET: D21.1 (K), D23.2 (A2), J_ESTOP.2, K1.1 (COIL+), R75.1; also elsewhere on the board

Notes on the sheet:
TABEL KEBENARAN §57 — SEMUA KONDISI GAGAL → K1 DE-ENERGIZED (SAFETY REVIEW): 1. ESP32 OFF / reset / boot / crash / watchdog → GPIO27 floating → R78 pull-up +3V3 → LED PC817 MATI → Q20 OFF (R71) → K1 OFF (fail-safe) 2. GPIO27 stuck-HIGH (fault MCU) → LED mati (aktif-LOW!) → Q20 OFF → K1 OFF 3. Rail 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
TOPOLOGI R1+R2 (FIX 2026-09-05) — KONTRAK FIRMWARE AKTIF-LOW: E-STOP MEMUTUS SISI SUPPLAI COIL — BUKAN SISI DRAIN — TIDAK DIUBAH. GPIO27 = AKTIF-LOW (kontrak EmergencyRelayDriver repo): +3V3 → R72 330R → anoda PC817; katoda → RELAY_CTRL (IO27 SINK, (3,3−1,2)/330 = 6,4 mA; IF maks PC817 50 mA). R78 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
KOMPONEN KUNCI + ITEM VERIFIKASI BOM (GATE e SAFETY REVIEW): OPT1 PC817 (DIP-4; Vce 80 V, CTR 50–300%): isolasi drive — LED: anoda dari +3V3 via R72 (domain ESP32), katoda ke RELAY_CTRL (IO27 SINK 6,4 mA — dalam rating GPIO ESP32); output C=+5V, E=R70 (DN-S6-02). Q20 AO3400A (SOT-23; 30 V/5,7 A; Vg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
PENEMPATAN (S9): rantai E-stop di zona power dekat tepi board; loop J_ESTOP pendek & jauh dari antenna ESP32; K1 kontak menjauh dari zona analog; jalur PGND source Q20 langsung ke star; D21 dekat pin coil K1; D22/D23 < 10 mm dari J_ESTOP; cluster sense Q21/R75/R76/R77/C75 dekat TP_ESTOP (sheet 11) 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
09_EMERGENCY — rantai E-stop SAFETY-CRITICAL (rev R1+R2, §57/§11.1). Drive AKTIF-LOW (R1 — kontrak firmware): +3V3 → R72 330R → OPT1 PC817 anoda; KATODA → RELAY_CTRL = GPIO27 (IO27 SINK 6,4 mA; LOW = ON); R78 10k pull-up +3V3 → boot/reset/floating = LED OFF = K1 OFF. Output opto: C=+5V → R70 100R →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

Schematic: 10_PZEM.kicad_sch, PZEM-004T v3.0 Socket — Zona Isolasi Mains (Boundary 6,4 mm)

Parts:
D30: BAV199; SOT-23
F3: 1A T 250VAC 5x20; Fuseholder_Clip-5x20mm_Littelfuse_111_Inline_P20.00x5.00mm_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
J_PZEM_AC: MAINS L/N 250VAC; TerminalBlock_Dinkle_DT-55-B01X-02_P10.00mm
M_PZEM: PZEM-004T v3.0 100A-CT; Module_PZEM_004T_Socket; not fitted
R55: 1k 1%; R_0603_1608Metric
RV3: MOV 275VAC DNP; RV_Disc_D21.5mm_W5mm_P10mm; not fitted

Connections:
+3V3: D30.2 (A); also elsewhere on the board
+5V: M_PZEM.3 (5V); also elsewhere on the board
DGND: D30.1 (K), M_PZEM.4 (GND); also elsewhere on the board
L_AC: F3.1, J_PZEM_AC.1
L_AC_FUSED: F3.2, M_PZEM.1 (L), RV3.1
N_AC: J_PZEM_AC.2, M_PZEM.2 (N), RV3.2
unnamed: M_PZEM.5 (TX), R55.1
PZEM_RX: D30.3 (K), R55.2; also elsewhere on the board
PZEM_TX: M_PZEM.6 (RX); also elsewhere on the board

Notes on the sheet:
ZONA MAINS TERISOLASI (audit §11.3 / keputusan D5): net L_AC, N_AC, L_AC_FUSED (DN-S5-04) = class MAINS_AC — DRC custom MAINS_SELV_CREEPAGE (clearance >= 6,4 mm ke SEMUA net non-MAINS_AC) + MAINS_LN_SPACING (L-N >= 6,4 mm) — rule .kicad_dru sejak S0. Lebar 0,5 mm cukup (arus sampling mA — CT ekster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
M_PZEM socket modul PZEM-004T v3.0 100A-CT (DNP rev awal — DN-S5-07): L/N (kiri, MAINS) <- L_AC_FUSED/N_AC via wiring harness socket; TTL (kanan, SELV): 5V<-+5V (~25 mA), GND->DGND, TX->R55 1k -> PZEM_RX (GPIO18), RX<-PZEM_TX (GPIO19). Modul terisolasi opto internal (audit §11.3: sisi TTL murni SEL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
PENEMPATAN (S9): seluruh zona mains di tepi board terpisah; J_PZEM_AC + F3 + RV3 + pad L/N M_PZEM dalam satu region; TIDAK ada net SELV melintasi region; routing MAINS satu layer (top), jauh dari antenna & analog. ENCLOSURE: akses servis F3 dari luar (fuse dapat diganti tanpa membuka zona lain); la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
10_PZEM — socket PZEM-004T v3.0 di zona isolasi mains (S5). J_PZEM_AC (L_AC/N_AC, Dinkle DT-55 P10 — DN-S5-06) + F3 1A slow 250VAC di jalur L + RV3 MOV 275VAC DNP -> net L_AC/N_AC/L_AC_FUSED class MAINS_AC (DN-S5-04; clearance 6,4 mm DRC custom + slot milled S9). M_PZEM (DNP, custom plts-custom:M_P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

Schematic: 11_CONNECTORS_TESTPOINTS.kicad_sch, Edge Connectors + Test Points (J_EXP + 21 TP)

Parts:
J_EXP: EXPANSION 7-PIN 2,54; PinHeader_1x07_P2.54mm_Vertical
TP_3V3: +3V3; TestPoint_Pad_D2.0mm
TP_5V: +5V; TestPoint_Pad_D2.0mm
TP_5V_RELAY: +5V_RELAY; TestPoint_Pad_D2.0mm
TP_ACS1_ADC: ACS1_ADC; TestPoint_Pad_D2.0mm
TP_ACS2_ADC: ACS2_ADC; TestPoint_Pad_D2.0mm
TP_BAT+: BAT+; TestPoint_Pad_D2.0mm
TP_CAN_H: CAN_H; TestPoint_Pad_D2.0mm
TP_CAN_L: CAN_L; TestPoint_Pad_D2.0mm
TP_EN: EN; TestPoint_Pad_D2.0mm
TP_ESTOP: E_STOP_SENSE; TestPoint_Pad_D2.0mm
TP_GND: PGND; TestPoint_Pad_D2.0mm
TP_IO0: IO0; TestPoint_Pad_D2.0mm
TP_RELAY_CTRL: RELAY_CTRL; TestPoint_Pad_D2.0mm
TP_RELAY_RET: RELAY_RET; TestPoint_Pad_D2.0mm
TP_RS485_A: RS485_A; TestPoint_Pad_D2.0mm
TP_RS485_B: RS485_B; TestPoint_Pad_D2.0mm
TP_SHUNT_K+: SHUNT_K+; TestPoint_Pad_D2.0mm
TP_SHUNT_K-: SHUNT_K-; TestPoint_Pad_D2.0mm
TP_UART_RX: UART0_RX; TestPoint_Pad_D2.0mm
TP_UART_TX: UART0_TX; TestPoint_Pad_D2.0mm
TP_VBAT: VBAT_DIV; TestPoint_Pad_D2.0mm

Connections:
+3V3: J_EXP.1, TP_3V3.1; also elsewhere on the board
+5V: TP_5V.1; also elsewhere on the board
+5V_RELAY: TP_5V_RELAY.1; also elsewhere on the board
ACS1_ADC: TP_ACS1_ADC.1; also elsewhere on the board
ACS2_ADC: TP_ACS2_ADC.1; also elsewhere on the board
BAT+: TP_BAT+.1; also elsewhere on the board
CAN_H: TP_CAN_H.1; also elsewhere on the board
CAN_L: TP_CAN_L.1; also elsewhere on the board
DGND: J_EXP.2; also elsewhere on the board
EN: TP_EN.1; also elsewhere on the board
E_STOP_SENSE: TP_ESTOP.1; also elsewhere on the board
GPIO13: J_EXP.3; also elsewhere on the board
GPIO23: J_EXP.4; also elsewhere on the board
GPIO33: J_EXP.5; also elsewhere on the board
GPIO36: J_EXP.6; also elsewhere on the board
GPIO39: J_EXP.7; also elsewhere on the board
IO0: TP_IO0.1; also elsewhere on the board
PGND: TP_GND.1; also elsewhere on the board
RELAY_CTRL: TP_RELAY_CTRL.1; also elsewhere on the board
RELAY_RET: TP_RELAY_RET.1; also elsewhere on the board
RS485_A: TP_RS485_A.1; also elsewhere on the board
RS485_B: TP_RS485_B.1; also elsewhere on the board
SHUNT_K+: TP_SHUNT_K+.1; also elsewhere on the board
SHUNT_K-: TP_SHUNT_K-.1; also elsewhere on the board
UART0_RX: TP_UART_RX.1; also elsewhere on the board
UART0_TX: TP_UART_TX.1; also elsewhere on the board
VBAT_DIV: TP_VBAT.1; also elsewhere on the board

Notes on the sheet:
J_EXP — HEADER EKSPANSI 7-PIN 2,54 (M5 audit): 1=3V3 · 2=GND (DGND, zona digital — konsisten J_PROGRAM/J_I2C_EXP) · 3=GPIO13 · 4=GPIO23 · 5=GPIO33 (ADC1, bidirectional) · 6=GPIO36/SENSOR_VP · 7=GPIO39/ SENSOR_VN. GPIO36 & GPIO39 = INPUT-ONLY (ADC1) — firmware DILARANG drive-out; semua kanal ADC eks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
TEST POINT — POWER (5/21)
TEST POINT — ANALOG (5/21)
TEST POINT — KONTROL/SAFETY (5/21)
TEST POINT — KOMUNIKASI (6/21)
KONVENSI & PENEMPATAN TP (layout S9): Pad bulat SMD D2,0 mm bare-copper (TestPoint_Pad_D2.0mm — DN-S7-05); pitch antar-TP >= 2,54 mm; TIDAK di bawah komponen / modul M1 / RSH1; tersebar per zona mengikuti sheet asal netnya. TP_GND = PGND star (BATTERY-) — referensi umum DMM (DN-S7-02; AGND/ DGND eq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
INVENTARIS CONNECTOR TEPI §40 + M5 (1/2) — SEMUA hadir (netlist proof): J_BAT — 2-pin 5,08 (BAT+/BAT-) — sheet 01 — feed suplai elektronik ~65 mA J_SHUNT — 2 pad baut M5 DALAM footprint RSH1 (BATTERY- star / SYS- 100 A) — 03 J_ACS1 — 2-pin >= 30 A (ACS1 IP+/IP-) — 05 — jalur force pour dua sisi J_A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
INVENTARIS (2/2) + CATATAN M5: J_PROGRAM — header 6-pin 2,54 (3V3/GND/TX/RX/EN/IO0) — 02 J_EXP — header 7-pin 2,54 (3V3/GND/GPIO13/23/33/36/39) — 11 (sheet ini) J_I2C_EXP — header 4-pin 2,54 (3V3/GND/SDA/SCL) — 06 J1 — USB-C 16-pin (VBUS_5V/DP/DM + CC 5,1k) — 02 — VBUS TIDAK = +5V J_RS485 — 3-pin 5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
CHECKLIST GATE S7 — §40 + §41 + M5 (target 100% hijau): §40/M5 CONNECTOR (13/13 hadir — netlist proof): J_BAT(01) · J1 USB-C(02) · J_PROGRAM(02) · J_SHUNT = pad baut M5 dalam RSH1(03) · J_ACS1(05) · J_ACS2(05) · J_I2C_EXP(06) · J_RS485(07) · J_CAN(08) · J_ESTOP(09) · J_RELAY(09) · J_PZEM_AC(10) · J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
11_CONNECTORS_TESTPOINTS — inventaris connector tepi §40 + 21 test point §41 + audit M5 (S7). KOMPONEN BARU: J_EXP header 7-pin 2,54 (3V3/GND/GPIO13/23/33/36/39 — M5 audit; kontrapart 5 label dangling terakhir GPIO13/23/33/36/39 -> ERC 0 error, 0 dangling — S8-ready) + 21 TP pad bulat SMD D2,0 mm (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

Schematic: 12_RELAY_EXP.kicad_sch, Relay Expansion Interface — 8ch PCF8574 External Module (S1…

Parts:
D24, D25: SMAJ5.0A; D_SMA; not fitted
F4: 1.1A hold; Fuse_1812_4532Metric
FB2: 600R@100MHz; L_0805_2012Metric
J_RELAY_EXP: RELAY EXP 5V/GND/SDA/SCL/INT; PinHeader_2x03_P2.54mm_Vertical
Q22, Q23: BSS138; SOT-23
R79, R84: 4.7k 1%; R_0603_1608Metric
R82: 10k 1%; R_0603_1608Metric
R83: 15k 1%; R_0603_1608Metric

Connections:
+3V3: Q22.1 (G), Q23.1 (G); also elsewhere on the board
+5V: F4.1; also elsewhere on the board
+5V_RELAY_EXP: FB2.2, J_RELAY_EXP.1, R79.1, R84.1
/12_RELAY_EXP/RELAY_EXP_INT: R82.2, R83.1
I2C_SCL: Q23.2 (S); also elsewhere on the board
I2C_SDA: Q22.2 (S); also elsewhere on the board
unnamed: D24.2 (A2), J_RELAY_EXP.3, Q22.3 (D), R79.2
unnamed: D25.2 (A2), J_RELAY_EXP.5, Q23.3 (D), R84.2
unnamed: F4.2, FB2.1
unnamed: J_RELAY_EXP.6, R82.1
PGND: D24.1 (A1), D25.1 (A1), J_RELAY_EXP.2, J_RELAY_EXP.4, R83.2; also elsewhere on the board

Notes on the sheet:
S12 — RELAY EXPANSION INTERFACE (8-KANAL, PCF8574 EKSTERNAL). Sumber kontrak: docs/RELAY_INTEGRATION_ARCHITECTURE.md §2.2 + docs/ RELAY_GPIO_HARDWARE_CONTRACT.md (PCF8574 0x20, aktif-LOW, boot 0xFF = semua OFF; SDA/SCL shared GPIO21/22 — TANPA GPIO baru; INT tidak dipakai v1, disiapkan untuk readba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
PINOUT J_RELAY_EXP (2x03, PinHeader_2.54 vertikal): Pin 1 = +5V_RELAY_EXP Pin 2 = PGND Pin 3 = I2C_SDA_5V Pin 4 = PGND Pin 5 = I2C_SCL_5V Pin 6 = RELAY_EXP_INT_5V GND pin ganda (2/4) mereduksi loop arus koil pada kabel ribbon. VERIFIKASI ACCEPTANCE (item TEST_PLAN S12): 1. Bus 3V3 tetap berfungsi (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
12_RELAY_EXP — antarmuka ekspansi relai 8-kanal (S12; arsitektur §2.2). +5V -> F4 1,1A -> FB2 600R -> +5V_RELAY_EXP -> J_RELAY_EXP (2x03). I2C: bus 3V3 global (SDA/SCL) -> BSS138 Q22/Q23 -> sisi 5V (R79/R84 4k7 pull-up +5V_RELAY_EXP) -> J.3/J.5. TVS D24/D25 DNP. INT J.6 -> R82/R83 0,6 -> RELAY_EXP_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

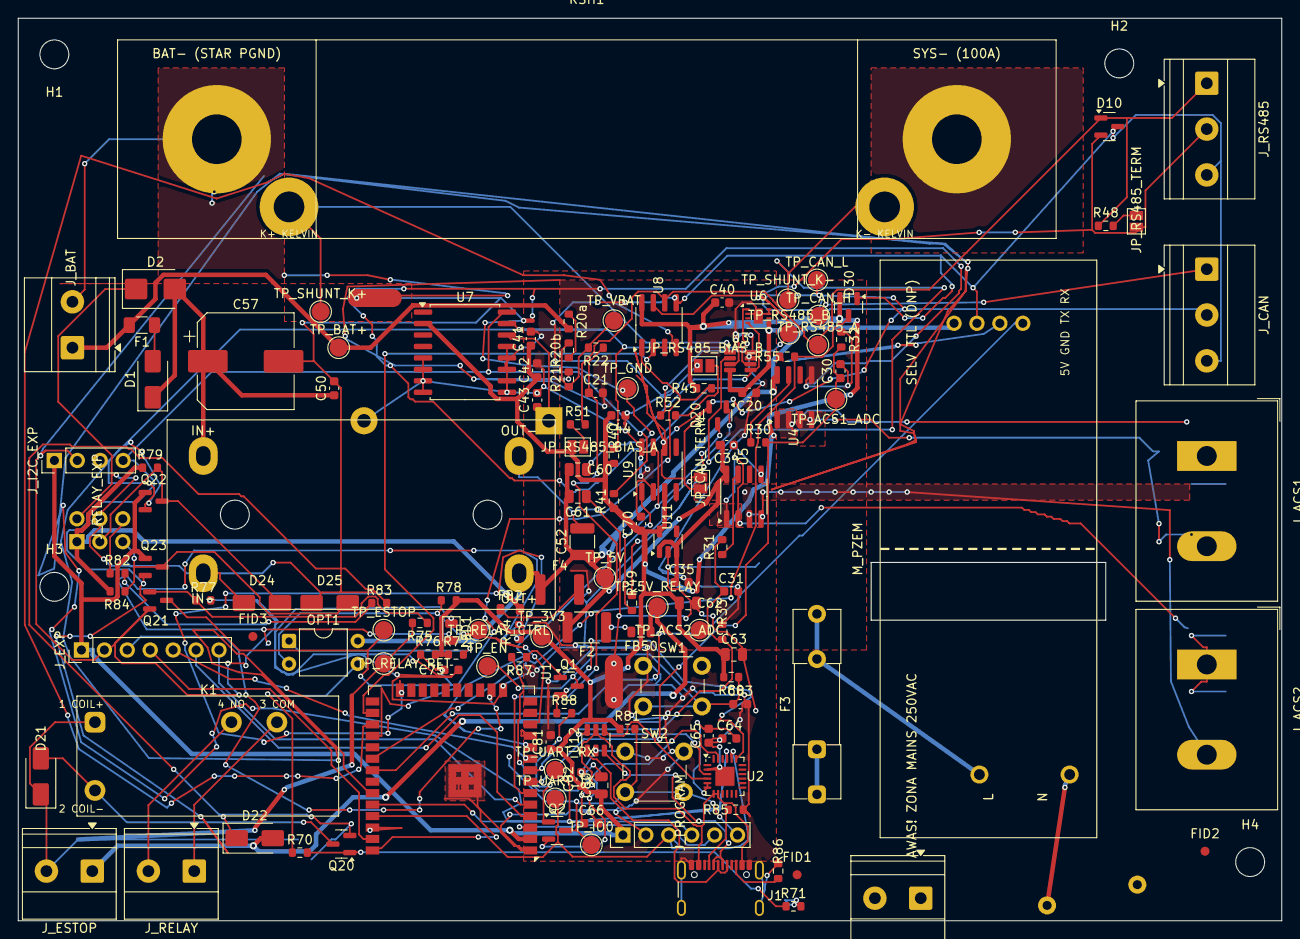
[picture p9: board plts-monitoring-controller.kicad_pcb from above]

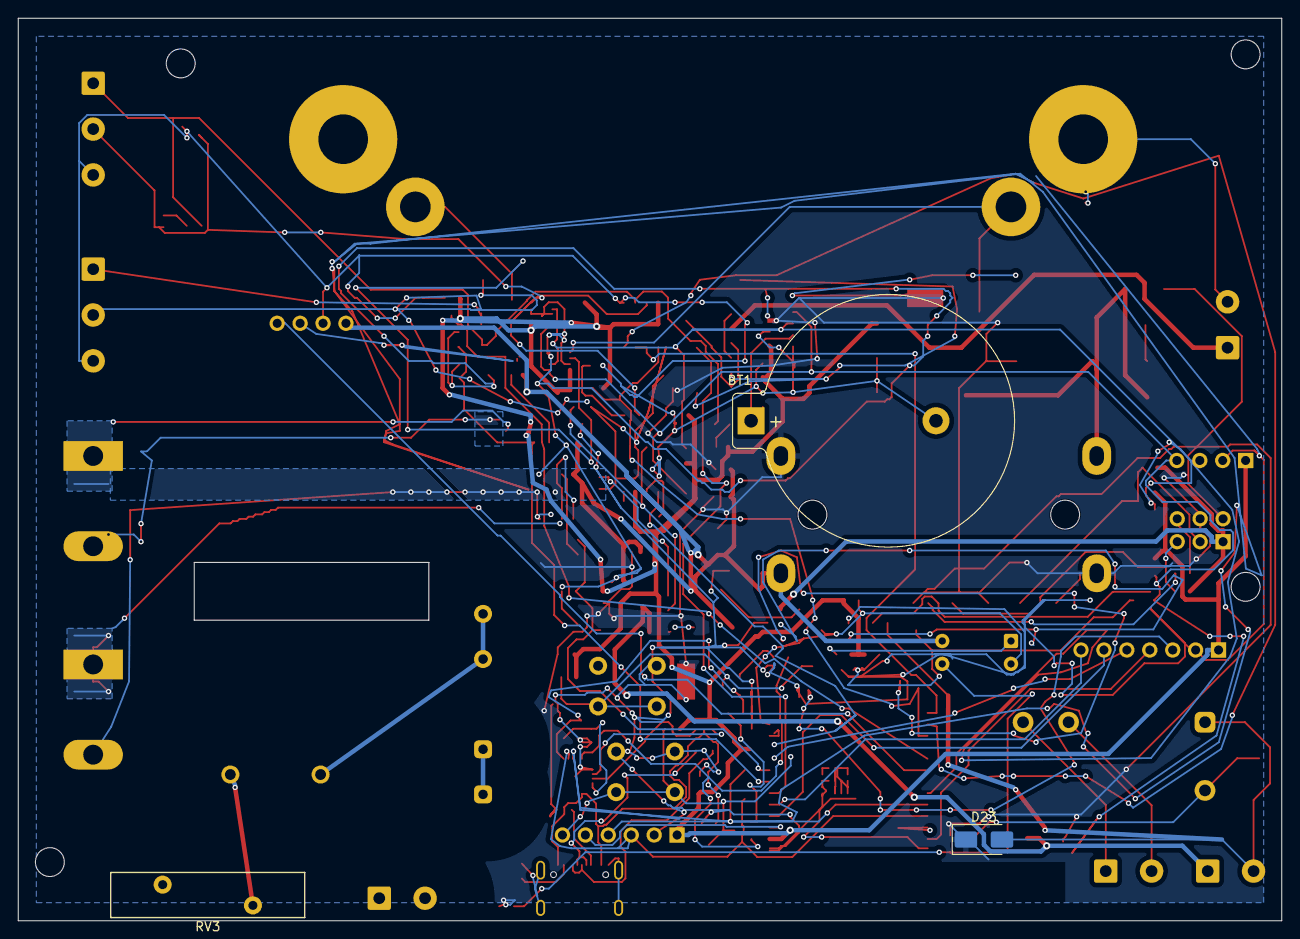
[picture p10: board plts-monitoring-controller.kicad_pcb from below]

Board: 2 copper layers, 140.0 x 100.0 mm, 152 parts (3 on the bottom side), 85 nets.

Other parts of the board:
FID1, FID2, FID3: Fiducial_1mm_Mask2mm
H1, H2, H3, H4: MountingHole_3.2mm_M3

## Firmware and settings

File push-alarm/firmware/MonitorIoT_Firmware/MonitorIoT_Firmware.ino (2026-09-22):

/*
 * =====================================================================
 * [DEPRECATED — SURFACE F18, status 2026-09-22] ========================
 * =====================================================================
 * Permukaan ini berstatus DEPRECATED pada registry tata kelola permukaan
 * (docs/surface-governance/SURFACE-STATUS.json, surface id:
 * push-alarm-firmware-monitoriot).
 *
 * Alasan: basis kode ekosistem MonitorIoT (greenhouse) yang berjalan
 * PARALEL dengan jalur PLTS aktif. Tidak menerima:
 *   - kontrak identitas (device_key, sequence) + ledger gap [P1-00x]
 *   - autentikasi HMAC-SHA256 kontrak v2.1 (code.gs/)
 *   - OTA bertanda-tangan + rollback (firmware-generic/)
 * Perbaikan keamanan di permukaan PLTS AKAN TIDAK sampai ke sini.
 *
 * Perubahan apa pun pada berkas di bawah direktori ini DITOLAK oleh
 * scripts/check_surface_policy.py (content pin SHA-256) sampai pin
 * diperbarui secara eksplisit di registry — tidak ada modifikasi senyap.
 * Pengganti: firmware-generic/ (kanal GAS PLTS) atau firmware/ (REST+MQTT).
 * Lihat docs/surface-governance/SURFACES.md untuk keputusan migrasi.
 * =====================================================================
 */

/*
 * MonitorIoT_Firmware.ino - Firmware ESP32 untuk ekosistem MonitorIoT
 * =====================================================================
 * Peran dalam arsitektur (kontrak Tabel 11 - Ambang alarm FW-GAS):
 *
 *   FIRMWARE  = pemasok data: baca sensor, evaluasi ambang LOKAL,
 *               kirim laporan berkala (flag alarm level, bukan event)
 *               ke endpoint `ingest` Google Apps Script (GAS).
 *   GAS       = pemilik keputusan kirim: deteksi tepi naik (rising
 *               edge) per sensor -> push Web Push ke PWA SEKALI per
 *               kejadian alarm.
 *   PWA       = penerima alarm push + dashboard.
 *
 * PRINSIP PENGIRIM TUNGGAL (anti dobel-kirim):
 *   Firmware TIDAK PERNAH memanggil endpoint push (subscribe/testPush/
 *   sendAlarmToAll). Firmware hanya melaporkan STATUS level (alarm
 *   true/false) setiap siklus laporan. Ketika kondisi alarm bertahan
 *   (beberapa laporan berturut-turut alarm=true), GAS tidak mengirim
 *   push tambahan - hanya tepi naik false->true yang memicu push.
 *   Alarm lokal (LED + buzzer) tetap berbunyi kontinu sesuai kondisi,
 *   karena indikator lokal adalah kanal terpisah dari push.
 *
 * Skema laporan ingest (kontrak FW-GAS):
 *   POST {GAS_URL}
 *   Content-Type: application/json
 *   {
 *     "action": "ingest",
 *     "token": "<token perangkat>",
 *     "device": { "id": "...", "fw": "1.0.0", "uptimeMs": 123456 },
 *     "sensors": [
 *       { "name": "Suhu Greenhouse 1", "value": 41.2, "unit": "C",
 *         "alarm": true, "severity": "critical",
 *         "status": "suhu 41.2 C > ambang 40.0 C" },
 *       ...
 *     ],
 *     "reportedAt": 1724900000000
 *   }
 *
 *   Respons GAS: { "ok": true, "triggered": ["ALM-..."],
 *                 "resolved": ["ALM-..."], "pushes": {...} }
 *
 * Kebutuhan pustaka (Arduino Library Manager):
 *   - ArduinoJson        (v6 atau v7; jika v7, StaticJsonDocument masih
 *                         tersedia sebagai alias JsonDocument)
 *   - DHT sensor library (Adafruit) + Adafruit Unified Sensor
 *     (hanya bila SENSOR_MODE_DHT22 aktif)
 *
 * Kebutuhan inti papan (board core): arduino-esp32 >= 2.0.4
 *   (setCACert ganda untuk verifikasi rantai Google Trust Services;
 *   v1.1.0: verifikasi TLS aktif secara default).
 *
 * Riwayat versi:
 *   1.0.0  - rilis awal (audit silang).
 *   1.1.0  - keamanan: verifikasi sertifikat TLS root CA Google (GTS
 *            Root R1 + R4) aktif default; setInsecure kini opt-in
 *            lewat TLS_SKIP_CERT_VERIFY untuk jaringan ber-proxy.
 *
 * Mode uji tanpa perangkat keras:
 *   - Biarkan SENSOR_MODE_SIMULATED aktif: nilai sensor simulasi
 *     random-walk di sekitar SIM_*_CENTER sehingga seluruh rantai
 *     FW -> GAS -> push -> PWA dapat diuji dari meja tanpa ESP32
 *     terpasang di lapangan. Naikkan SIM_TEMP_CENTER di atas ambang
 *     untuk memicu alarm sungguhan dari sisi firmware.
 */

#include <WiFi.h>
#include <HTTPClient.h>
#include <ArduinoJson.h>
#include <time.h>

/* ======================= MODE SENSOR ======================= */
// Pilih SATU: (aktifkan salah satu, yang lain dikomentari)
#define SENSOR_MODE_SIMULATED 1
// #define SENSOR_MODE_DHT22 1

#if defined(SENSOR_MODE_SIMULATED) && defined(SENSOR_MODE_DHT22)
#error "Pilih hanya SATU mode sensor."
#endif

/* ======================= KONFIGURASI ======================= */

// Versi firmware (dikirim sebagai device.fw ke GAS; naikkan setiap
// perubahan perilaku agar jejak laporan di GAS bisa dibedakan).
#define FW_VERSION "1.1.0"

// -- WiFi --
const char* WIFI_SSID = "GANTI_NAMA_WIFI";
const char* WIFI_PASS = "GANTI_PASSWORD_WIFI";

// -- Endpoint GAS (URL deployment Web App, sama dengan API_BASE PWA) --
const char* GAS_URL =
  "https://script.google.com/macros/s/AKfycbxGANTI_DENGAN_ID_DEPLOYMENT_ANDA/exec";

// -- Token perangkat: harus sama dengan Script Properties GAS
//    (FW_DEVICE_TOKEN, atau daftar FW_DEVICE_TOKENS untuk banyak perangkat).
//    JANGAN di-commit ke repositori publik.
const char* DEVICE_ID    = "esp32-greenhouse-01";
const char* DEVICE_TOKEN = "GANTI_TOKEN_PERANGKAT";

// -- Interval & batas waktu --
const uint32_t REPORT_INTERVAL_MS = 60000UL;  // laporan rutin tiap 60 detik
const uint32_t HTTP_TIMEOUT_MS    = 15000UL;  // batas waktu POST ke GAS
const uint32_t WIFI_TIMEOUT_MS    = 20000UL;  // batas waktu join WiFi
const uint32_t MAX_BACKOFF_MS     = 480000UL; // backoff maksimum 8 menit
const uint32_t NTP_TIMEOUT_MS     = 10000UL;

// -- Ambang alarm LOKAL (harus konsisten dengan THRESHOLDS di
//    PushService.gs agar evaluasi fallback GAS sejajar) --
const float TEMP_MAX   = 40.0;  // C  -> critical bila suhu > ambang
const float SOIL_MIN   = 30.0;  // %  -> warning  bila tanah < ambang
const float HUM_MIN    = 25.0;  // %  -> warning  bila udara < ambang

// -- Simulasi (mode SENSOR_MODE_SIMULATED) --
float SIM_TEMP_CENTER = 29.5;  // naikkan > 40 untuk memicu alarm suhu
float SIM_HUM_CENTER  = 71.0;
float SIM_SOIL_CENTER = 55.0;

// -- Pin (mode DHT22) --
#define DHT_PIN     4          // GPIO data DHT22
#define DHT_TYPE    DHT22
#define SOIL_PIN    34         // ADC capacitive soil moisture (0-3.3V)
#define BUZZER_PIN  -1         // GPIO buzzer/relay, -1 = nonaktif
// LED_BUILTIN umumnya GPIO2 pada modul ESP32 DevKit.

// -- Keamanan TLS --
// Default: verifikasi rantai sertifikat GAS terhadap root CA Google
// (GTS Root R1 + R4, di bawah). Aktifkan baris berikut HANYA bila
// jaringan Anda memasang proxy yang memutus TLS (hotspot captive,
// firewall sekolah/kantor) - koneksi menjadi rentan MITM:
// #define TLS_SKIP_CERT_VERIFY 1

/* ======================= STATUS INTERNAL ======================= */

// Catatan: float NAN dipakai sebagai penanda gagal baca sensor.
float lastTempC    = NAN;      // suhu terakhir (C)
float lastHumPct   = NAN;      // kelembapan udara (%)
float lastSoilPct  = NAN;      // kelembapan tanah (%)

bool  wifiOk        = false;
bool  ntpOk         = false;
uint32_t lastReportMs    = 0;     // waktu laporan terakhir (millis)
uint32_t nextReportAtMs  = 0;     // jadwal laporan berikutnya (millis)
uint8_t  httpFailCount   = 0;     // hitungan kegagalan beruntun
uint32_t bootMs = 0;

// Buzzer non-blocking
bool     buzzerOn      = false;
uint32_t buzzerNextToggleMs = 0;
uint32_t buzzerPeriodMs     = 0;

#ifdef SENSOR_MODE_DHT22
#include <DHT.h>
DHT dht(DHT_PIN, DHT_TYPE);
#endif

/* ======================= ROOT CA GOOGLE (TLS) ======================= */
/* Dihasilkan otomatis oleh scripts/gen-tls-ca-embed.js dari
 * https://pki.goog/roots.pem (Google Trust Services). Jangan edit manual. */
const char* GTS_ROOT_R1 =
  "-----BEGIN CERTIFICATE-----\n"
  "MIIFVzCCAz+gAwIBAgINAgPlk28xsBNJiGuiFzANBgkqhkiG9w0BAQwFADBHMQsw\n"
  "CQYDVQQGEwJVUzEiMCAGA1UEChMZR29vZ2xlIFRydXN0IFNlcnZpY2VzIExMQzEU\n"
  "MBIGA1UEAxMLR1RTIFJvb3QgUjEwHhcNMTYwNjIyMDAwMDAwWhcNMzYwNjIyMDAw\n"
  "MDAwWjBHMQswCQYDVQQGEwJVUzEiMCAGA1UEChMZR29vZ2xlIFRydXN0IFNlcnZp\n"
  "Y2VzIExMQzEUMBIGA1UEAxMLR1RTIFJvb3QgUjEwggIiMA0GCSqGSIb3DQEBAQUA\n"
  "A4ICDwAwggIKAoICAQC2EQKLHuOhd5s73L+UPreVp0A8of2C+X0yBoJx9vaMf/vo\n"
  "27xqLpeXo4xL+Sv2sfnOhB2x+cWX3u+58qPpvBKJXqeqUqv4IyfLpLGcY9vXmX7w\n"
  "Cl7raKb0xlpHDU0QM+NOsROjyBhsS+z8CZDfnWQpJSMHobTSPS5g4M/SCYe7zUjw\n"
  "TcLCeoiKu7rPWRnWr4+wB7CeMfGCwcDfLqZtbBkOtdh+JhpFAz2weaSUKK0Pfybl\n"
  "qAj+lug8aJRT7oM6iCsVlgmy4HqMLnXWnOunVmSPlk9orj2XwoSPwLxAwAtcvfaH\n"
  "szVsrBhQf4TgTM2S0yDpM7xSma8ytSmzJSq0SPly4cpk9+aCEI3oncKKiPo4Zor8\n"
  "Y/kB+Xj9e1x3+naH+uzfsQ55lVe0vSbv1gHR6xYKu44LtcXFilWr06zqkUspzBmk\n"
  "MiVOKvFlRNACzqrOSbTqn3yDsEB750Orp2yjj32JgfpMpf/VjsPOS+C12LOORc92\n"
  "wO1AK/1TD7Cn1TsNsYqiA94xrcx36m97PtbfkSIS5r762DL8EGMUUXLeXdYWk70p\n"
  "aDPvOmbsB4om3xPXV2V4J95eSRQAogB/mqghtqmxlbCluQ0WEdrHbEg8QOB+DVrN\n"
  "VjzRlwW5y0vtOUucxD/SVRNuJLDWcfr0wbrM7Rv1/oFB2ACYPTrIrnqYNxgFlQID\n"
  "AQABo0IwQDAOBgNVHQ8BAf8EBAMCAYYwDwYDVR0TAQH/BAUwAwEB/zAdBgNVHQ4E\n"
  "FgQU5K8rJnEaK0gnhS9SZizv8IkTcT4wDQYJKoZIhvcNAQEMBQADggIBAJ+qQibb\n"
  "C5u+/x6Wki4+omVKapi6Ist9wTrYggoGxval3sBOh2Z5ofmmWJyq+bXmYOfg6LEe\n"
  "QkEzCzc9zolwFcq1JKjPa7XSQCGYzyI0zzvFIoTgxQ6KfF2I5DUkzps+GlQebtuy\n"
  "h6f88/qBVRRiClmpIgUxPoLW7ttXNLwzldMXG+gnoot7TiYaelpkttGsN/H9oPM4\n"
  "7HLwEXWdyzRSjeZ2axfG34arJ45JK3VmgRAhpuo+9K4l/3wV3s6MJT/KYnAK9y8J\n"
  "ZgfIPxz88NtFMN9iiMG1D53Dn0reWVlHxYciNuaCp+0KueIHoI17eko8cdLiA6Ef\n"
  "MgfdG+RCzgwARWGAtQsgWSl4vflVy2PFPEz0tv/bal8xa5meLMFrUKTX5hgUvYU/\n"
  "Z6tGn6D/Qqc6f1zLXbBwHSs09dR2CQzreExZBfMzQsNhFRAbd03OIozUhfJFfbdT\n"
  "6u9AWpQKXCBfTkBdYiJ23//OYb2MI3jSNwLgjt7RETeJ9r/tSQdirpLsQBqvFAnZ\n"
  "0E6yove+7u7Y/9waLd64NnHi/Hm3lCXRSHNboTXns5lndcEZOitHTtNCjv0xyBZm\n"
  "2tIMPNuzjsmhDYAPexZ3FL//2wmUspO8IFgV6dtxQ/PeEMMA3KgqlbbC1j+Qa3bb\n"
  "bP6MvPJwNQzcmRk13NfIRmPVNnGuV/u3gm3c\n"
  "-----END CERTIFICATE-----";

const char* GTS_ROOT_R4 =
  "-----BEGIN CERTIFICATE-----\n"
  "MIICCTCCAY6gAwIBAgINAgPlwGjvYxqccpBQUjAKBggqhkjOPQQDAzBHMQswCQYD\n"
  "VQQGEwJVUzEiMCAGA1UEChMZR29vZ2xlIFRydXN0IFNlcnZpY2VzIExMQzEUMBIG\n"
  "A1UEAxMLR1RTIFJvb3QgUjQwHhcNMTYwNjIyMDAwMDAwWhcNMzYwNjIyMDAwMDAw\n"
  "WjBHMQswCQYDVQQGEwJVUzEiMCAGA1UEChMZR29vZ2xlIFRydXN0IFNlcnZpY2Vz\n"
  "IExMQzEUMBIGA1UEAxMLR1RTIFJvb3QgUjQwdjAQBgcqhkjOPQIBBgUrgQQAIgNi\n"
  "AATzdHOnaItgrkO4NcWBMHtLSZ37wWHO5t5GvWvVYRg1rkDdc/eJkTBa6zzuhXyi\n"
  "QHY7qca4R9gq55KRanPpsXI5nymfopjTX15YhmUPoYRlBtHci8nHc8iMai/lxKvR\n"
  "HYqjQjBAMA4GA1UdDwEB/wQEAwIBhjAPBgNVHRMBAf8EBTADAQH/MB0GA1UdDgQW\n"
  "BBSATNbrdP9JNqPV2Py1PsVq8JQdjDAKBggqhkjOPQQDAwNpADBmAjEA6ED/g94D\n"
  "9J+uHXqnLrmvT/aDHQ4thQEd0dlq7A/Cr8deVl5c1RxYIigL9zC2L7F8AjEA8GE8\n"
  "p/SgguMh1YQdc4acLa/KNJvxn7kjNuK8YAOdgLOaVsjh4rsUecrNIdSUtUlD\n"
  "-----END CERTIFICATE-----";

/* ======================= SETUP ======================= */

void setup() {
  Serial.begin(115200);
  delay(200);
  Serial.println();
  Serial.println("=====================================================");
  Serial.println(" MonitorIoT Firmware v" FW_VERSION " (ESP32)");
  Serial.println(" Peran: pemasok data + alarm lokal. Push = GAS.");
#ifdef TLS_SKIP_CERT_VERIFY
  Serial.println(" PERINGATAN: verifikasi TLS DIMATIKAN (mode uji).");
#endif
  Serial.println("=====================================================");

  pinMode(LED_BUILTIN, OUTPUT);
  digitalWrite(LED_BUILTIN, LOW);
  if (BUZZER_PIN >= 0) pinMode(BUZZER_PIN, OUTPUT);

#ifdef SENSOR_MODE_DHT22
  dht.begin();
  Serial.println("[SENSOR] Mode DHT22 + soil capacitive aktif.");
#elif defined(SENSOR_MODE_SIMULATED)
  randomSeed(esp_random());
  Serial.println("[SENSOR] Mode SIMULASI aktif (tanpa perangkat keras).");
#endif

  wifiConnectBlocking();      // pertama kali: bloking agar cepat jelas
  syncTime();

  bootMs = millis();
  // Laporan pertama langsung dikirim, tidak menunggu interval.
  nextReportAtMs = millis();
}

/* ======================= LOOP UTAMA ======================= */

void loop() {
  ensureWifi();

  if (millis() >= nextReportAtMs) {
    reportCycle();
  }

  updateIndicators();   // LED + buzzer mengikuti kondisi alarm lokal
  delay(50);            // jeda kecil, hemat daya
}

/* ======================= SIKLUS LAPORAN ======================= */

/**
 * Satu siklus: baca sensor -> evaluasi ambang lokal -> kirim ke GAS.
 * Kegagalan kirim menaikkan backoff; data TIDAK dibuffer berlama-lama
 * (hanya dicoba ulang pada siklus berikutnya dengan bacaan segar,
 * karena data sensor basi berbahaya untuk keputusan alarm).
 */
void reportCycle() {
  readSensors();
  bool anyAlarm = evaluateLocalAlarms();  // isi flag tiap sensor
  logSensorState();

  if (sendReport()) {
    httpFailCount = 0;
    nextReportAtMs = millis() + REPORT_INTERVAL_MS;
  } else {
    httpFailCount++;
    // Backoff eksponensial: 2x, 4x, 8x ... maksimum MAX_BACKOFF_MS.
    uint32_t backoff = REPORT_INTERVAL_MS;
    for (uint8_t i = 0; i < httpFailCount && backoff < MAX_BACKOFF_MS; i++) {
      backoff *= 2;
    }
    if (backoff > MAX_BACKOFF_MS) backoff = MAX_BACKOFF_MS;
    nextReportAtMs = millis() + backoff;
    Serial.printf("[KIRIM] Gagal (%u kali beruntun). Coba lagi dalam %u detik.\n",
                  httpFailCount, (uint32_t)(backoff / 1000));
  }

  (void)anyAlarm; // alarm lokal dipakai updateIndicators via flag sensor
}

/* ======================= SENSOR ======================= */

struct SensorReading {
  const char* name;
  float value;
  const char* unit;
  bool  alarm;
  const char* severity; // "critical" | "warning" | "info"
  char  status[96];
};

SensorReading readings[3]; // diisi evaluateLocalAlarms()

void readSensors() {
#ifdef SENSOR_MODE_DHT22
  float t = dht.readTemperature();
  float h = dht.readHumidity();
  if (isnan(t)) Serial.println("[SENSOR] DHT22: gagal baca suhu");
  if (isnan(h)) Serial.println("[SENSOR] DHT22: gagal baca kelembapan");
  lastTempC  = t;
  lastHumPct = h;

  // Capacitive soil moisture: ADC mentah (kering ~3200, basah ~1300 pada 3.3V).
  int raw = analogRead(SOIL_PIN);
  const int RAW_DRY = 3200;
  const int RAW_WET = 1300;
  float soil = (float)(RAW_DRY - raw) / (float)(RAW_DRY - RAW_WET) * 100.0f;
  if (soil < 0)   soil = 0;
  if (soil > 100) soil = 100;
  lastSoilPct = soil;

#elif defined(SENSOR_MODE_SIMULATED)
  // Random-walk di sekitar nilai pusat (kisaran per siklus).
  if (isnan(lastTempC))   lastTempC  = SIM_TEMP_CENTER;
  if (isnan(lastHumPct))  lastHumPct = SIM_HUM_CENTER;
  if (isnan(lastSoilPct)) lastSoilPct = SIM_SOIL_CENTER;
  lastTempC   += ((float)(random(-80, 81)) / 100.0f);
  lastHumPct  += ((float)(random(-150, 151)) / 100.0f);
  lastSoilPct += ((float)(random(-200, 201)) / 100.0f);
#endif
}

/**
 * Evaluasi ambang LOKAL - hasilnya flag level per sensor.
 * Sengaja berbentuk LEVEL (bukan event) agar deduplikasi kejadian
 * sepenuhnya milik GAS (lihat header file: prinsip pengirim tunggal).
 * Aturan yang sama tercermin di THRESHOLDS PushService.gs sebagai
 * jaring pengaman bila firmware lama tidak mengirim flag.
 */
bool evaluateLocalAlarms() {
  bool any = false;

  // 1) Suhu
  readings[0].name = "Suhu Greenhouse 1";
  readings[0].unit = "C";
  readings[0].value = lastTempC;
  readings[0].alarm = false;
  readings[0].severity = "info";
  snprintf(readings[0].status, sizeof(readings[0].status), "-");
  if (!isnan(lastTempC)) {
    if (lastTempC > TEMP_MAX) {
      readings[0].alarm = true;
      readings[0].severity = "critical";
      snprintf(readings[0].status, sizeof(readings[0].status),
               "suhu %.1f C melebihi ambang %.1f C", lastTempC, TEMP_MAX);
    } else {
      snprintf(readings[0].status, sizeof(readings[0].status),
               "suhu %.1f C (ambang maks %.1f C)", lastTempC, TEMP_MAX);
    }
  } else {
    snprintf(readings[0].status, sizeof(readings[0].status), "sensor suhu gagal dibaca");
  }

  // 2) Kelembapan udara
  readings[1].name = "Kelembapan Udara";
  readings[1].unit = "%";
  readings[1].value = lastHumPct;
  readings[1].alarm = false;
  readings[1].severity = "info";
  if (!isnan(lastHumPct)) {
    if (lastHumPct < HUM_MIN) {
      readings[1].alarm = true;
      readings[1].severity = "warning";
      snprintf(readings[1].status, sizeof(readings[1].status),
               "kelembapan %.0f%% di bawah ambang %.0f%%", lastHumPct, HUM_MIN);
    } else {
      snprintf(readings[1].status, sizeof(readings[1].status), "-");
    }
  } else {
    snprintf(readings[1].status, sizeof(readings[1].status), "sensor kelembapan gagal dibaca");
  }

  // 3) Kelembapan tanah
  readings[2].name = "Kelembapan Tanah";
  readings[2].unit = "%";
  readings[2].value = lastSoilPct;
  readings[2].alarm = false;
  readings[2].severity = "info";
  if (!isnan(lastSoilPct)) {
    if (lastSoilPct < SOIL_MIN) {
      readings[2].alarm = true;
      readings[2].severity = "warning";
      snprintf(readings[2].status, sizeof(readings[2].status),
               "tanah %.0f%% di bawah ambang %.0f%% (perlu siram)", lastSoilPct, SOIL_MIN);
    } else {
      snprintf(readings[2].status, sizeof(readings[2].status), "-");
    }
  } else {
    snprintf(readings[2].status, sizeof(readings[2].status), "sensor tanah gagal dibaca");
  }

  for (uint8_t i = 0; i < 3; i++) {
    if (readings[i].alarm) any = true;
  }
  return any;
}

/* ======================= KIRIM LAPORAN ======================= */

/**
 * Bangun & kirim JSON ingest ke GAS.
 * true = HTTP 200 dan respons ok:true dari GAS.
 */
bool sendReport() {
  if (WiFi.status() != WL_CONNECTED) {
    Serial.println("[KIRIM] WiFi terputus - laporan ditunda.");
    return false;
  }

  WiFiClientSecure client;
#ifdef TLS_SKIP_CERT_VERIFY
  // Mode uji / jaringan ber-intersepsi TLS. JANGAN dipakai di produksi:
  // identitas server GAS tidak diverifikasi (rentan MITM).
  client.setInsecure();
#else
  // Produksi: verifikasi rantai sertifikat GAS (Google Trust Services).
  // Google melayani beberapa varian rantai (teramati langsung: GTS Root
  // R1 dan GTS Root R4), keduanya dipercaya. Membutuhkan arduino-esp32
  // core >= 2.0.4 (setCACert dapat dipanggil lebih dari sekali).
  client.setCACert(GTS_ROOT_R1);
  client.setCACert(GTS_ROOT_R4);
#endif
  HTTPClient http;
  if (!http.begin(client, GAS_URL)) {
    Serial.println("[KIRIM] URL tidak valid.");
    return false;
  }
  http.setTimeout(HTTP_TIMEOUT_MS);
  // GAS Web App menjawab POST dengan 302 -> script.googleusercontent.com;
  // tanpa mengikuti redirect, kode respons terbaca 302 dan body hilang
  // (temuan X-4 audit silang).
  http.setFollowRedirects(HTTPC_STRICT_FOLLOW_REDIRECTS);
  http.addHeader("Content-Type", "application/json");

  StaticJsonDocument<1024> doc; // ArduinoJson v6; v7: JsonDocument
  doc["action"] = "ingest";
  doc["token"]  = DEVICE_TOKEN;
  JsonObject dev = doc.createNestedObject("device");
  dev["id"]       = DEVICE_ID;
  dev["fw"]       = FW_VERSION;
  dev["uptimeMs"] = (uint32_t)(millis() - bootMs);

  JsonArray arr = doc.createNestedArray("sensors");
  for (uint8_t i = 0; i < 3; i++) {
    JsonObject s = arr.createNestedObject();
    s["name"]     = readings[i].name;
    if (!isnan(readings[i].value)) {
      // Dibulatkan 1 desimal agar payload ringkas.
      s["value"]   = roundf(readings[i].value * 10.0f) / 10.0f;
    } else {
      s["value"]   = nullptr; // null -> PWA menampilkan "--"
    }
    s["unit"]     = readings[i].unit;
    s["alarm"]    = readings[i].alarm;      // FLAG LEVEL (kontrak FW-GAS)
    s["severity"] = readings[i].severity;
    s["status"]   = readings[i].status;
  }
  doc["reportedAt"] = nowEpochMs();

  String body;
  if (serializeJson(doc, body) == 0) {
    Serial.println("[KIRIM] Gagal membangun JSON.");
    http.end();
    return false;
  }

  Serial.printf("[KIRIM] POST %s (%u byte)...\n", GAS_URL, (unsigned)body.length());
  int code = http.POST(body);

  bool ok = false;
  if (code == 200) {
    String resp = http.getString();
    StaticJsonDocument<512> ans;
    if (deserializeJson(ans, resp) == DeserializationError::Ok) {
      bool respOk = ans["ok"] | false;
      int nTrigger  = ans["triggered"].size();
      int nResolved = ans["resolved"].size();
      Serial.printf("[KIRIM] GAS ok=%d | alarm dipicu=%d, pulih=%d\n",
                    respOk ? 1 : 0, nTrigger, nResolved);
      ok = respOk;
    } else {
      Serial.println("[KIRIM] Respons GAS bukan JSON valid.");
    }
  } else {
    Serial.printf("[KIRIM] HTTP %d\n", code);
  }

  http.end();
  return ok;
}

/* ======================= JARINGAN & WAKTU ======================= */

void wifiConnectBlocking() {
  Serial.printf("[WIFI] Menghubungkan ke \"%s\"...\n", WIFI_SSID);
  WiFi.mode(WIFI_STA);
  WiFi.begin(WIFI_SSID, WIFI_PASS);
  uint32_t t0 = millis();
  while (WiFi.status() != WL_CONNECTED && millis() - t0 < WIFI_TIMEOUT_MS) {
    delay(250);
    digitalWrite(LED_BUILTIN, !digitalRead(LED_BUILTIN)); // kedip = mencari
  }
  wifiOk = (WiFi.status() == WL_CONNECTED);
  if (wifiOk) {
    Serial.printf("[WIFI] Terhubung. IP: %s\n",
                  WiFi.localIP().toString().c_str());
    digitalWrite(LED_BUILTIN, LOW);
  } else {
    Serial.println("[WIFI] Gagal - akan dicoba ulang non-blokir.");
  }
}

void ensureWifi() {
  static uint32_t lastTryMs = 0;
  if (WiFi.status() == WL_CONNECTED) { wifiOk = true; return; }
  wifiOk = false;
  if (millis() - lastTryMs > 30000UL) {   // coba ulang tiap 30 detik
    lastTryMs = millis();
    Serial.println("[WIFI] Sambungan hilang - menghubungkan ulang...");
    WiFi.disconnect();
    WiFi.begin(WIFI_SSID, WIFI_PASS);
  }
}

void syncTime() {
  // NTP untuk reportedAt yang absah (zona Asia/Jakarta, UTC+7).
  configTime(7 * 3600, 0, "pool.ntp.org", "time.google.com");
  Serial.print("[NTP] Menunggu waktu");
  uint32_t t0 = millis();
  struct tm ti;
  while (millis() - t0 < NTP_TIMEOUT_MS) {
    if (getLocalTime(&ti, 500)) break;
    Serial.print(".");
  }
  ntpOk = (time(nullptr) > 1600000000);
  Serial.println(ntpOk ? " siap." : " gagal (pakai millis sebagai fallback).");
}
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

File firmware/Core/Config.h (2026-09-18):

#ifndef PLTS_CONFIG_H
#define PLTS_CONFIG_H

#include <cstdint>
#include <cstddef>

//=============================================================================
// PLTS Monitor — Configuration Header
// Production-Grade 48V LiFePO4 PLTS Monitoring System
// Brief §2-9, §71-73, §98
//
// Phase 13-B (RC-6): All constants wrapped in `namespace Core` so that
// `Core::INA219_SHUNT_OHM` etc. resolve correctly across the codebase.
// Phase 13-B (RC-12): Compile-time constants (immutable hardware specs) are
// distinguished from runtime cfg* globals (mutable, persisted, loaded by
// ConfigStore at boot). See Globals.h for cfg* extern declarations.
//=============================================================================

// ---------------------------------------------------------------------------
// v1.6.0 — BMS/INVERTER COMMUNICATION FEATURE FLAGS
// Each protocol module compiles out entirely when disabled (RAM/flash budget:
// the spool was already trimmed to 4 slots — every KB counts). Override per
// environment in platformio.ini. Defaults below apply when the build does not
// pass -D flags (e.g. Arduino IDE).
// ---------------------------------------------------------------------------
#ifndef PLTS_ENABLE_BMS_COMM
#define PLTS_ENABLE_BMS_COMM 1        // master switch for the whole layer
#endif
#ifndef PLTS_ENABLE_PYLONTECH_CAN
#define PLTS_ENABLE_PYLONTECH_CAN 1   // TWAI @500k + SN65HVD230
#endif
#ifndef PLTS_ENABLE_MODBUS_RTU
#define PLTS_ENABLE_MODBUS_RTU 1      // UART2 + MAX3485 RS485
#endif
#ifndef PLTS_ENABLE_MODBUS_TCP
#define PLTS_ENABLE_MODBUS_TCP 1      // WiFi client polling
#endif
#ifndef PLTS_ENABLE_PYLONTECH_RS485
#define PLTS_ENABLE_PYLONTECH_RS485 0 // RESERVED — console protocol slot (not
#endif                                 // implemented; see README §RS485-console)

// v1.7.0 — RS485 vendor-frame CAPTURE console (bench tool for the reserved
// Pylontech RS485 slot). Strictly passive (DE pinned LOW, never transmits);
// runtime-activated ONLY via cfgBmsProtocol = "rs485_console".
#ifndef PLTS_ENABLE_RS485_CONSOLE
#define PLTS_ENABLE_RS485_CONSOLE 1
#endif

// ---------------------------------------------------------------------------
// v1.7.0 — E-WAVE EMERGENCY CONTROL LAYER (ported from firmware-generic)
// Relay + E-stop + GAS command polling. When enabled, this firmware is no
// longer purely monitoring-only: it drives ONE safety relay whose FAIL-SAFE
// direction is ISOLATED (active-LOW module; GPIO Hi-Z at reset/crash =
// de-energized = isolated). When disabled (0), the module compiles out and
// the system behaves exactly like v1.6.3 (monitoring-only).
// ---------------------------------------------------------------------------
#ifndef PLTS_ENABLE_EMERGENCY
#define PLTS_ENABLE_EMERGENCY 1
#endif
#ifndef PLTS_ENABLE_PZEM_AC
#define PLTS_ENABLE_PZEM_AC 0          // RESERVED — PZEM-004T AC power meter
#endif                                 // (bench-validation pending; see README §PZEM)
#ifndef PLTS_ENABLE_RELAYS
#define PLTS_ENABLE_RELAYS 1           // v1.8.0: 8-channel relay via PCF8574 I²C expander
#endif

// ---------------------------------------------------------------------------
// Build Profile Guard (brief §73) — must select exactly one
// ---------------------------------------------------------------------------
#ifndef DEVELOPMENT_BUILD
#ifndef STAGING_BUILD
#ifndef PRODUCTION_BUILD
#error "No build profile selected. Define one of: -DDEVELOPMENT_BUILD | -DSTAGING_BUILD | -DPRODUCTION_BUILD"
#endif
#endif
#endif

#if defined(DEVELOPMENT_BUILD) + defined(STAGING_BUILD) + defined(PRODUCTION_BUILD) != 1
#error "Exactly ONE build profile must be defined."
#endif

#define BUILD_PROFILE_NAME \
  (defined(PRODUCTION_BUILD) ? "production" : (defined(STAGING_BUILD) ? "staging" : "development"))

namespace Core {

// ---------------------------------------------------------------------------
// Versioning (brief §74) — single source of truth
// ---------------------------------------------------------------------------
static constexpr const char* FIRMWARE_VERSION        = "1.9.3";  // v1.9.3: reproducible build release — closes REL-03/REL-04 (build identity is now deterministic: same source commit + same pinned toolchain = byte-identical SHA-256; buildDate reports the SOURCE commit date, not the wall-clock compile time). Measurement chain is unchanged from v1.9.2: INA219 dynamic gain switching (canonical register fix), PGA ±80mV/±160mV with hysteresis 90A/100A, 190k/10k voltage divider (20:1), pga_mode telemetry, 0x0FFF/0x17FF per TI SBOS448G.
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

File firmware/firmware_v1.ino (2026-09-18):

/*
 * PLTS Monitor — Production-Grade 48V LiFePO4 PLTS Monitoring System
 * Firmware v1.0.0 — Protocol v1
 *
 * Phase 13-B: Controlled Firmware Build Recovery
 *   - RC-1 (structural): .ino is now orchestration only, not God Object
 *   - RC-2: MqttConfigReceiver, MqttOtaHandler, GasAdvisor NOT referenced
 *           (deferred to Phase 13-F). No fake stubs created.
 *   - RC-3: Include paths corrected (Network/ not Services/ for MQTT)
 *   - RC-9: Uses canonical extern instances (Drivers::ina219Battery, Drivers::batteryAdc, etc.)
 *           No local instance declarations.
 *
 * Architecture (brief §78): FreeRTOS task-based, local-first, monitoring-only.
 *   - SensorTask      : samples INA219, ADC, ACS712, SHT31 at sensor-specific rates
 *   - MeasurementTask : voltage calibration, power calc, AC RMS, dew point
 *   - EnergyTask      : Ah/Wh integration, SOC update, EFC
 *                       TODO(PHASE-13-C): RC-13 — replace wall-clock dt with monotonic
 *   - TelemetryTask   : 5s publish + spool management
 *   - NetworkTask     : WiFi/MQTT/GAS/NTP
 *   - PersistenceTask : periodic NVS save (config, energy, SOC)
 *   - HealthTask      : Services::health supervision, alarm evaluation, anomaly detection
 *   - EmergencyTask   : [v1.7.0 E-WAVE] emergency supervisor, LOCAL-FIRST 10 Hz —
 *                       relay/E-stop/trigger evaluation run regardless of WiFi
 *   - GasEmergencyTask: [v1.7.0 E-WAVE] EMERGENCY_PENDING poll + ACK + events (HMAC)
 *
 * Brief §1: "Never fabricate certainty." Every measurement has value/unit/quality/source/timestamp/sequence.
 * Brief §75: Local-first — ESP32 remains operational when Internet/MQTT/GAS/PWA all OFF.
 * Brief §102 (v1.7.0 amendment): the firmware drives exactly ONE actuator — the
 *   E-WAVE safety relay (PLTS_ENABLE_EMERGENCY, default ON) — whose fail-safe
 *   direction is ISOLATED (GPIO Hi-Z at boot/crash = de-energized). Every other
 *   subsystem remains monitoring-only. With the flag OFF, this build is
 *   byte-equivalent in behavior to v1.6.3 (pure monitoring).
 */

#include <Arduino.h>
#include <Wire.h>
#include <esp_task_wdt.h>
#include <esp_system.h>
#include <freertos/FreeRTOS.h>
#include <freertos/task.h>
#include <freertos/queue.h>
#include <Preferences.h>
// [FW-20] ExtraHandlers — PWA-contract route parity (noteBootEvent)
#include "Web/ExtraHandlers.h"
#include <LittleFS.h>
#include <ESPmDNS.h>
#include <Update.h>
#include <WiFi.h>
#include <WiFiClientSecure.h>
#include <WebServer.h>
#include <ArduinoJson.h>
#include <PubSubClient.h>
#include <time.h>

#include "Core/Config.h"
#include "Core/Types.h"
#include "Core/Common.h"

// Drivers MUST be included before Globals.h (forward-declared there)
#include "Drivers/Ina219Driver.h"
#include "Drivers/AdcVoltageDriver.h"
#include "Drivers/Acs712Driver.h"
#include "Drivers/Sht31Driver.h"
#include "Drivers/RtcDriver.h"
// v1.7.0 — E-WAVE emergency layer (ported from firmware-generic)
#if PLTS_ENABLE_EMERGENCY
#include "Drivers/EmergencyRelayDriver.h"
#endif
#if PLTS_ENABLE_PZEM_AC
#include "Drivers/Pzem004tDriver.h"   // v1.7.0 — optional real AC power meter
#endif

// Services MUST be included before Globals.h (forward-declared there)
#include "Services/VoltageCalibration.h"
#include "Services/SocStateMachine.h"
#include "Services/EnergyCounters.h"
#include "Services/AcMeasurement.h"
#include "Services/AnomalyDetector.h"
#include "Services/AlarmRegistry.h"
#include "Services/HealthSupervisor.h"
#include "Services/TelemetrySpool.h"
#include "Services/TransactionJournal.h"
#include "Services/CommandCanonicalizer.h"
#include "Services/FactoryReset.h"      // [audit p.427] shared factory-reset sweep
#include "Services/AuthManager.h"
#include "Services/OtaManager.h"
#include "Services/SecurityPosture.h"   // [AUDIT ROUND 4] eFuse posture + floor
#include "Services/LogService.h"
#include "Services/WifiManager.h"
#include "Services/TimeManager.h"
#if PLTS_ENABLE_EMERGENCY
#include "Services/EmergencySupervisor.h"
#endif

#include "Storage/FileSystem.h"
#include "Storage/ConfigStore.h"

// v1.6.0 — multi-protocol BMS/inverter communication layer
#include "Comm/BatteryProtocol.h"
#include "Comm/BatteryCommManager.h"
#if PLTS_ENABLE_RS485_CONSOLE
#include "Comm/Rs485Console.h"   // v1.7.0 — passive vendor-frame capture (bench)
#endif
#if PLTS_ENABLE_PYLONTECH_CAN
#include "Comm/PylontechCanClient.h"
#endif
#if PLTS_ENABLE_MODBUS_RTU
#include "Comm/ModbusRtuClient.h"
#endif
#if PLTS_ENABLE_MODBUS_TCP
#include "Comm/ModbusTcpClient.h"
#endif

#include "Utils/Crypto.h"
#include "Utils/Crc.h"
#include "Utils/Json.h"

#include "Network/MqttTransport.h"
#include "Network/MqttTelemetryPublisher.h"
#include "Network/MqttConfigReceiver.h"
#include "Network/MqttOtaHandler.h"
#if PLTS_ENABLE_EMERGENCY
#include "Network/GasEmergencyChannel.h"
#endif
// [PARITY-3 2026-09-06] GAS OTA_STATUS bridge — modular OTA lifecycle events
// into the GAS OtaEvents sheet (PWA authoritative OTA log). Independent of
// PLTS_ENABLE_EMERGENCY: OTA exists in every build configuration.
#include "Network/GasOtaReporter.h"
#include "AI/GasAdvisor.h"

#include "Web/HttpServer.h"
#include "Web/BatteryStatusSerializer.h"

// Globals.h LAST — after all forward-declared classes are fully defined
#include "Core/Globals.h"

// Bring driver/service/network/web instance names into scope
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

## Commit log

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2026-09-02 fix(P1/P2): audit remediation — sensor fail-closed policy + version identity + retention/OTA contracts
    P1-1 [sensor fail-closed] firmware-generic v1.7.0:
    - New 13th EMERGENCY_CONFIG_FIELDS entry: sensorFailPolicy (0/1, default 1)
    - Policy 1 (default): INA219/ACS712 are MANDATORY safety inputs —
    ARM rejected while any safety sensor absent/invalid; a sensor lost
    mid-run TRIPs SENSOR_LOSS (debounced) instead of silently disarming
    its overcurrent protection
    - Policy 0: explicit operator opt-out (bench/commissioning, documented
    unsafe for production); mixed fleets: field absent -> default 1
    - Schema sync: GAS EMERGENCY_CONFIG_FIELDS + PWA emergency.ts updated
    in lockstep (13 fields,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
    [plts_firmware_v1.ino]
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2026-09-02 feat(firmware): port E-WAVE v1.7.0 ke firmware modular — penutupan keterbatasan §13
    Lapisan kendali darurat E-WAVE (sebelumnya hanya di firmware-generic) kini
    terpasang di firmware/ (PLTS_ENABLE_EMERGENCY=1 default; 0 = perilaku
    murni-monitoring v1.6.3):
    - Drivers/EmergencyRelayDriver: relai aktif-LOW GPIO27 + E-stop NC GPIO14,
    isolasi fail-safe SEBELUM LittleFS/WiFi (paritas E1 generic)
    - Services/EmergencySupervisor: mesin RUN/EMERGENCY latch, debounce+histeresis
    6 kanal, gerbang ARM fail-closed, rantai crash NVS, lokal-dulu 10 Hz
    - Network/GasEmergencyChannel: poll EMERGENCY_PENDING 15 s via envelope HMAC
    per-perangkat (lebih kuat dari token fleet), ACK, event retry 20x,
    task k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
    [Config.h, ConfigStore.cpp, EmergencyRelayDriver.cpp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]
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2026-09-03 fix(W12-CI): tree modular gagal compile sejak port E-WAVE — 4 perbaikan + hardening urutan-include
    Build firmware/ modular rusak sejak 1780736 (job CI 'development+staging'
    merah 3 run beruntun, termasuk commit docs-only — bukan regresi W12):
    - GasEmergencyChannel.h: #include <ArduinoJson.h> hilang -> 'JsonVariantConst
    has not been declared' (deklarasi method private di header).
    - GasEmergencyChannel.cpp: #include Services/TimeManager.h hilang ->
    'timeManager is not a member of Services' (pola kanonik GasAdvisor/
    MqttTelemetryPublisher).
    - EmergencySupervisor.cpp: alarms.raise() menerima const char* — dua call
    site mengirim StringSumHelper -> .c_str() (pola VoltageCalibration).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
    [EmergencyRelayDriver.h, GasEmergencyChannel.cpp]
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2026-09-03 fix(W13): wave 13 armada campuran + OTA end-to-end — aktivasi pasca-OTA modular, target manifest, OTA_LOG
    W13-1 (HIGH): proteksi rollback OTA modular inert — markBootHealthy() tak
    pernah memanggil esp_ota_mark_app_valid_cancel_rollback() padahal
    CONFIG_BOOTLOADER_APP_ROLLBACK_ENABLE=y (sdkconfig arduino-esp32, terverifikasi)
    → tiap OTA modular kembali senyap ke versi lama pada reset pertama
    pasca-update; counter boot_att di-increment saat upload (bukan per boot)
    + jalur download tak pernah menulis → triggerRollback() dead code.
    FIX: markBootHealthyIfPending() dipanggil dari loop 1 s (jendela sehat 60 s,
    Core::OTA_HEALTHY_AFTER_MS — sejajar kriteria firmware-generic), hitung
    per boo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
    [Config.h, firmware_v1.ino, plts_firmware_v1.ino]
2026-09-03 fix(W14): bench wave — PZEM frame-protocol fix + OTA v1.7.1 rollback observability
    W14-1 PZEM-004T driver framing (found by the virtual bench BEFORE the flag
    was ever enabled): request FC 0x03 (alarm/holding area) -> FC 0x04 (input
    registers, the measurement area); response validation now checks the
    0x14 byte-count; decode starts at &_buf[3] (was &_buf[2] — the count byte);
    a legacy 24-byte frame is honestly rejected via timeout, never decoded
    shifted. Locked by scripts/test_bench_w14_pzem.js (44 checks: driver ->
    telemetry -> real Code.gs ingest -> LATEST -> PWA gasEnvelope, honesty
    under 6 fault modes, flag stays 0 until the physical pass).
    W14-2 OTA v1.7.1 rollback (verified against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
    [Pzem004tDriver.cpp, plts_firmware_v1.ino]
2026-09-03 audit-2: fix blockers + Firmware KRITIS/SEDANG + GAS hardening + cleanup
    Blockers (would have failed CI):
    - Fix getDeviceKeyForMqtt undefined reference (linker error in modular build)
    by using Core::deviceId directly in MqttTelemetryPublisher
    - Add if: guard to build-production job so PRs don't fail when production
    environment is protected
    - Remove dead ESP32_PLATFORM env var; fix if-no-files-found inconsistency
    P1-6 tuntas (lifecycle events for ALL OTA paths):
    - Emit ACCEPTED/DOWNLOADING/VERIFIED/FLASHED/FAILED in MQTT download path
    (beginDownload + tickDownload) — was REST-only, MQTT path was silent
    - Set _jobId in beginDownload so ACTIVATED/ROLLBACK events correlate to
    MQTT job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
    [AuthManager.cpp]
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2026-09-04 audit-delta: fix all P0+P1 relay correctness issues (Phase A)
    P0-1: Bump firmware version 1.7.1 → 1.8.0
    - Config.h FIRMWARE_VERSION = '1.8.0'
    - firmware-generic/src/plts_firmware_v1.ino FIRMWARE_VERSION = '1.8.0'
    - firmware-generic/manifest.json version = '1.8.0', path = plts_firmware_v1.8.0.bin
    - PWA canControlRelays now returns true for firmware ≥ 1.8.0
    - Updated test_wave13 + test_wave7_10 to use dynamic version (not hardcoded 1.7.1)
    - Removed stale plts_firmware_v1.7.1.bin from firmware-generic/bin/
    P0-2: Fix setChannel() failure propagation — I²C failure no longer produces false state
    - _applyChannelState() now checks setChannel() return value
    - If I²C write fails: reportedStat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
    [partitions_ota_1mb5.csv]
2026-09-04 fix CI: compile errors + production secrets + queue overflow 503
    FIX A (COMPILE ERROR): MqttConfigReceiver.cpp line 486
    - return { ok, code, messageOut } failed because ApplyResult.code is
    const char* but code is a String (heap-allocated). The brace-enclosed
    initializer tried to convert String to const char* implicitly.
    - Fix: return ApplyResult{ ok, code.c_str(), messageOut } — explicit
    construction with .c_str() for the const char* field.
    FIX B (COMPILE ERROR): firmware-generic .ino line 412
    - nvs_get_str(handle, key, &len, buf) had wrong argument order.
    - ESP-IDF API: nvs_get_str(handle, key, buf, &len) — buf first, then &len.
    - The old order passed size_t* where char* was expe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
    [plts_firmware_v1.ino]
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2026-09-04 fix CI: PEM certs via generated header + validation from env vars
    Root cause: multiline PEM certificates cannot be passed as -D command-line
    flags — the compiler splits on newline and sees 'macro names must be
    identifiers' errors.
    Fix:
    1. PEM certificates (MQTT_ROOT_CA, OTA_HTTPS_ROOT_CA) are written to a
    generated header file (.pio/generated/production_secrets.h) instead of
    -D flags. The header uses #define with escaped string literals.
    2. Config.h includes the generated header via __has_include (conditional —
    only if the file exists).
    3. CPPPATH is extended to include .pio/generated/ so the header is found.
    4. Validation step checks CPPDEFINES for non-PEM macros AND environme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
    [Config.h]
2026-09-04 fix CI: escape newlines in PEM header + move __has_include before #error guards
    Two issues fixed:
    1. PEM certificates in generated header had actual newlines in C string
    literals → 'missing terminating " character' error.
    Fix: escape newlines as \n in the generated header (replace '\n' with '\n').
    2. __has_include(<production_secrets.h>) was AFTER the #error guards in
    Config.h, so the guards fired before the PEM macros were defined.
    Fix: move __has_include to BEFORE the #ifdef PRODUCTION_BUILD block.
    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
    [Config.h]
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2026-09-04 feat(pcb): add PLTS monitoring controller KiCad project + custom libraries (#2)
    - 12-sheet hierarchical schematic, stages S0-S8 complete: ERC 0/0, netlist 131 components / 113 nets (pin contract matches firmware Core/Config.h)
    - 140x100mm 2-layer 2oz FR4: placement 100% complete and DRC-verified clean (0 clearance/shorting/courtyard/hole/padstack). Routing intentionally reset to clean baseline per S9 layout report (buggy draft router output ripped up, 35 design vias kept); 266 unconnected items = routing work for next stage
    - Mains isolation slot 26x6.4mm + MAINS_AC netclass w/ 6.4mm creepage DRU rule, 100A shunt power zones, PGND plane, 14 zones, 35 stitching/net-tie vias
    - Custom libraries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
    [01_POWER.kicad_sch, 02_ESP32.kicad_sch, 03_CURRENT_SHUNT.kicad_sch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]
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2026-09-05 fix(v1.9.1/INA-01): INA219 PGA register constants corrected per datasheet + readback verification + sample discard (#8)
    P0 fix: PGA constants had inverted bit-mapping (comment said 00=±320mV
    but datasheet says 00=±40mV). Both modes used PGA=11 (±320mV) — dynamic
    switching was a no-op. Corrected: 0x152B (±80mV, PGA=01), 0x252B (±160mV,
    PGA=10). BADC/SADC now use valid 12-bit/128-sample values (were RESERVED).
    Added register readback verification + sample discard after PGA switch
    (settling time) + CURRENT_SPIKE_REJECT_A documented as software ceiling.
    New unit test test_ina219_config_registers.py verifies all bit-fields.
    [Config.h, Ina219Driver.cpp]
2026-09-05 pcb: S12 relay-expansion integration + R1/R2 e-stop fixes (schematic + board)
    - 09_EMERGENCY: R1 fix (active-LOW drive: R72 high-side from +3V3, OPT1 cathode
    -> RELAY_CTRL, R78 10k pull-up fail-safe) + R2 fix (inverting sense: Q21
    BSS138 + R77 100k divider + R76 revalued 10k pull-up, C75 filter; HIGH=trip
    matches GPIO14 INPUT_PULLUP contract); truth table/docs updated
    - NEW 12_RELAY_EXP: F4 1.1A + FB2 -> +5V_RELAY_EXP rail, J_RELAY_EXP 2x03,
    BSS138 I2C shifters Q22/Q23 + R79/R84 4k7, TVS D24/D25 DNP, INT divider
    R82/R83 (PCF8574 module external, 0x20, active-LOW)
    - root sch: sheet 12 entry (page 13); plts-custom: +5V_RELAY_EXP symbol
    - pro: PWR netclass pattern for +5V_RELAY_EXP
    -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
    [01_POWER.kicad_sch, 09_EMERGENCY.kicad_sch, 12_RELAY_EXP.kicad_sch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]
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2026-09-05 fix(v1.9.2/INA-01 CANONICAL): INA219 register constants corrected per datasheet + mandatory measurement evidence (#10)
    P0: v1.9.1 bit-field layout was wrong (BRNG=14,PG=13:12,BADC=11:7,
    SADC=6:2,MODE=1:0). Correct per TI SBOS448G: BRNG=13,PG=12:11,BADC=10:7,
    SADC=6:3,MODE=2:0. Constants 0x152B/0x252B actually decoded to wrong
    PGA + triggered mode + 10-bit SADC. Corrected: 0x0FFF (±80mV) / 0x17FF
    (±160mV), both 12b/128s continuous. Datasheet reset 0x399F cross-check
    confirms layout. P0-B: 17 observed measurement fields now MANDATORY
    (missing=BLOCK, not WARN) — closes false-green path.
    [Config.h, Ina219Driver.cpp]
2026-09-05 fix(v1.9.2): bump FIRMWARE_VERSION to 1.9.2 + rename hw-acceptance docs (#11)
    Self-audit: FIRMWARE_VERSION was still 1.8.0 despite v1.9.x changes
    merged. Bumped to 1.9.2 in both modular (Config.h) + generic (.ino +
    manifest.json) trees. Renamed v1.9.1.md→v1.9.2.md + template.json with
    correct commit ref 3ec9d05. Updated verifier error messages.
    [Config.h, plts_firmware_v1.ino]
2026-09-05 feat(v1.9.3): reproducible build — closes REL-03/REL-04 (REL-04)
    Root cause: FIRMWARE_BUILD_DATE compiled from __DATE__ " " __TIME__ (wall
    clock of the compile), so every build of the same source produced a
    byte-different binary — the hw-tested SHA could never equal the released
    SHA (REL-03) and two builds from one commit never matched (REL-04).
    - firmware/Core/Config.h: FIRMWARE_BUILD_DATE now derives from
    PLTS_BUILD_DATE_STR (deterministic). __has_include picks up the generated
    header; scriptless builds fall back to a constant epoch string.
    - firmware/scripts/set_build_date.py (new, all envs via platformio.ini
    extra_scripts): resolves SOURCE_DATE_EPOCH (env var > git HEAD c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
    [Config.h, plts_firmware_v1.ino]
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2026-09-05 pcb: route S12 board (Freerouting API + A* bridges) + S10 fab outputs + docs
    - Full board routing via Freerouting 2.1.0 REST API (SSE snapshots) with
    iterative import/export cycles, plus deterministic A* bridge router
    (escape-cell validation, via grid, string-pull smoothing, selective
    ripup-reroute with no-rip heal cycles)
    - Ground architecture: PGND B.Cu pour + NT0/NT1/NT2 star-ties preserved
    (added NT2 PGND tie-down via); pour fragmentation bridged; collinear
    track merge (4394 -> ~1850 segments)
    - DRC: 0 errors / 157 warnings (silk cosmetic + starved thermals with
    routed connectivity); 13 unconnected pairs documented (mains creepage
    corridor needs interactive push-and-shove;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
    [BOM.csv, PickAndPlace.csv, plts-monitoring-controller.kicad_pcb]
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2026-09-06 feat(parity-3): close cross-layer feature gaps — INSIGHTS action, modular GAS OTA bridge, DAILY/PING parity + GAS fixes
    AUDIT 2026-09-06 (parity #3): features present in one layer but missing in
    their counterparts. All findings verified in code before fixing.
    GAS backend (code.gs/Code.gs):
    - INSIGHTS action (doPost + doGet): the PWA AiView and the firmware's
    GasAdvisor (GET + HMAC query envelope, 'contract-ready, not claim-ready'
    since WAVE-7) called an action that never existed server-side. Now:
    Gemini 2.0 Flash via UrlFetchApp, prompt built from honest telemetry rows
    (nulls stay null), strict output validation, per-device input-fingerprint
    cache, advisoryOnly/source forced ser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
    [firmware_v1.ino]
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2026-09-11 fix(production-grade): close P0/P1 audit blockers — command core, relay executor, driver, auth, storage (#28)
    * fix(production-grade): close P0/P1 audit blockers — command core, relay executor, driver, auth, storage
    COMMAND CORE (audit p.308-352, CORE-01..08):
    - CommandCanonicalizer: isFieldAllowed() now scoped to EXACT (type, action)
    tuple — relay.on no longer accepts-but-not-hashes durationMs (P1, p.309-313)
    - NEW validateCommandEnvelope(): version + transactionId + issuedAt +
    expiresAt MANDATORY on every mutation ingress (REST+MQTT+OTA)
    - Canonical grammar: NaN/Inf rejected, -0.0 normalized, reserved delimiters
    escaped (p.334-339)
    - Registry: add missing (config, device) entr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
    [AuthManager.cpp, ConfigStore.cpp]
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2026-09-12 fix(relay): close audit p.413-415 — durable transaction reconciliation
    p.413 (P1) terminal-not-terminal after ring eviction:
    - _recordTransactionResult() mirrors EVERY terminal verdict into the NVS
    TransactionJournal (authoritative); the 8-entry RAM ring is now a fast
    cache only
    - GET /api/relays/transactions/{id}: ring -> journal -> honest UNKNOWN;
    no path can answer a terminal transaction with an eternal PENDING;
    responses carry source: ring|journal for observability
    - updateAck() is CREATE-ON-DEMAND: an executor verdict racing ahead of
    the ingress journal write (queueCommand precedes storeTransaction in
    the REST handler) is still durable; a late ingress storeTransaction
    la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
    [firmware_v1.ino]
2026-09-12 fix(audit-r3): close p.418/425/427/432/434 — requestId identity, TLS variant gate, unified factory reset, honest QoS contract, honest relay.config (#32)
    * fix(audit-r3): close p.418/425/427/432/434 — requestId transport identity, TLS variant gate, unified factory reset, honest MQTT QoS contract, honest relay.config fail-closed
    - p.418 (P2): CanonicalResult.requestId; envelope allows requestId != transactionId
    (transactionId = logical/dedup key, requestId = transport attempt id, v2 fallback
    alias). REST (2 sites) + MQTT relay ingress propagate the real transport identity;
    RelayTransactionRecord + terminal journal ack + GET /transactions/{id} + QUEUED
    acks (REST + MQTT) carry it;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
    [Config.h, firmware_v1.ino]
2026-09-12 feat(security): close audit r4 device-security gaps — eFuse anti-rollback floor, fail-closed OTA provisioning gate, /api/security attestation
    Auditor round 4 (post-18af0ae) keeps two P1s: hardware-rooted
    anti-rollback (p.436) and Secure Boot/Flash Encryption provisioning
    evidence (p.437), plus hardware acceptance for the INA219 chain.
    This closes everything closable at source level:
    - Services/SecurityPosture (new): reads eFuse posture (FLASH_CRYPT_CNT
    parity, ABS_DONE_0/1, BLK3 SECURE_VERSION popcount via IDF-canonical
    APIs — verified against IDF 4.4.7 sources), maintains the epoch ledger
    in NVS 'plts_sec' (survives factory reset by design), reconciles
    ledger vs hardware floor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
    [Config.h, Ina219Driver.cpp, firmware_v1.ino]
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2026-09-13 fix(audit-r5): telemetry durability, persistence fail-closed, BMS/shunt authority, alarm safety — p.437-452 (#34)
    Closes audit round-5 findings p.437-452. 72/72 round-5 gate PASS; 30/30 regression green; dev/staging/production compile SUCCESS. See docs/AUDIT_2026_09_FOLLOWUP.md round 5.
    [AlarmRegistry.h, Config.h, ConfigStore.cpp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]
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2026-09-14 fix(audit-r6): safety-grade measurement eligibility, anomaly quality gates, atomic alarm persistence — p.453-466
    P1 fixes:
    - p.457+p.466: Measurement::isSafetyUsable() (Valid+Measured+finite) — the
    strict safety twin of isValid(); EmergencySupervisor::_readSensors() uses
    it for vbat/idc/iac so Derived/Estimated pipeline stand-ins can never
    feed trip/ARM decisions; degradation becomes NaN -> SENSOR_LOSS
    fail-closed. Dashboard contract of isValid() unchanged.
    - p.459: anomaly baselines only updated from ELIGIBLE samples, each with
    its own timestamp — rate detectors divide by elapsed-between-eligible-
    samples; valid->invalid->valid no longer raises phantom voltage-jump /
    cur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
    [AlarmRegistry.h, AnomalyDetector.h, firmware_v1.ino]
2026-09-14 fix(audit-r6): self-review hardening — NaN-proof baselines, temp rapid-rise code split, generation in diagnostics, natives in CI
    Found re-verifying PR #36 before the auditor pass:
    - p.459 self-fix: V/I baseline updates move INSIDE the isfinite guard — a
    contract-violating producer (quality=Valid, value=NaN) poisoned the rate
    baselines, blinding the jump/spike detectors for an interval (fail-safe
    direction, but the p.459 invariant was broken). Regression tests: a real
    jump/spike after a Valid+NaN sample must still be detected.
    - priming stamps _lastTempSec (temp-rise evaluated from the FIRST eligible
    pair instead of skipping one interval).
    - LATENT pre-existing bug: the temp rat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
    [AlarmRegistry.h]
2026-09-14 fix(audit-r7): AlarmRegistry cross-task serialization — p.467/p.468/p.469
    Internal mutex + locked public wrappers -> private *Unlocked()
    implementations (deadlock-free by construction); immediate NVS saves run
    INSIDE the lock so RAM mutation + blob build + write + read-back is ONE
    serialized transaction (p.468). Readers consume coherent snapshots:
    Snapshot/snapshotInto() for GET /api/alarms + telemetry envelope; find()
    is copy-out; raw-pointer accessors (getAlarm/getActiveAlarms/
    getActiveAlarmCount) REMOVED (p.469). Atomic clearIfActive() closes the
    evaluator find->check->clear TOCTOU (p.467).
    Evidence: scripts/native/verify_alarm_concurrency.cpp — REAL
    std::thread interleaving (2 writ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
    [AlarmRegistry.h, firmware_v1.ino]
2026-09-14 fix(audit-r8): status-snapshot pointer-escape — torn alarm list in /api/status + GAS payload (p.470)
    Round-8 independent audit of PR #38 (p.467/p.468/p.469): all verified
    CLOSED (lock discipline, deadlock-free lock graph, TSAN/ASAN/negative
    control reproduced locally + CI run 34807668402 log-verified).
    New finding p.470 (P2, pre-existing — NOT a PR #38 regression):
    Core::SystemStatus.activeAlarms is a pointer into publishTelemetry()'s
    static buffer; handleStatus() and GasAdvisor copied the struct under
    telemetryMutex, released it, then serialized THROUGH the aliased pointer
    — a concurrent telemetry publish could rewrite the list mid-serialization
    (torn entries: new code + old message)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
    [firmware_v1.ino]
2026-09-14 fix(audit-r9): akuisisi mutex AlarmRegistry fail-closed — p.471
    Remediasi residual p.471 (P3/P4) dari audit round-8: _lock() round-7
    bersifat fail-OPEN — bila xSemaphoreCreateMutex() gagal (OOM ekstrem
    saat boot), registry melanjutkan TANPA sinkronisasi, sehingga seluruh
    jaminan p.467/p.468/p.469 hilang justru saat sistem memasuki multi-task
    state.
    Strategi hybrid (keputusan operator):
    - begin() BOOT GUARD: kegagalan pembuatan mutex = FATAL — log Serial +
    LogService, relay darurat tetap terisolasi, halt TANPA memberi makan
    task watchdog -> panic reset TWDT ~10 s dengan reset reason tercatat
    dan crash-chain EmergencySupervisor (BOOT/CRASHLOOP). Sistem tidak
    pernah masuk multi-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
    [AlarmRegistry.h, firmware_v1.ino]
2026-09-15 fix(audit-r10): fail-open family fail-closed — p.472-p.475
    Remediasi empat temuan auditor round-10 atas f724e9c (keluarga fail-open
    di luar AlarmRegistry), pola hybrid round-9 yang telah disetujui:
    p.472 LogService: keempat getter (getActivityJson/getAuditText/
    getActivityCount/getAuditBytes) kini terkunci; writer fail-closed
    (drop-on-unavailable, perpanjangan semantik FW-24); boot guard FATAL;
    jalur kegagalan _lock() Serial-saja (anti rekursi-dir: LogService
    adalah sink log). Reader jujur: {"logs":[],"lockUnavailable":true}.
    p.473 TransactionJournal: _lock() bool fail-closed + boot guard;
    enum TransactionDecision::Unavailable (bukan Conflict/Duplicate/New —
    state tanpa pen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
    [AuthManager.cpp]
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2026-09-15 fix(audit-r11): race token factory reset p.476 — one-time confirmation atomik
    Temuan auditor round-11 (P1/OPEN atas 989ee487):
    prepareFactoryReset()/confirmFactoryReset() berjalan sepenuhnya tanpa
    serialisasi atas _factoryResetToken + _factoryResetTokenTime, padahal
    lintas task (REST web task vs MQTT network task). Dua confirm konkuren
    bisa sama-sama lolos compare sebelum salah satunya clear — token
    one-time dikonfirmasi DUA KALI, keduanya bebas masuk jalur wipe
    destruktif; prepare||confirm dapat membaca pasangan token/time robek.
    Remediasi (persis rekomendasi auditor — mutex auth yang sama):
    - prepare: _lockAuth() → generate+store → _unlockAuth(); gagal → ""
    (tidak ada token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
    [AuthManager.cpp]
2026-09-16 fix(security): remediate audit p.489–p.491 — device-side RBAC, Secure cookies + HSTS production, fail-closed NVS persistence; GAS ackToken contract (p.482)
    p.489 (RBAC boundary on the DEVICE):
    - jwtSign carries an explicit 'role' claim (operator for the web account); jwtVerify extracts it — tokens WITHOUT the claim resolve to viewer (least privilege, fail-closed)
    - AuthManager::checkAuthRole() + Web/Common.h requireRole() enforce capability AFTER authentication
    - requireRole("operator") applied to every dangerous endpoint: reboot, factory_reset prepare/confirm, config POST, calibration POST/points/acs712, relay commands + all_off, alarm acknowledge + acknowledge-all, OTA upload (role g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
    [AuthManager.cpp, ConfigStore.cpp]
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2026-09-18 fix(safety): GATE-1 atomic emergency barrier + clock fail-closed + safety-config lockdown
    Audit Phase 1-10 remediation — Safety Foundation (Gate 1). Root causes were
    verified directly on this HEAD before implementation; every fix carries a
    dedicated test.
    PH8-01 (S0 — emergency OFF not atomic vs in-flight relay ON):
    - RelayExpanderDriver: new driver-level SAFETY LATCH (std::atomic, boot=
    LATCHED) + write-mutex serialization of EVERY register mutation. The
    emergency path forceSafetyAllOff() latches ATOMICALLY FIRST, then drives
    the whole bank OFF in ONE 0xFF transaction. setChannel(ch, ON) re-checks
    the latch inside the critical region — the latch-check + I2C write pair
    is se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
    [EmergencyRelayDriver.cpp, EmergencyRelayDriver.h, RelayExpanderDriver.cpp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]
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
